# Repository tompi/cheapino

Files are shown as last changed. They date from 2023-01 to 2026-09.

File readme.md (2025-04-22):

Cheapino
========

Probably one of the cheapest split keyboards you can build.

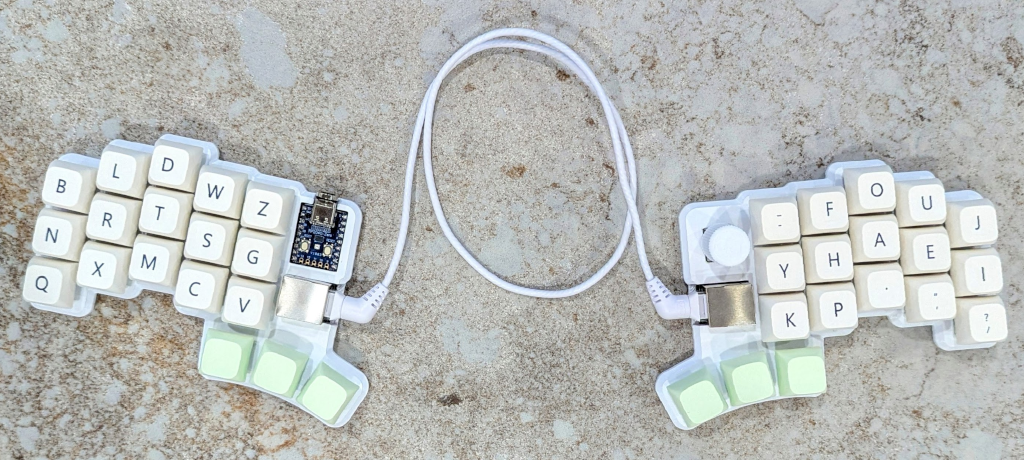
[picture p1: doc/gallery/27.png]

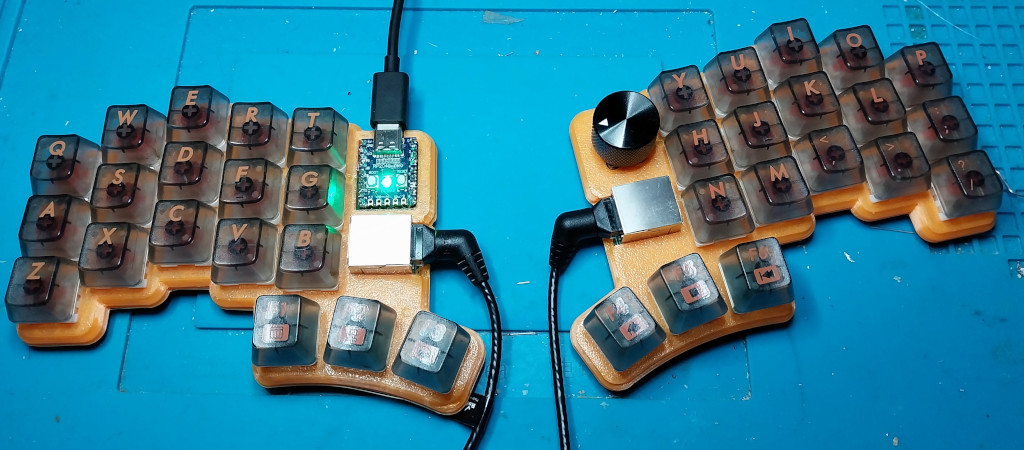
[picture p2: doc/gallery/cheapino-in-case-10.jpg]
V2 in case


This is the result of really enjoying building keyboards,
but not wanting to spend that much money on it.
The pcb is reversible, connected using rj45,
and utilizes a japanese duplex matrix, so only one
mcu is needed. For hotswap I recommend a case(pictured above),
but soldering the switches is of course the cheapest option :)

You want one?
See the [ordering guide](doc/orderingguide.md) for what you need and how to buy it.

See the [build guide v2](doc/buildguide_v2.md) for more details and pictures of how to actually build it.

Some info on the [plate/case solutions](doc/plates_and_cases.md) I know about.

Checkout the [troubleshooting guide](doc/troubleshooting.md) if your Cheapino does not work.

See the [firmware guide](doc/firmware.md) for how to build and customize keyboard firmware.
The cheapino has vial support, or you can build your own QMK to customize EVERYTHING.
Even the onboard RP2040-Zero LED is controllable by QMK...

I added [a few tips and tricks here](doc/tips.md).

[Loads of beautiful build pictures here.](doc/gallery.md)

# License

This work is licensed under a [Creative Commons Attribution license.](LICENSE.txt)

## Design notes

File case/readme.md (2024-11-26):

3D-printed compact case
=======================

If you just want to make small adjustments and generate
your own version, install openscad, and open a scad file
and press F6 to generate. Export->stl to get printable model.

Make sure you install the development snapshot, since the
last official release is hopelessly out of date...
You need to tweak some settings to be able to build
the model efficiently:
 - Go to preferences->advanced and
increase "turn off rendering at" to 3 million.
 - Go to preferences->features and check "manifold"
   - In OpenSCAD version 2024.11.01, "manifold" is under: Advanced -> 3D Rendering -> Backend
   - 

(this will enable multi-thread rendering and speed things
 up dramatically!)

For the slicer, I did not do much experimenting...
Maybe somebody into 3D printing could help me out with
the silicone bumper recesses: removing the supports in
these holes is a pain...

I used 100% infill, since its not that much difference
in time/weight, and I hope that it contributes to a more
compact and better sounding case...

Recipe for re-making this
=========================

1. Export board outline from kicad
2. Open in inkscape, select all and combine
3. For every point: mark(there will be 2) and select "join points": shft+L(shft L
4. Import in openscad
5. Export holes from kicad as svg
6. Create cutouts, and measure position from kicad
7. Import holes, just to check that positions match
8. Comment out holes, generate with F6 and export as stl
9. Import stl files in any slicer to print them

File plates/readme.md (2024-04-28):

Plates
======

The v2-cheapino-left.stl and v2-cheapino-right.stl can be used for version 2 of the Cheapino.
It should be used if you installed hotswap sockets, since you need it to hold switches in place
(they are not soldered then...)

Takes 1-2 hours pers plate to print, depending on settings.
There are holes for screws, but they are a bit narrow, so use a nail or similar,
size depending on your screws, heat it and push it slowly down to expand the screwhole.
The PCB mounting holes are M4 sized, but you probably shouldnt use the entire width.

I guess optimally, I should make a version with M2 inserts that can be melted in(TODO).

The v1 file is a simple plate for just holding the switches in place.
Its suitable for Cheapino v1. Just print 2 and turn one upside down for the other side.

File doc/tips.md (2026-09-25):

Miscellaneous tips and tricks
============================

## First-time builder tips

Building a Cheapino can be challenging for beginners. Here are some key tips based on real user experiences:

### Soldering technique
- **Always use flux** - it's not optional for clean joints, especially on the tiny MCU pins
- Heat the joint, not the solder - touch both the component pin and pad with your iron
- For the MCU: Use a fine tip, work slowly, and clean your iron frequently
- If you make a mistake, don't panic - use solder wick with flux to clean up

### Build order considerations
- Some builders recommend installing hotswap sockets first (if using them) since they're easier to access
- Test fit components before final soldering when possible
- Socket the MCU - it's much easier to replace if needed than desoldering headers

### Desoldering tips
- **Prevention is better than cure** - double-check orientation before soldering
- For desoldering small components: Add fresh solder first (with flux), then use solder wick
- For through-hole components: Use a solder sucker from one side while heating from the other
- **Be gentle** - excessive force can damage PCB traces
- If a trace gets damaged, thin wire can often bridge the connection

### Equipment recommendations
- KSGER T12 soldering iron with temperature control is excellent for beginners (~$25)
- Use chisel tips (T12-K, T12-BC2) for most work, fine conical (T12-I) only for MCU pins
- Good lighting and magnification help immensely
- Take breaks - fatigue leads to mistakes

## Crimper

Can't find that 13.37 cm long dark olive green network cable that would go
perfectly with your Rain Forest GMMK keycaps? Follow @jinchoung's tip and get a
cable crimper:

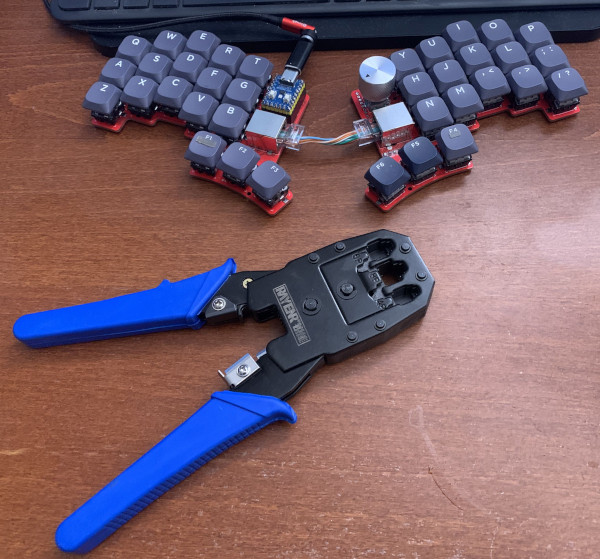
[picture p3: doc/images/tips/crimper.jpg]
Cable crimper


## LED layer indication

Want to indicate active layer using the rp2040-Zero built-in LED?
I tried this and found it a bit annoying... If you want to try, there
is some code here: https://github.com/tompi/qmk_firmware/blob/67aa22818e2be422abdb32fc918c2b6757137a4e/keyboards/cheapino/cheapino.c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
Follow the firmware guide for compiling, and uncomment the layer code above.

## Use the spare PCB as a gaming pad with a rotary encoder

PCB orders come in fives, so you'll end up with a spare half. I turned mine into a
one-handed gaming pad and wired an EC11 rotary encoder straight into the unused
RJ45 pads to use as a quick layer switcher.

The stock firmware already reads the encoder over these lines, so no firmware
changes are needed. Just wire it up and map it in Vial.

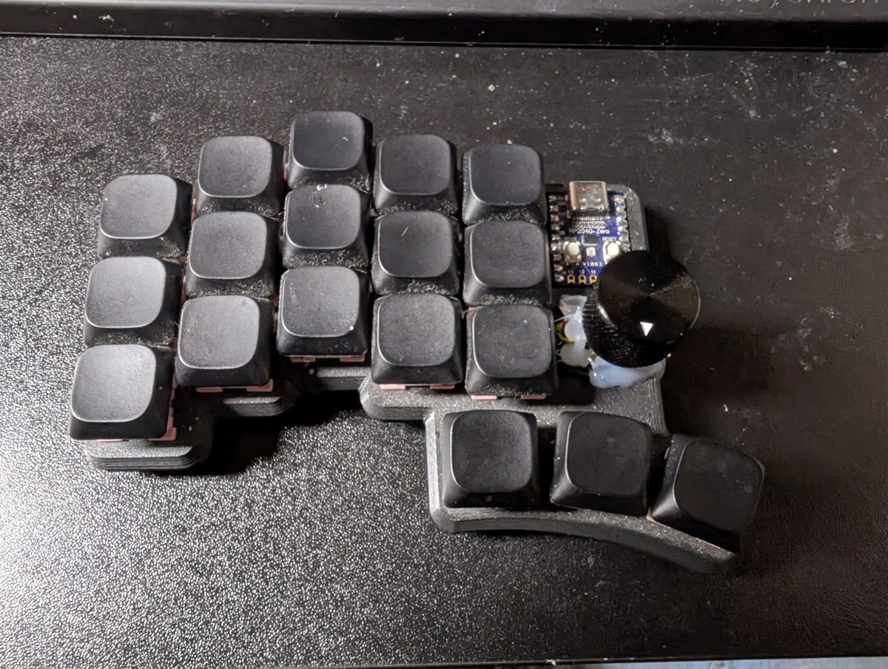
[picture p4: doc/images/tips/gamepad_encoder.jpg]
Gaming pad with encoder


Wiring, with the RJ45 pads viewed from the top and the RP2040 above them:

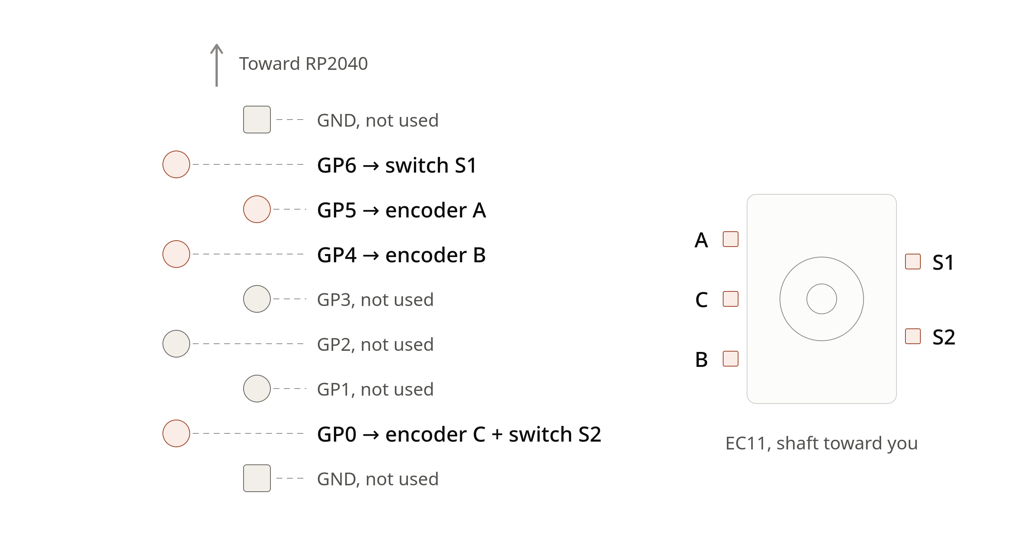
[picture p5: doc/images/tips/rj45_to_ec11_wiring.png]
RJ45 to EC11 wiring


| RJ45 pad | EC11 pin |
|---|---|
| GP6 | S1 (switch) |
| GP5 | A |
| GP4 | B |
| GP0 | C (common) and S2 (switch) |

GND, GP1, GP2 and GP3 aren't used. C and S2 share GP0, so bridge them on the
encoder side and run a single wire.

Tips:
- If the encoder turns the wrong way, just swap the clockwise/counter-clockwise
  keycodes in Vial rather than rewiring A and B.
- The EC11 is smaller than the RJ45 jack, so it fits in the same spot without
  modifying the case. A blob of hot glue holds the encoder and wires in place.
- Pairs really well with the [LED layer indication](#led-layer-indication) tip
  above. I cycle through 4 layers with the encoder and use a different LED colour
  per layer (red, green, blue, yellow) so you can tell at a glance where you are.

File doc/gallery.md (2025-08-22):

Cheapino gallery
================

Send me a picture of your Cheapino!

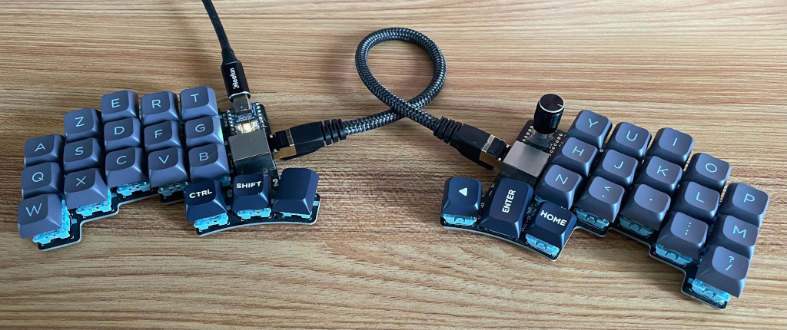
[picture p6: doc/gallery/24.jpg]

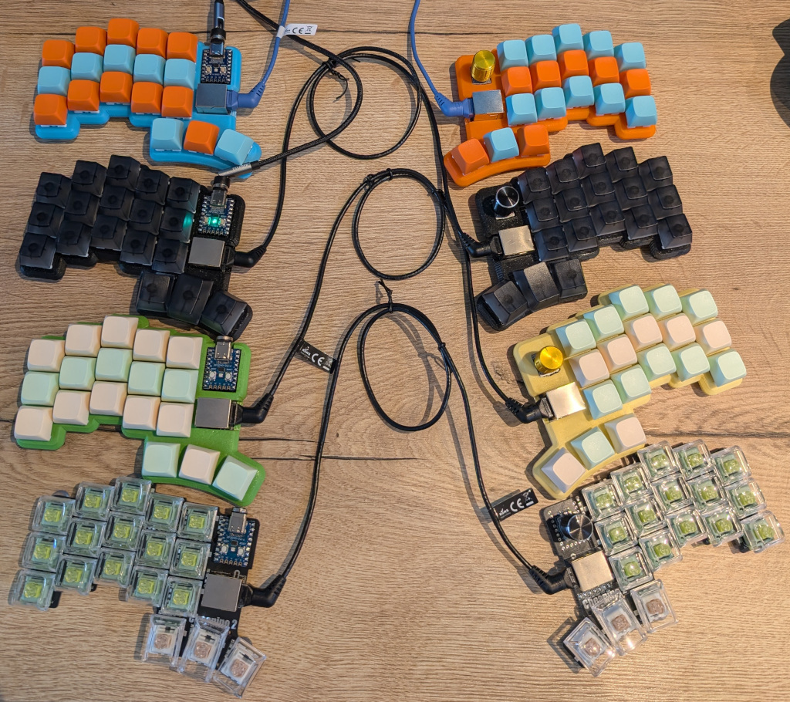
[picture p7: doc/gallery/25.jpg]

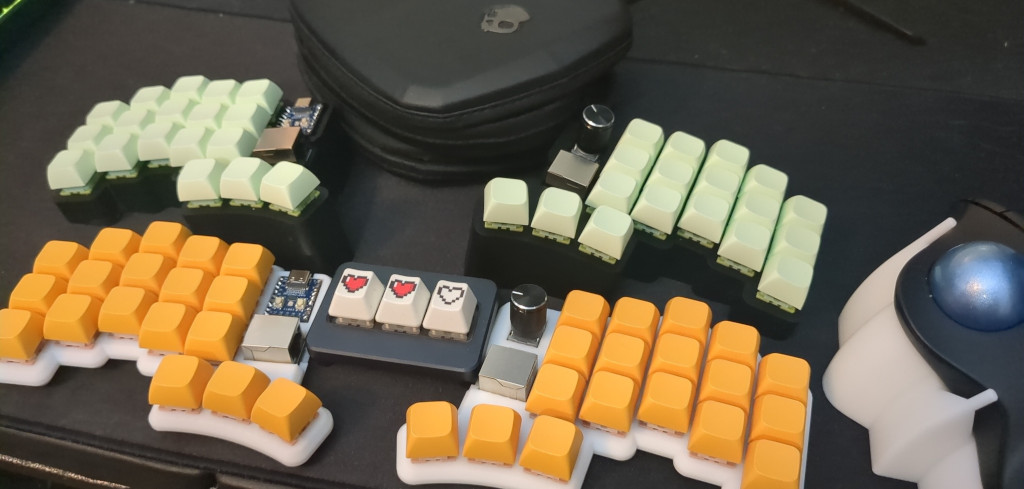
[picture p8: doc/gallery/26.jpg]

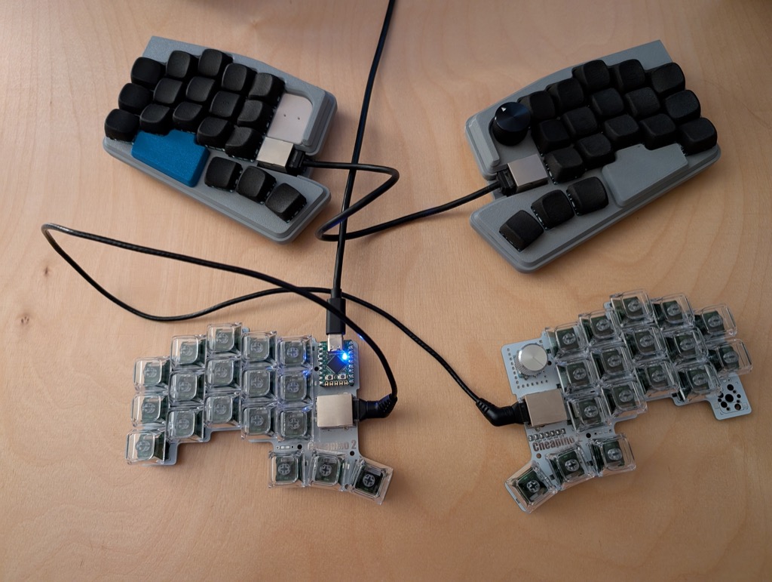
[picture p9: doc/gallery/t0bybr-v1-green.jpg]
V1 with green switches

V2
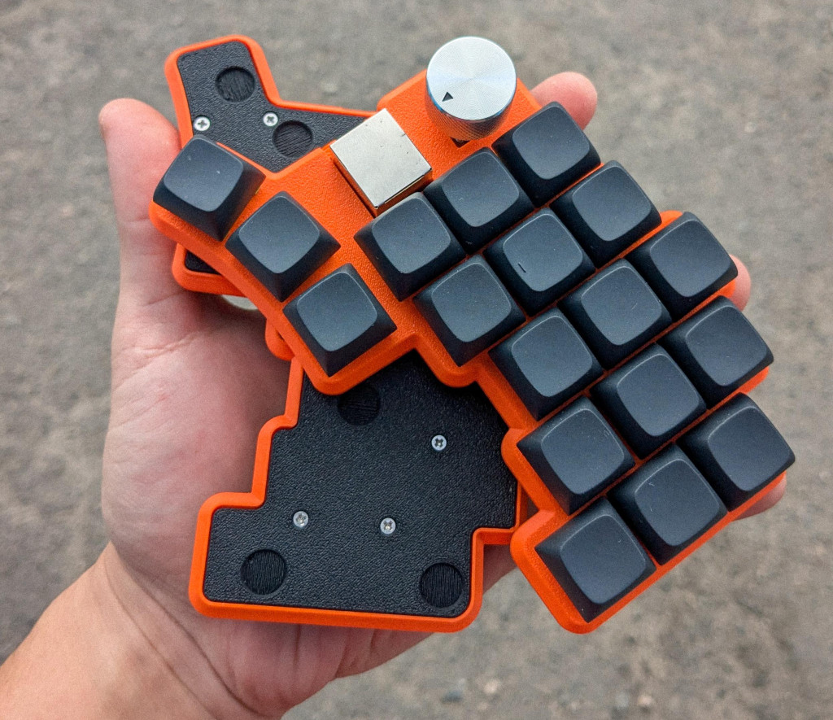
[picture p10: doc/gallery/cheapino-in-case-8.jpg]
V2 in case

V2 in case
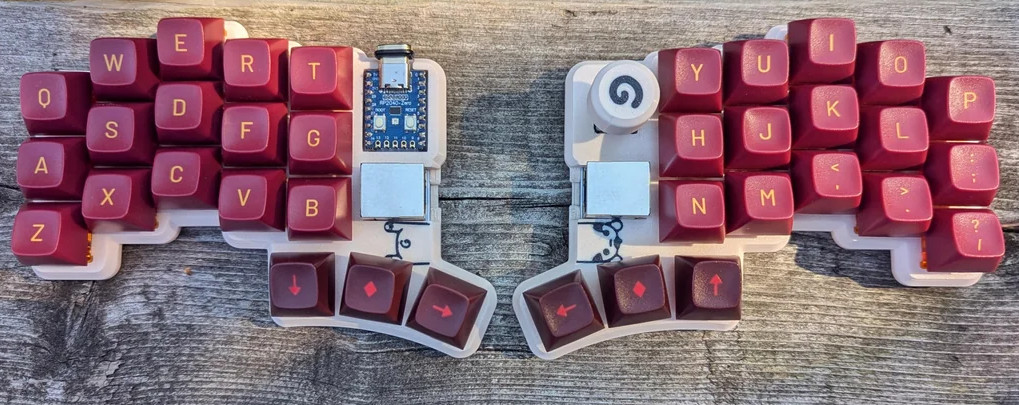
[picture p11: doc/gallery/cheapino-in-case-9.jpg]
V2 in case

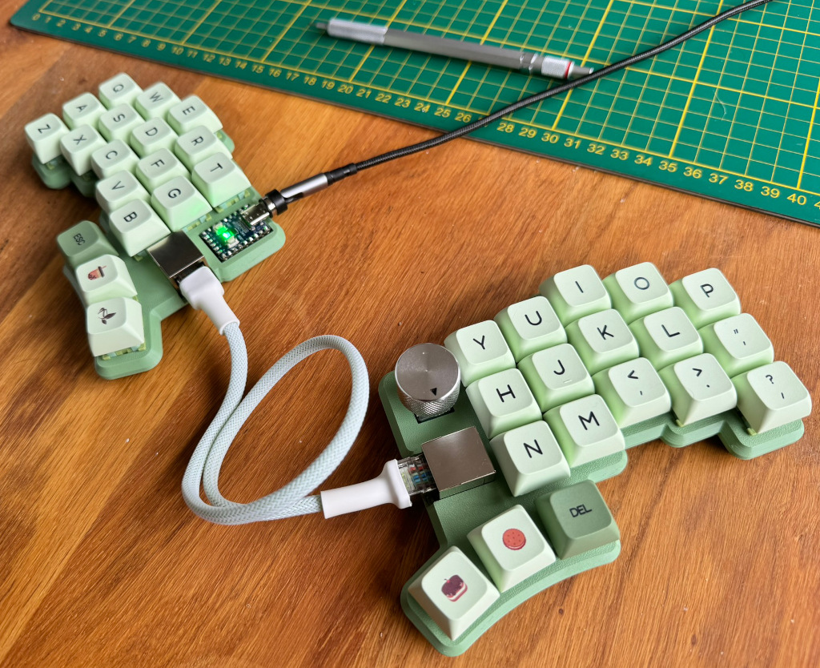
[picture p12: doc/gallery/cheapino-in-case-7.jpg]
V2 in case

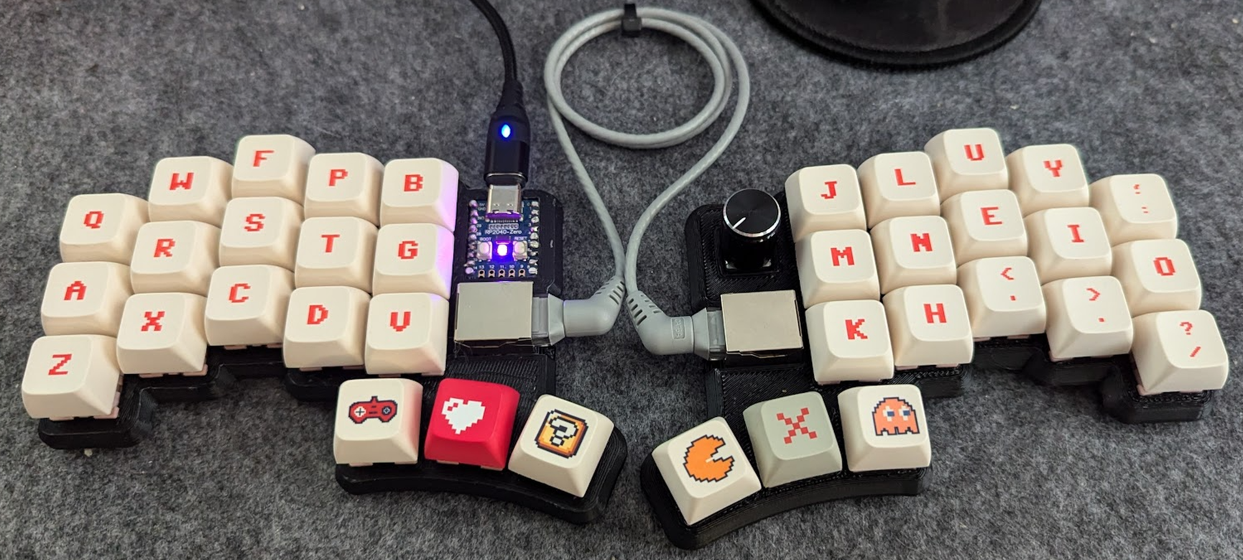
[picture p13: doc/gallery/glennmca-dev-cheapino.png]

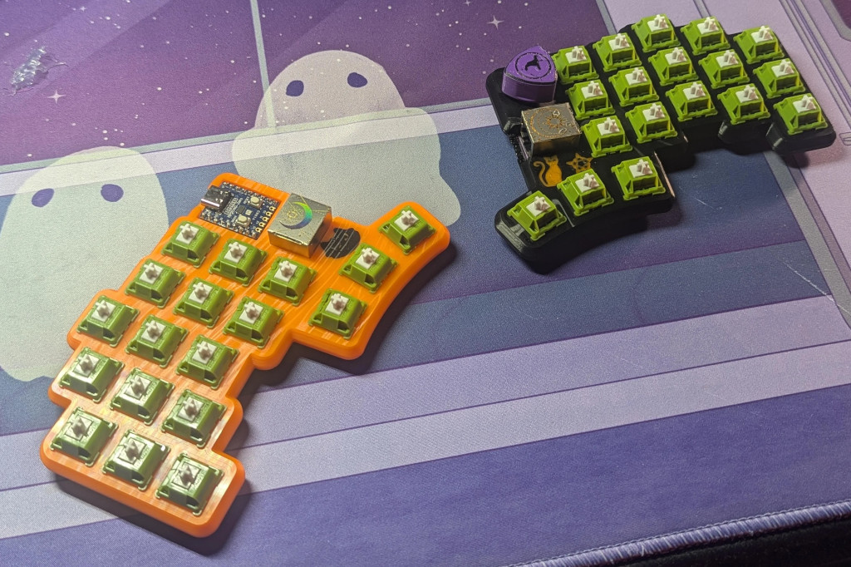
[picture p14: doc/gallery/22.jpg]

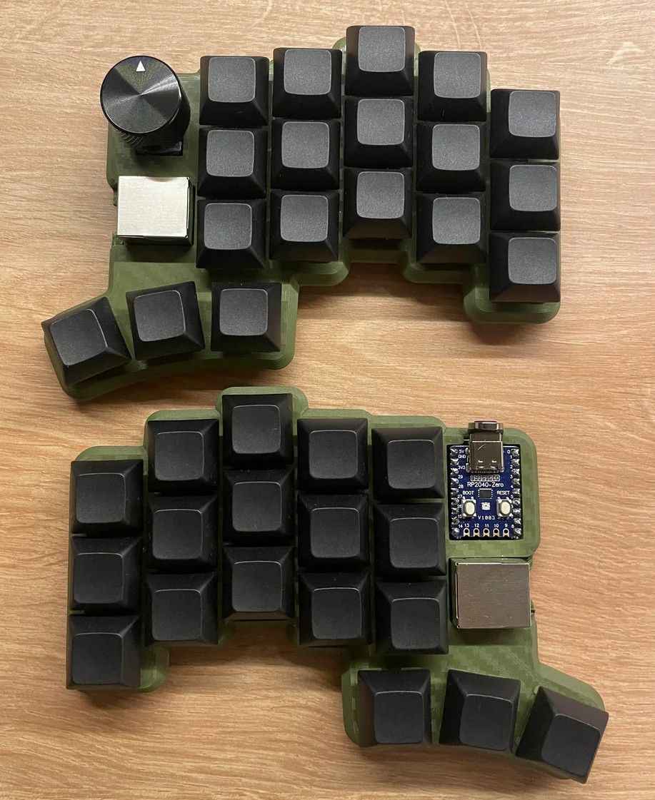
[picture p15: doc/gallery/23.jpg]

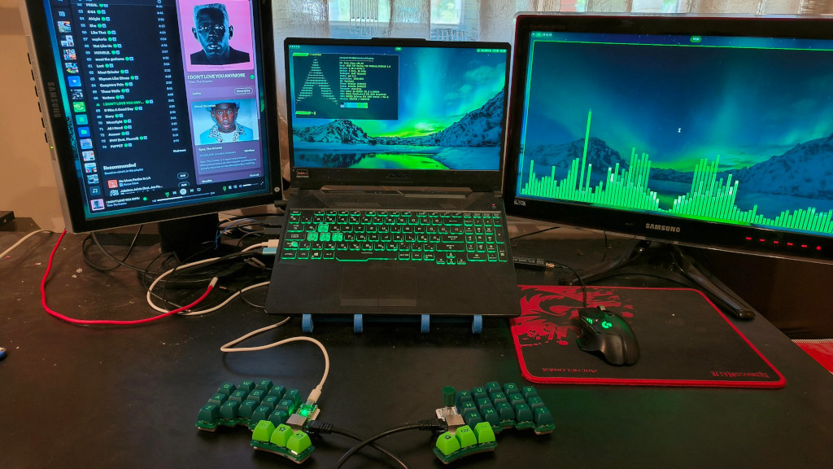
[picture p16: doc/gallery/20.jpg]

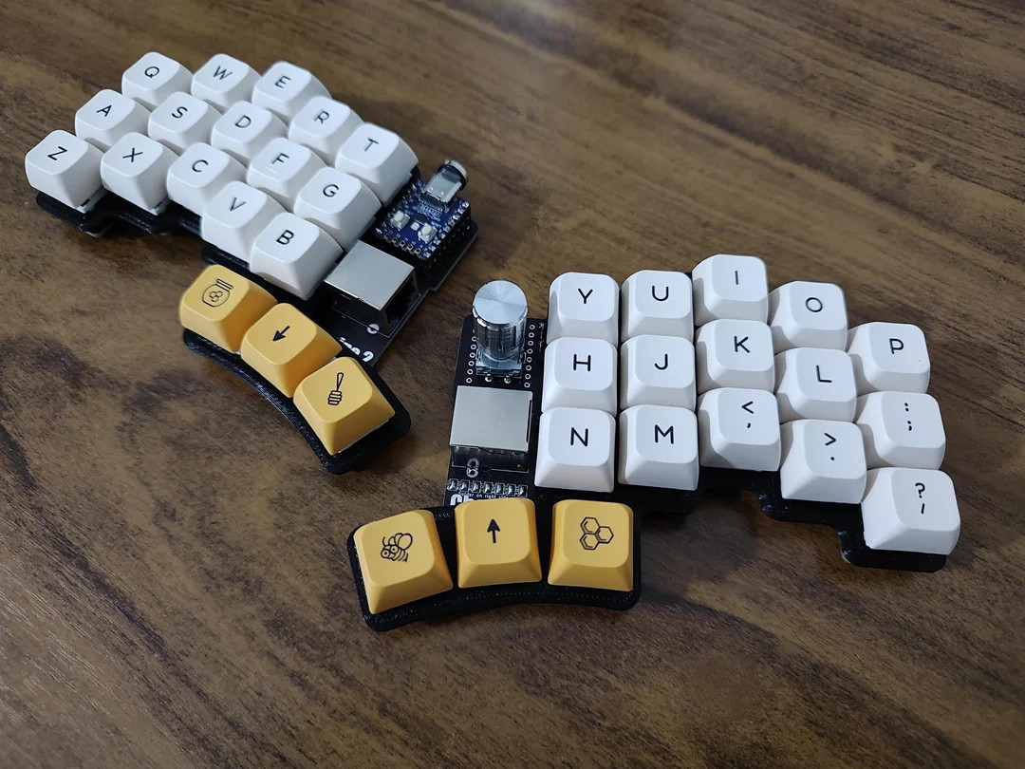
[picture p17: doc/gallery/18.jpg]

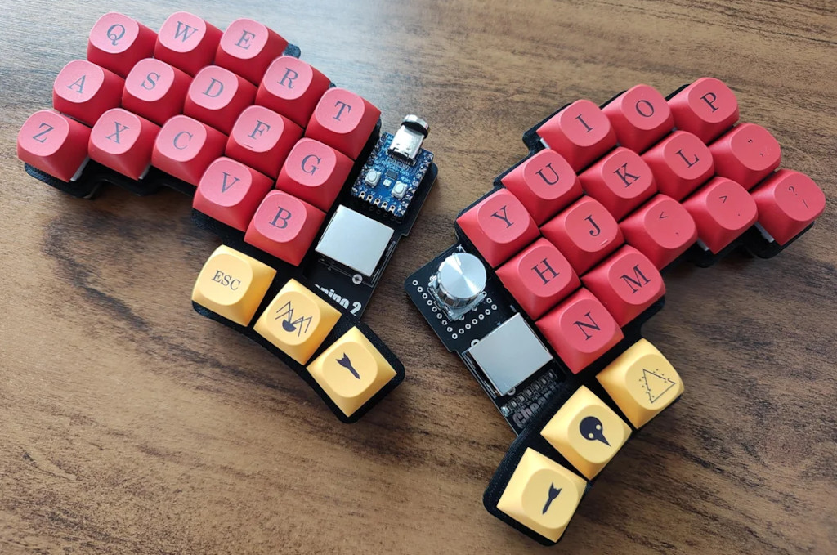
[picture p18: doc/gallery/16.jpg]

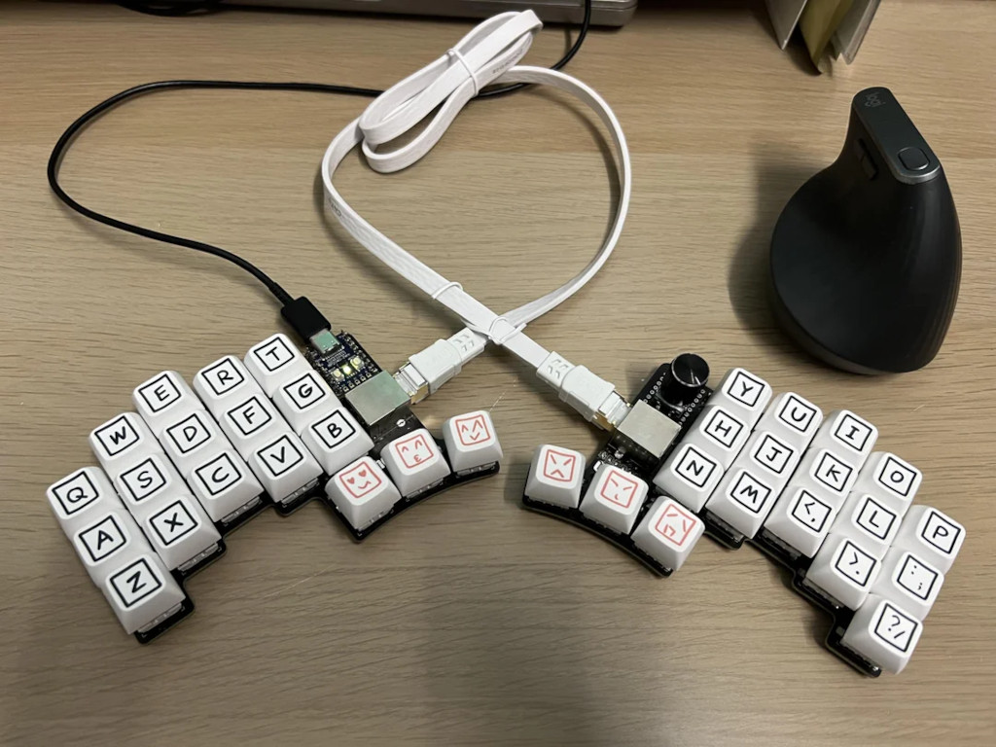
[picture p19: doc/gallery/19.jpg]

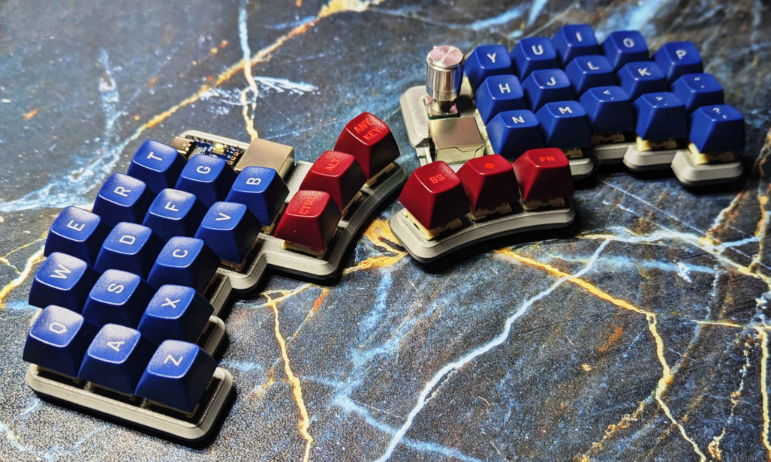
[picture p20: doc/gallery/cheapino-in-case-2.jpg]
V2 in case

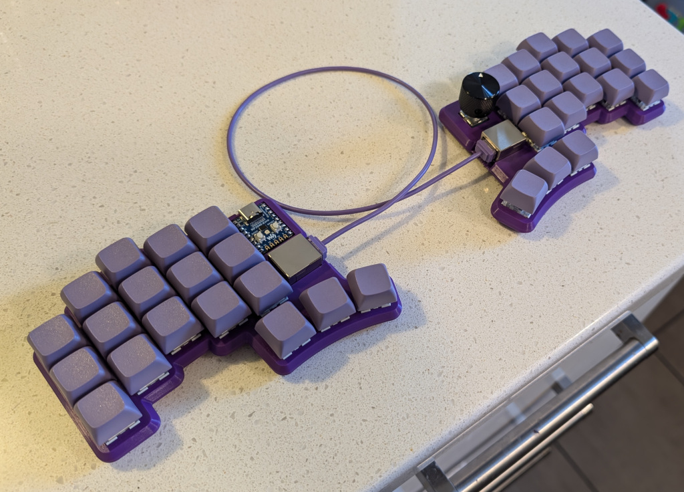
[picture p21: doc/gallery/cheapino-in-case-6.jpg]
V2 in case

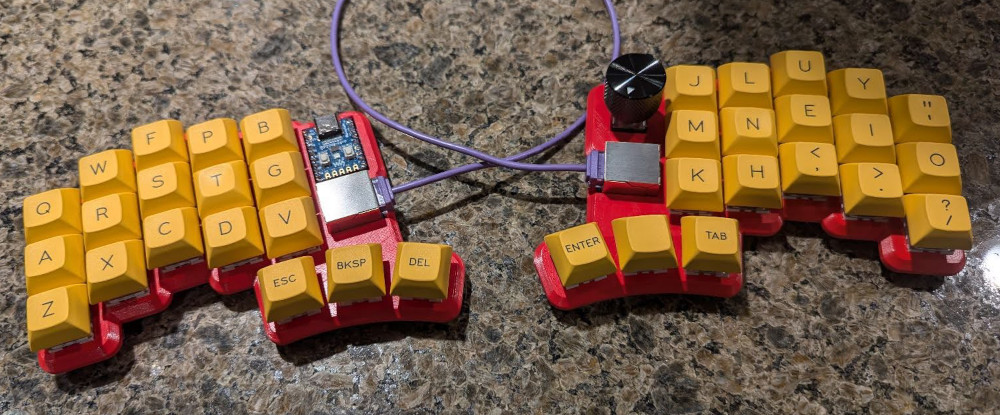
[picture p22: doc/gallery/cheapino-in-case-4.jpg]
V2 in case

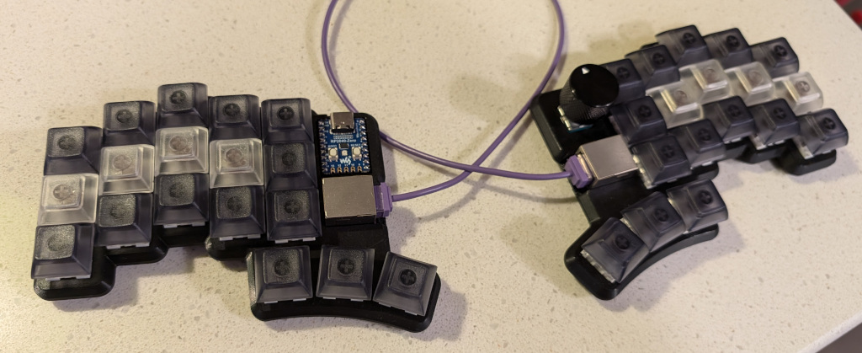
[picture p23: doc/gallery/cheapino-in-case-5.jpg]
V2 in case

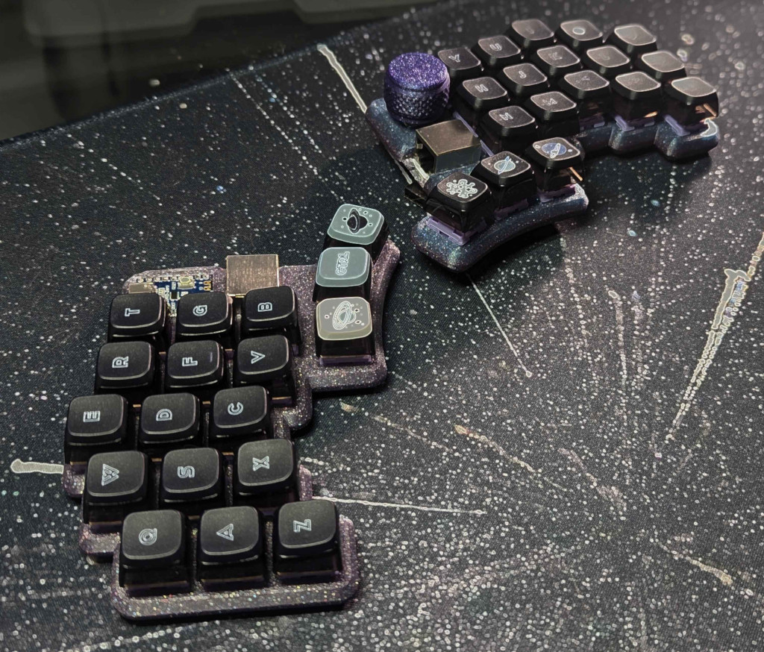
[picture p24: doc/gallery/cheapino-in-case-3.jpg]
V2 in case

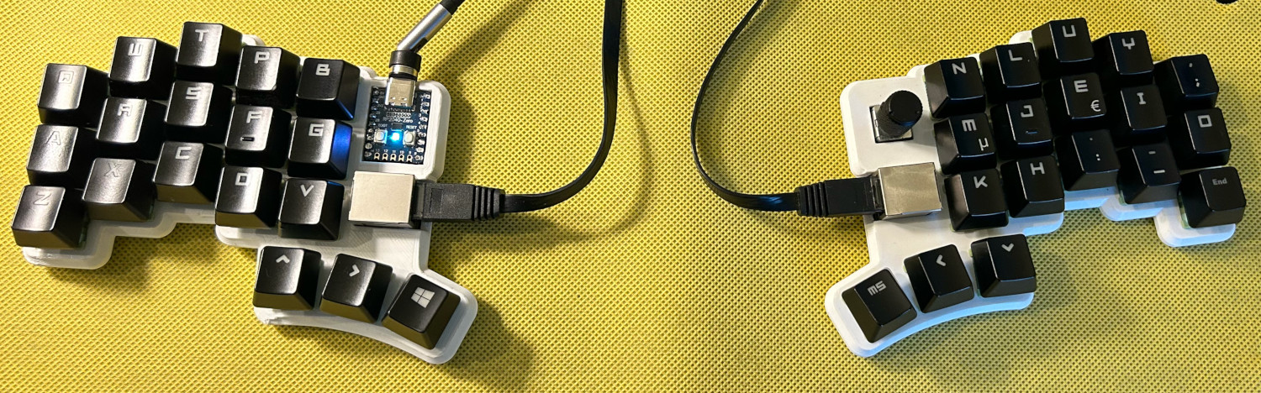
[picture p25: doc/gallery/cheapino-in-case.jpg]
V2 in case

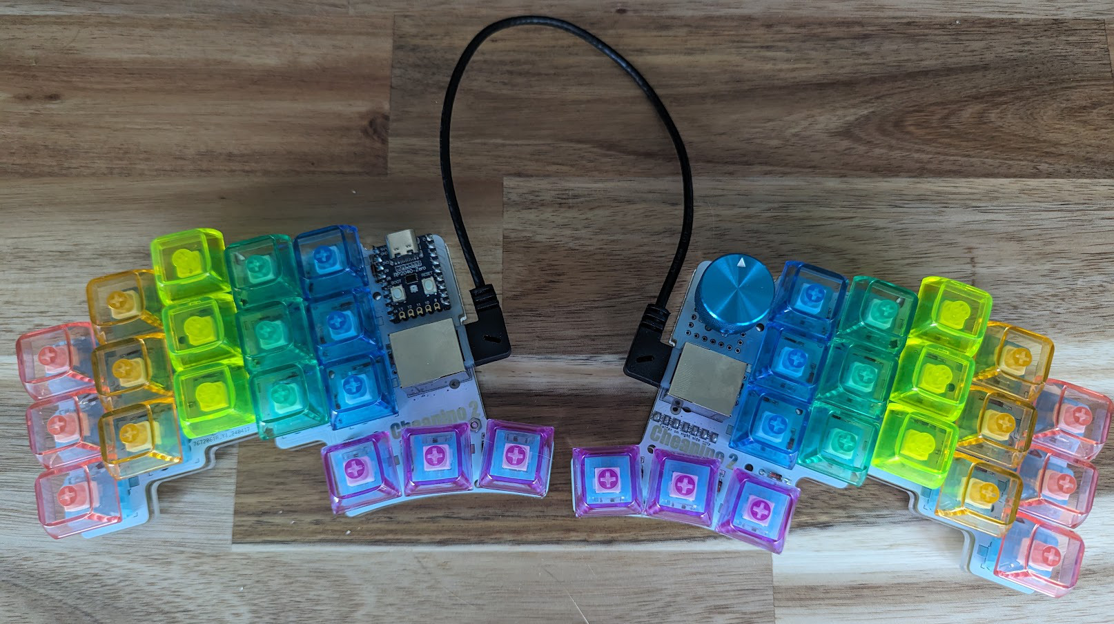
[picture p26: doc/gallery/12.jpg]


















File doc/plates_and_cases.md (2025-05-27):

Plates and cases
================

[This simple plate](../plates/plate.stl) works for both v1 and v2.
It has no support or screw inserts, so not ideal for hotswap
builds, but does the job.

Case

## V2

This is the basically the same plate with a few supports
placed where the mounting holes are. I have not tested to
actually screw this on, Im just using it without screws:
[left plate with supports](../plates/cheapino-plate-left.stl)
[right plate with supports](../plates/cheapino-plate-right.stl)

This is a case I made, very compact, almost no empty space inside:
https://www.thingiverse.com/thing:6661648

Lots of pictures here: https://imgur.com/a/cheapino-2-case-R4ialST

Case

[A bit unfinished build guide for this case here.](case_buildguide.md)

TheMadClover made 2 really nice looking case options, one tented,
and one flat, check them out here:
https://www.printables.com/model/879047-two-case-designs-for-cheapinov2-split-ergo-keyboar
Case

## V2 Sandwich Case

There’s also a sandwich case design that you can order together with the main PCB. It’s important to order the top plate with the default 1.6 mm thickness so that it clicks firmly into the MX switches. The top plate is held in place by the switches and doesn’t require spacers or screws for securing.

Case

The bottom plate has mounting holes aligned with the main PCB and can be secured using 7 mm long M2 flathead screws and nuts. In this setup, the bottom plate sits tightly against the sockets. Example parts from AliExpress:
- https://www.aliexpress.com/item/1005002525560135.html
- https://www.aliexpress.com/item/4000602853448.html

Case

## V1

This is a VERY nice case with built-in support for tenting
and a travel solution:
https://www.printables.com/model/835134-cheapino-split-keyboard-case

Case

This is a case for v1 with a simple tenting solution:
https://www.printables.com/model/541536-cheapino-case-with-basic-tenting

Case

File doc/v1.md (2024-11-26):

Cheapino V1 (Obsolete)
========

The V1 and V2 are not that different, they have the same key layout, but V2 has a lot of minor improvements, so I suggest building that!

Here are some V1 images:

Cheapino by finex

https://www.reddit.com/r/ErgoMechKeyboards/comments/12xg4u7/built_the_cheapino/
Cheapino by TentacleSenpai69

https://www.reddit.com/r/ErgoMechKeyboards/comments/13c274r/cheapino_build/
Cheapino by Palbi

https://discuss.tchncs.de/post/410101
Cheapino by PixelPrimer

https://discuss.tchncs.de/post/852362
Cheapino by Chraccoon

https://lemmy.world/post/2080485
Cheapino by Hansamann

https://lemmy.world/post/2832967
Cheapino by createkarma

Cheapino by ??

https://www.reddit.com/r/ErgoMechKeyboards/comments/18i5jpu/first_build_cheapino/
Cheapino by lydomixian

https://www.reddit.com/r/ErgoMechKeyboards/comments/18zb3l1/first_build_finally_cheapino/
Cheapino by u/Tech-Buffoon

https://lemmy.world/post/2480447
Case by Chraccoon
Printable file  for the case here: https://www.printables.com/model/541536-cheapino-case-with-basic-tenting

Probably the cheapest tenting solution: https://www.reddit.com/r/ErgoMechKeyboards/comments/16s3yb2/cheapino/
Cheapino by @JordanNiphan

@keyboard-magpie made a plate which will help position the switches: [plate.stl](../plates/v1_plate.stl)

@ggppjj made some useful modifications to miryoku and enabled LED for that as well here: https://github.com/ggppjj/qmk_firmware/releases

Drawbacks:

* V1 only: Without a plate, its pretty difficult to solder switches straight. I made a small helper "fork" to hold each column in place when soldering. Check the build guide for a link to a really good 3D printed fork.
* RJ45 cables are a bit rigid, so they do not lay down on the table nicely like audio cables.
* There is no official qmk support, you need to compile from my branch manually... Keymap can be edited in qmk configurator though.

Cheapino PCB

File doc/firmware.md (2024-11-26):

Firmware guide
==============

The release section contains pre-built firmware for Vial, a minimal qwerty build
and miryoku with either qwerty or colemak.

There are 2 main routes to tweak your own keymap, either flash the vial firmware and use the vial web or desktop ui
to configure the keyboard, or setup qmk for compiling locally.

In either case, there are A LOT of options to tweak...
Check out the links at the bottom for further reference.

# Configuring using vial

This is the easiest way of setting up your keyboard:

1. Download cheapino_vial.uf2 file for your release([v2 is here](https://github.com/tompi/cheapino/releases/download/v2.0/cheapino_vial.uf2))
2. Put your rp2040-zero in dfu mode by holding boot button while you plug in usb c
3. The rp2040-zero should show up as a usb drive
4. Drag and drop uf2 file to the usb drive that popped up after 2.
5. The rp2040 will now reboot really fast, so you might get an error message, even though it went well
6. Surf to https://vial.rocks/ and start configuring
7. OR, if you want a local tool: ownload vial from here: https://get.vial.today/download/

All keys and encoder actions should be configurable in the Vial program while
your keyboard is configured. There is also loads of parameters to tweak for optimal performance
for your style...

Vial in action

# Setting up and compiling qmk

For most flexibility, you want to compile the qmk firmware yourself.

Unfortunately, the cheapino firmware is not merged into the official qmk repository,
so there are a few extra steps to setting up qmk for compiling cheapino.
This is the recipe for windows(for mac/linux, install qmk the recommended way and jump to step 3):

1. Install qmk msys from https://msys.qmk.fm/
2. Inside qmk msys, type qmk setup - this will create a qmk_firmware folder that has cloned the main branch of qmk from git.
3. Run this command(make sure you are in the "qmk_firmware"folder) to add a reference to the cheapino qmk fork:
```sh
git remote add tompi https://github.com/tompi/qmk_firmware
```
4. Run this command to actually fetch the code(replace "cheapinov2" with "cheapino" if you are using cheapino v1 pcbs):
```sh
git fetch tompi cheapinov2
```
5. Run this command to switch local files to the cheapino variant(again, replace "cheapinov2" with "cheapino" if using v1 pcbs):
```sh
git checkout tompi/cheapinov2
```
6.Now you should be able to make and flash with:
```sh
qmk flash -kb cheapino -km default
```
7. When qmk says "Waiting for drive to deploy", hold boot btn while pressing reset on the rp2040, which should put it in dfu mode, and qmk will then flash.

To make your own version and customize it:

1. Copy the "keyboards/cheapino/keymaps/default/" folder to "keyboards/cheapino/keymaps/thebestkeymap/".
2. Upload the file keymap.json (that you copied) to https://config.qmk.fm/
3. Go wild with configuring up to 15 layers...
4. Press the download button.
5. Move the downloaded json file to "keyboards/cheapino/keymaps/thebestkeymap/keymap.json"
6. Build and flash the keymap with:
```sh
qmk flash -kb cheapino -km thebestkeymap
```
7. When qmk says "Waiting for drive to deploy", hold boot btn while pressing reset on the rp2040, which should put it in dfu mode, and qmk will then flash.

(and you guessed it, you can choose to call it something else than thebestkeymap)

QMK Configurator

To help learn your keymap, @omark96 made this tool that works on windows: https://github.com/omark96/qmk_keymap_overlay

## Encoder customization

Tweaking the encoder actions is supported in vial, but needs to be done in the keyboards/cheapino/encoder.c file for local qmk build, they are not part of the keymap.
(you dont HAVE to be a programmer to change it, but you may call yourself a novice programmer once you do...)
In the method called "turned", there are actions defined for multiple layers, this one is tweaked for my personal layer...
The "else" section at line 26, will send page down for clockwise encoder turns, and page down for counter clockwise.
The first if, line 20, sends volume up/down if you are on layer 6.

The encoder push is defined to media pause/play in the "clicked" method on line 15.
Feel free to remap it to different keys depending on layers, like the turns are done.
TBH, I dont really use the encoder much, so I didnt spend much time tweaking this...

Once you change the encoder file, run the command from step 6 and 7 to deploy changes to your keyboard.

# Build your own Miryoku

There is a branch of miryoku you can use for local builds here:
https://github.com/tompi/qmk_firmware/tree/cheapinov2-miryoku

You need to build this with the miryoku keymap, so somethin like this:
```sh
qmk flash -kb cheapino -km manna-harbour_miryoku
```

To build with different layouts, follow the docs here(you can skip to the build section if you use my branch):
https://github.com/manna-harbour/miryoku_qmk/tree/miryoku/users/manna-harbour_miryoku

# Miryoku with vial

@glennmca used VIAL to build a Miryoku layout, documented here:
https://gist.github.com/glennmca-dev/ddddcafe46dd1e2e36ed853bf55077e3

# Compile QMK with docker

I did not try this, but seems way easier than mucking about with installing a trillion dev-dependencies:
https://github.com/qmk/qmk_firmware/blob/master/docs/getting_started_docker.md

# References for keymaps and qmk tweaking

* Miryoku is a very well thought out layout: https://github.com/manna-harbour/miryoku
* @gtreuer has a lot of tricks up his sleeve: https://getreuer.info/posts/keyboards/tour/index.html
* Some inspiration for making your own keymap: https://keymapdb.com/
* Check out colemak-dh if you are curious about other layouts than qwerty: https://colemakmods.github.io/mod-dh/
* For practicing, https://www.keybr.com/ and https://monkeytype.com/ are nice
* If you are on reddit, you should join https://www.reddit.com/r/ErgoMechKeyboards/

Good luck!

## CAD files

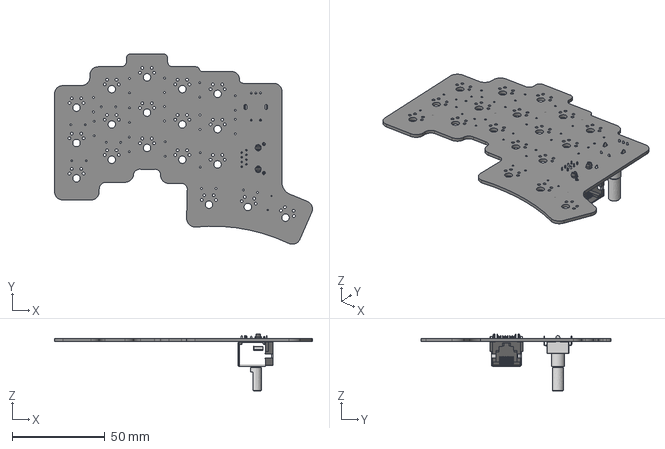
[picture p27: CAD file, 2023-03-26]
pcb/cheapino-right.step
139.0 x 102.6 x 30.4 mm
_autosave-cheapino PCB

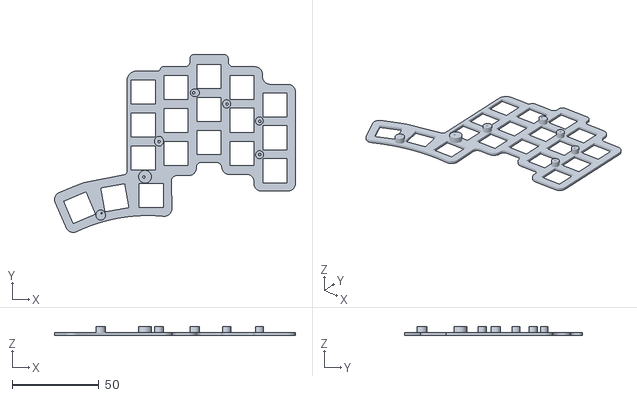
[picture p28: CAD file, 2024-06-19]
plates/cheapino-plate-left.stl
138.9 x 102.5 x 5.00

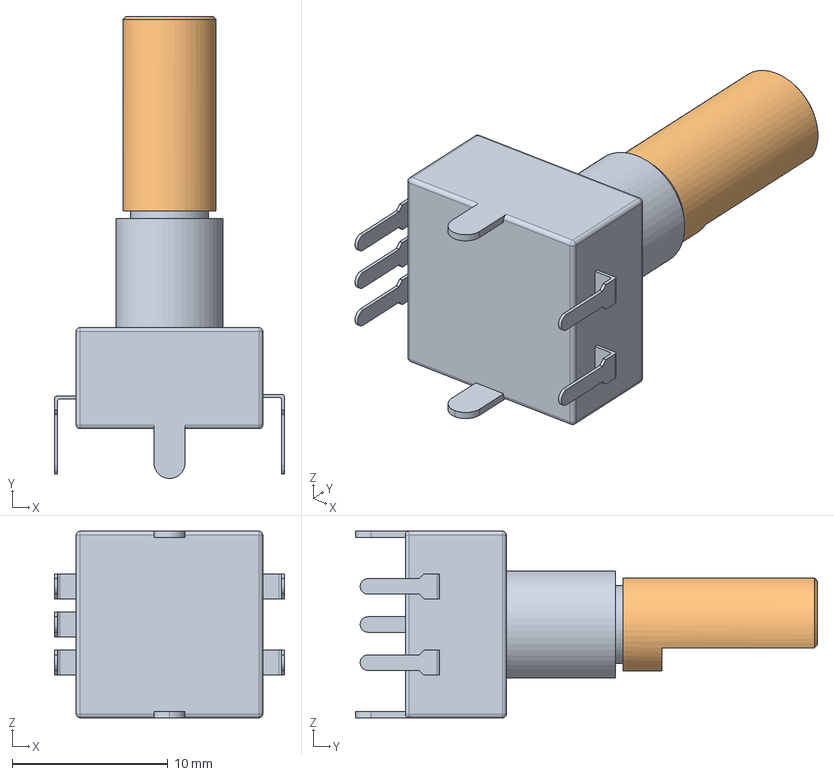
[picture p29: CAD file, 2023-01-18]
project_libraries/project-3dmodels/ec11.stp
14.8 x 29.7 x 12.0 mm

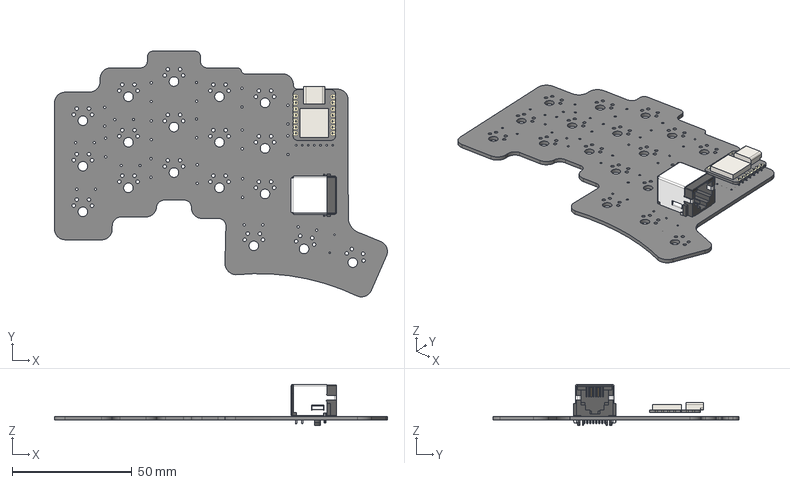
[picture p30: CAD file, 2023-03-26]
pcb/cheapino-left.step
139.0 x 102.6 x 17.3 mm
_autosave-cheapino PCB

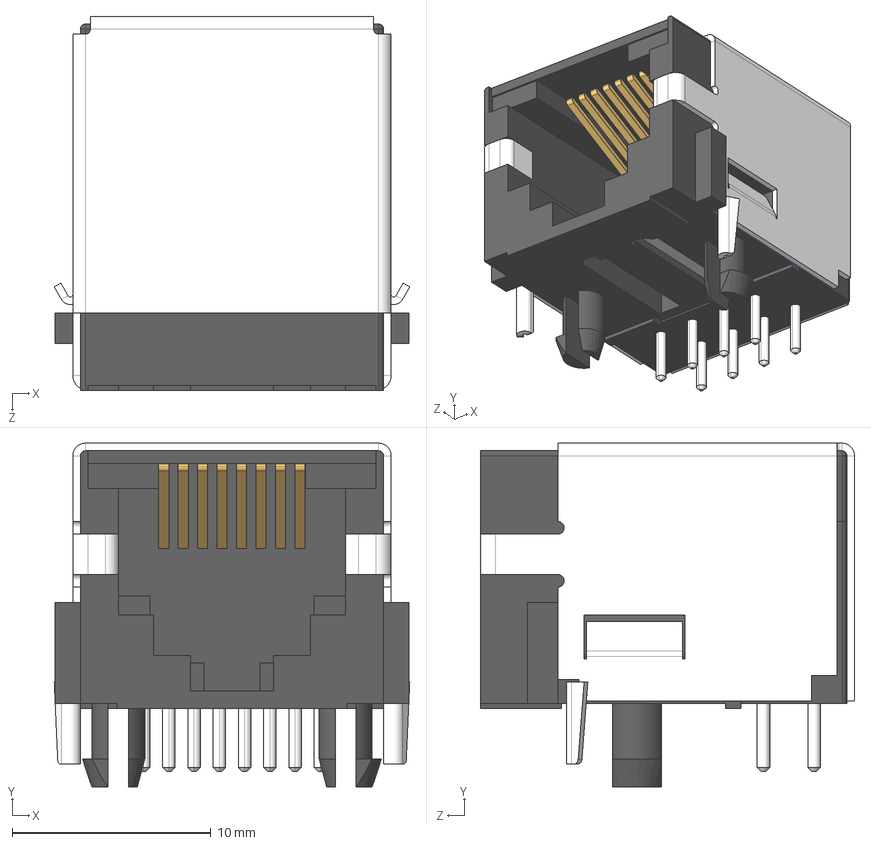
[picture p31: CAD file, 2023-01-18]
project_libraries/project-3dmodels/RJ45-8Z4.stp
17.9 x 17.3 x 18.8 mm

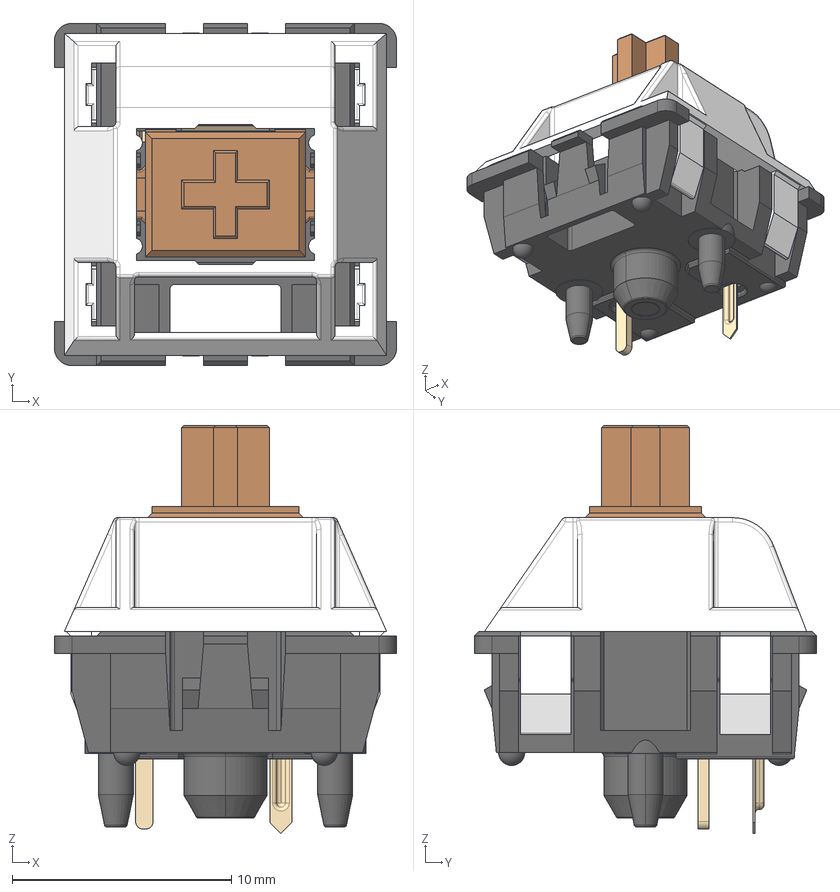
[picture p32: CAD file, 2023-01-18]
project_libraries/project-3dmodels/SW_Cherry_MX_PCB.stp
15.6 x 15.6 x 18.6 mm

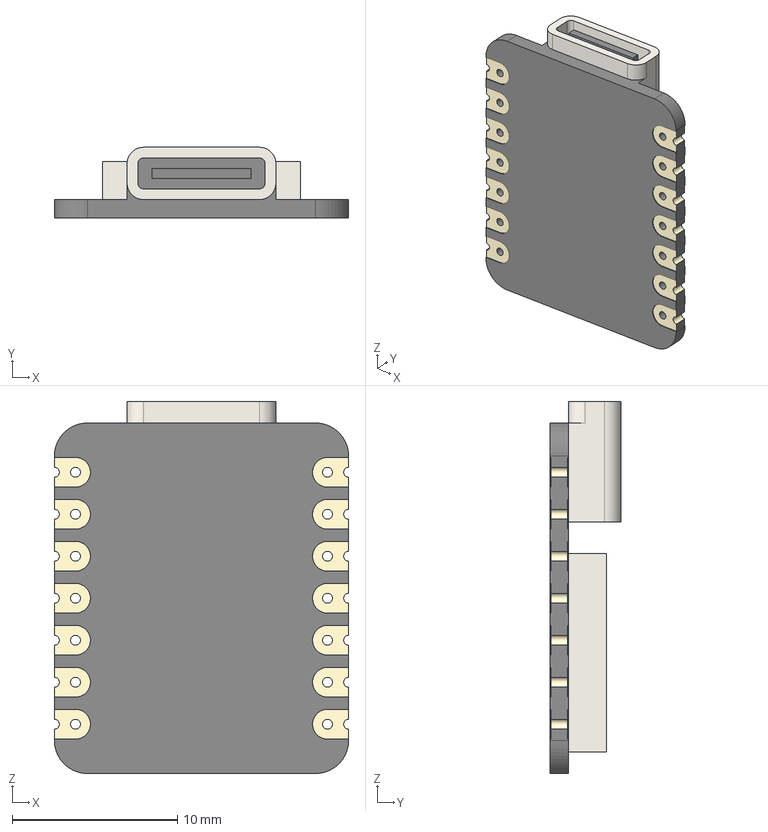
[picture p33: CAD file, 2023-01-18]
project_libraries/project-3dmodels/seeduino.stp
17.8 x 4.27 x 22.5 mm

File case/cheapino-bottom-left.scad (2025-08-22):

use <modules.scad>

// height = 95.1738;
// width = 132.6134;
step = 0.04;

// hotswap socket is ~1.75 high at the highest.
// magsafe ring is 0.4 high
// 2.5 will leave 0.35 at the thinnest(between hotswap and magsafe).


$fn = $preview ? 10 : 50;

// Rotate so you dont need to do that in extruder
translate([0,0,2.5])
rotate([0,180,0])
mirror()
{
    difference() {
      bottom();
        //translate([13,11,2.1])
        // magsafe_ring();

        // The exported board from KiCad, for debug
        //translate([0,0,0])
        // board();

        switches(true);

        diodes();

        rj45();

        mcu();

        encoder();

        mounting_holes();

        // Inserts for silicone bumpers
        translate([0, -5, 0]) bumper();
        translate([0, -46, 0]) bumper();
        translate([13, -61.5, 0]) bumper();
        translate([-29.5, -54.6, 0]) bumper();
        translate([-63.3, 12.6, 0]) bumper();
        translate([-63.5, -24.3, 0]) bumper();
        translate([-101, -41.2, 0]) bumper();
        translate([-101, -3, 0]) bumper();

        // Inserts for magnets near MCU
        translate([24,17,0]) magnet();
        translate([24,-18,0]) magnet();


        // Inserts for magnets near bottom
        translate([-43,36.8,0]) magnet();
        translate([-43,-0.2,0]) magnet();
    }
}

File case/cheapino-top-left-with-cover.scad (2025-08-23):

height = 95.1738;
width = 132.6134;
step = 0.06;
$fn = $preview ? 10 : 50;

height_translation = 0;
include <modules.scad>

difference() {
  case();
  linear_extrude(4.1) offset(delta=0.45) base();

  // For debug: comment out above 3 lines and comment in this
  //translate([0,0,4.1])
  //      board();

  translate([0,0,top_of_pcb]) switch_holes();

  // Diodes
  translate([0, 0, top_of_pcb]) diodes();

  // RJ45 socket
  color("cyan") {
    translate([29.2, -10.6, 4.1])
      linear_extrude(10)
      square([30, 16.6]);

    translate([45, -5.8, 2.5])
      linear_extrude(10)
      square([15, 7]);
  }

  mcu_cutout();
  // mounting holes
  mounting_hole_inserts();

}

// RJ45 socket cover
color("purple") {
  difference() {
    // x = front/back, y = left/right, z = top/down
    // -0.8 is thickness of the back cover
    // -10.6 is the initial size of left/right
    // 8.1 is the start of the case
    translate([29.2 + (-0.8), -10.6 - 2, 8.1])
      // width = front/back, depth = left/right, height = top cover
      // Add thickness of 4. 2 left 2 right.
      // (reset mcu_height) + 2 is for top cover thickness
      roundedcube([30 - 8, 16.6 + 4, rj45_height - 2], false, cover_radius, "xmax");

    // To craete a hole, repeat the difference() for initial rj45
    translate([29.2, -10.6, 8.1])
      // 0.5 for tolerance
      linear_extrude((rj45_height - 4.1) + 0.5)
      square([30, 16.6]);
  }
}

// MCU cover
color("green") {
  difference() {
    // x = left/right, y = front/back
    // 8.1 is the start of the case
    translate([29.5 - 1, 10.2 - 3, 8.1])
      // To set the cube height
      // width = left/right, height = front/back
      // Add thickness of 3. 2 outer, 1 inner.
      // (reset mcu_height) + 2 is for top cover thickness
      roundedcube([19.5 + 3, 26 + 3, (mcu_height - 4.1) + 2], false, cover_radius, "xmax");

    // To craete a hole, repeat the difference() for initial mcu cutout
    translate([29.5, 10.2, 8.1])
      linear_extrude(mcu_height - 3.1)
      square([19.5, 25]);

    // Repeat USB C port opening
    translate([34.25, 25.2, 8.1])
      linear_extrude(mcu_height - 3.1)
      square([10, 20]);
  }
}

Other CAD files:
plates/cheapino-plate-right.stl
plates/v2_cheapino-left.stl
plates/v2_cheapino-right.stl
case/cheapino-bottom-right.scad
case/cheapino-top-left.scad
case/cheapino-top-right-with-cover.scad
case/cheapino-top-right.scad
case/cheapino-top.scad
case/cheapino.scad
case/hotswap.scad
case/minimal-plate.scad
case/modules.scad
case/plate.scad
plates/openscad_wip/cheapino.scad

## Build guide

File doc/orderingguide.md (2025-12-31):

# Cheapino components buying guide

## Introduction

The parts list(BOM) is the same for both v1 and v2, except for optional hotswap sockets for v2.
You need to buy from at least 2 parties, the PCB needs
to be custom made, the other parts can be ordered from any electronics supplier.

I have a small amount of v2 PCBs, and components, so feel free to drop me
a mail and ask for a quote, I might be able to send you a kit pretty cheap.
Its difficult to beat the chinese though, especially with shipping from Norway ;)

### The PCB

From my research, nothing beats jlcpcb.com on price(pcbway.com is close, but not quite there...).
You will need to upload the "gerbers" on the frontpage of jlcpcb.

* v1: https://github.com/tompi/cheapino/releases/download/v1.0/gerber.zip
* v2: https://github.com/tompi/cheapino/releases/download/v2.0/cheapino_v2_gerber.zip

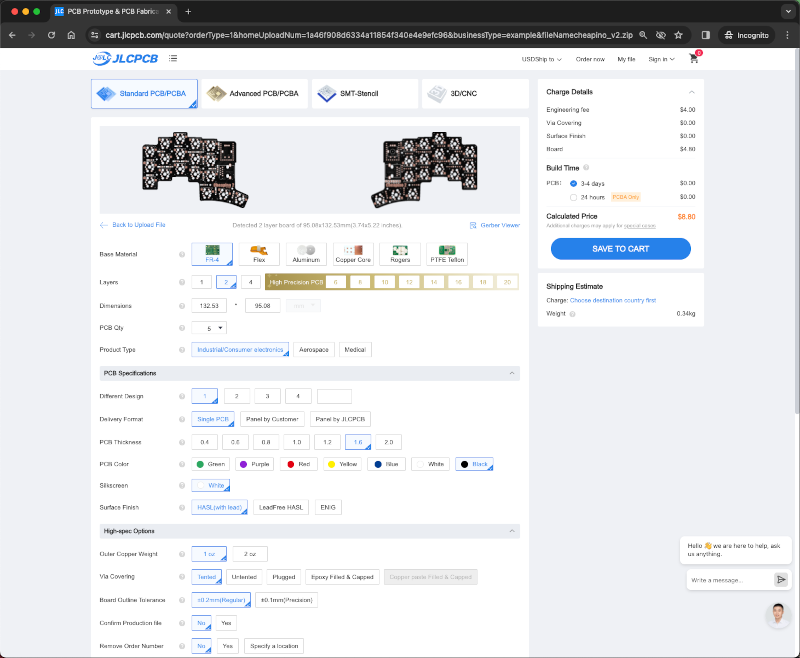
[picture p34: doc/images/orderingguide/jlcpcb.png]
JLCPCB


You should see a thumbnail of it afterwards. Defaults are fine, but you might consider
lead free HASL(ca 1usd more expensive).

You probably want to consider a different color than the default green.
This is completely up to you, there is no price difference, the only thing
is that green is guaranteed to take only 24 hours to produce, while
others might take up to 3-4 days(which is nothing compared to AliExpress shipping times...)

Take care when it comes to shipping, there is a lot of options, and price
and time varies a lot(they always get there in the end though, so I tend
to choose the cheapest option...).

Please note that the PCB is reversible so you'll only get 5 of the same PCB in the package.

### The components

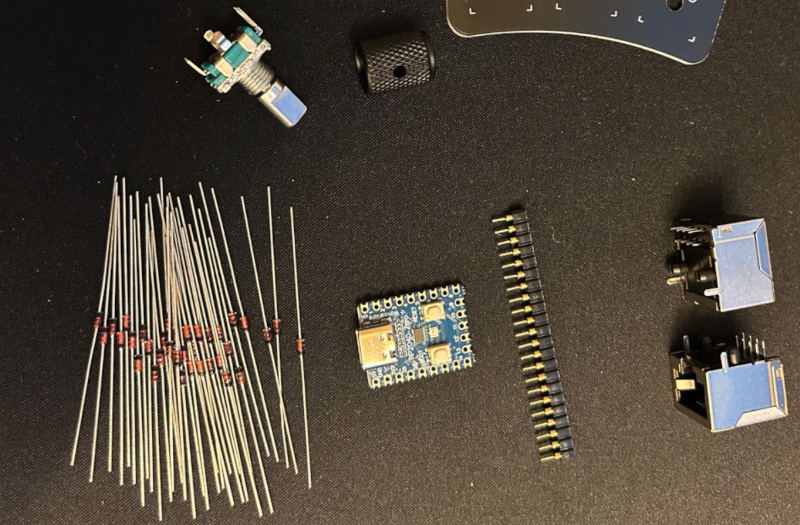
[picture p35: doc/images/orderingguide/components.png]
Components


You need switches, keycaps, rj45 sockets, diodes and an rp2040-zero mcu.
The encoder and mcu sockets are optional(to be honest, I dont use the encoder
much, I know other people do, and it doesnt cost much extra).

For a hotswap build(meaning you can replace switches without soldering),
you need to order hotswap sockets, and you should probably use a plate, or a case,
to keep swtiches from falling out accidentally. The old v1 plate will do, but
several people(including myself) are working on plates and cases. Stay tuned.

Some AliExpress components may not fit properly. If you want to be 100% sure, 
you can check the PCB with KiCad.

Buying from AliExpress is a bit of an art in itself. You need to do your
due diligence and check reviews and ratings of the store. If an item is priced
significantly lower than other places, without many sales or reviews, you
should be suspicious. AliExpress is just the middleman, and there are lots
of unserious actors.

For my own part, I have good experience with the new "Choice" options,
where you get free shipping on > 10usd orders. A few times I ordered
none choice-options and had problems with VOEC clearance, so I had to pay
extra taxes and a clearance fee, and it took way longer to ship.

These are the items I usually order:

| Part | Quantity for 1 keyboard | Quantity in sold package | Notes |Price (USD)  | Url |
| ---|---:|---:|---|----:|-----|
| RP2040-Zero | 1| 1|Choose the version without header(The pre-soldered headers can be a very tight fit...), and buy some sockets, its worth it! |1.78 | https://www.aliexpress.com/item/1005007763998604.html or https://www.aliexpress.com/item/1005007650325892.html |
| RJ45 Sockets (8P8C) | 2| 10|Make sure the pins are at the back of the socket (see PCB blueprint). |2.37 | https://www.aliexpress.com/item/32902228456.html |
| Diodes 1N4148 | 42| 50|You can also ordes smb if you want. Smaller but more difficult to solder: https://www.aliexpress.com/item/4000685043735.html |0.74 | https://www.aliexpress.com/item/1005006245109375.html |
| EC11 Encoder | 1| 5| |2.68 | https://www.aliexpress.com/item/1005004907970664.html |
| Encoder knob | 1| 5| A much better looking(and more expensive) knob: https://www.aliexpress.com/item/32749281108.html |1.35 | https://www.aliexpress.com/item/1005004907970664.html |

As you can see, it really makes sense to just order 2 mcu's at once, to be able to build 2 keyboards.

These are the items I really recommend in addition:

| Part | Quantity for 1 keyboard | Quantity in sold package | Notes |Price (USD)  | Url |
| ---|---:|---:|---|---:|-----|
| Sockets for MCU | 1| 5| Choose the single row silver plated(cheapest...). Socketing has multiple advantages: you can reuse mcu for another build, or more importantly replace it easily if it breaks. It also makes it easier to debug a faulty build.  | 2.01 | https://www.aliexpress.com/item/4001122376295.html |
| Silicone bumpers| ~20| 100| 5 mm wide and 2 mm high is fine. If you know you will only use the keyboard on a mat or with a case, you might not need this, otherwise you want them. | 1.65 | https://www.aliexpress.com/item/1005005592713123.html |
| Hotswap sockets | 36| 40| You want the mx one, NOT the low profile | 3.04 | https://www.aliexpress.com/item/1005006610157756.html |

Its very easy to underestimate the advantage of socketing the MCU. Think of it as an insurance. Desoldering the the pin-headers that come with the mcu is VERY difficult... If something goes wrong, you might need to switch the mcu(if you fry it because of a bridge between gnd and vcc, or if it is defect from the factory...), or if the pcb is damaged, you could re-use the mcu in a new pcb if you manage to remove it... Also, when things are not working, its very easy to tell if the
problem is on the pcb or the mcu, by removing the mcu...

These are some nifty items I really like, but not necessary:
(Warning: some cheap magnetic usb c cables might fry your rp2040-zero... Check this issue for more info: https://github.com/tompi/cheapino/issues/130 )

| Part | Quantity for 1 keyboard | Quantity in sold package | Notes |Price (USD)  | Url |
| ---|---:|---:|---|---:|-----|
| Flexible cat6 cable | 1| 1| 0.5m is perfect in my experience. Regular network cables are often very long and rigid. |0.84 | https://www.aliexpress.com/item/1005002518783703.html |
| Magnetic USB cable  | 1| 1| You can buy any brand, but make sure its not charging only, check the picture for 4+ contact points. I use these for all my boards, the usb port of the mcu is the first thing that will wear out if you dont use this. Make sure you get both cable+plug, and chose the usb c type. NB: These magnetic cables are not made to the usb-c spec, use at your own risk:
https://www.reddit.com/r/UsbCHardware/comments/motlhn/magnetic_usbc_cables_are_not_recommended/ (There are at least one reported problem here: https://github.com/tompi/cheapino/issues/156)        |2.22 | https://www.aliexpress.com/item/1005003776565766.html |
| Carrying case       |                        1|                         1| This case fits pretty snugly: 15x11x4,5cm (might depress switches, choose 17x12x5 for more space). Nice to have if you are travelling!        |2.12 | https://www.aliexpress.com/item/1005006381237074.html |

These cables are really good looking: https://www.aliexpress.com/item/1005006190874241.html
Pictures of them in action here: https://www.reddit.com/r/ErgoMechKeyboards/comments/1bz4lse/my_first_build_the_cheapino_v2/
NB: Some high-end(USB3.2) cables in combination with e.g. Mac M1 causes issues. For the cheapino, a cheap usb cable works best ;) Check the trouble shooting guide for more info.

## Switches

You will need switches, and people are writing insanely long texts about the topic, eg https://www.theremingoat.com/ .
I often work in an open space with other people, so I like to not make too much noise and tend to choose linear or silent tactiles,
as opposed to people who enjoy annoying others and choose clicky switches. (ok, im writing this text on my cheapino v1 with recycled
blue clickys, and they ARE pleasant, but this is at home, and my wife is using sound insulating earbuds atm...)

I have ordered these, and liked them: https://www.aliexpress.com/item/1005006270820565.html
(Just tried the peach and silent cream, but have an order for the lemon ones in as well...)

If you want cheap,

You will need 36 switches per keyboard.
** NB: buy 5 pin switches!** One of the most important improvements of v2 of the Cheapino
is support for 5 pin switches, which aligns switches easily even without a plate.

5 pins vs 3 pins switches

## Keycaps

Keycaps are also something you can spend huge amounts of time and money on.
Want a keycap with your favorite Pokemon molded in, no problem, they are just 40usd per keycap: https://hirosarts.com/custom-pokemon-keycap/
This guy got his keycaps after a small waiting period of 3+ years...: https://www.reddit.com/r/MechanicalKeyboards/comments/1c6zewk/about_3_years_2_months_and_6_days_later/

Im pretty happy with xda profiles from AliExpress. One set is usually enough for 2-3 Cheapinos...

Why not go all in an order a clear keyset, you will need to touch type anyway, so no need for
labels. You will blow your colleagues minds with this set: https://www.aliexpress.com/item/1005004761931363.html
I got the transparent one, and there was enough keys for 3 complete keyboards.

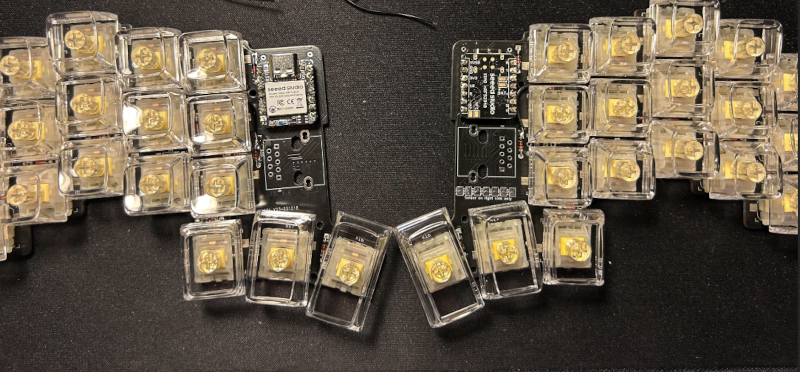
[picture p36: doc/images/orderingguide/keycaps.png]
Crystal Clear keycaps

This is a v2 prototype with milky yellow switches that im testing wireless with.

## Tools

Here are the tools you will need:

- Soldering iron (I have a KSGER T12 one from AliExpress, paid ~25usd I think, super happy with it!)
- Solder
- Diagonal cutters

Essential for beginners:

- **Flux** (crucial for clean solder joints, especially on tiny MCU pins)
- Safety goggles (you don't want solder or cut off diode legs in your eyes)
- Solder wick (for when you applied too much solder: apply some flux to it first)
- Cleaning ball for solder iron (made from copper wire) and sponge: for tip maintenance
- Helping hands: to hold the PCB up from the desk while soldering diodes

**Soldering Iron Recommendation**: The KSGER T12 mentioned above is excellent for beginners - it has precise temperature control and heats up quickly. Use a chisel tip (like T12-K or T12-BC2) for most components, and a fine conical tip (T12-I) only for the tiniest MCU pins.

Send me any tips you have!

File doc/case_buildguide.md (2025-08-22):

V2 Case build guide
===================

This is a case I made, very compact, almost no empty space inside:
https://www.thingiverse.com/thing:6661648

Lots of pictures here: https://imgur.com/a/cheapino-2-case-R4ialST

Case

To build it, you need to 3D print all 4 parts in the thingiverse link above.
If you want to tweak something, check the readme in the case-folder in this repo.

I printed this with 100% infill, and got feedback from others testing with other
values, and the 100% infill makes a difference in sound and feel(more compact, less ping).

You will also need 18 m2 heat brass insert nuts, 4mm long and 3mm outer diameter is optimal,
along with 18 m2 screws, around 5mm long, preferably counter sunk head, since the case
has counter sunk cutouts for the head.

**⚠️ IMPORTANT WARNING:** Do not use resin SLA printing for the case when using heat inserts. 
Resin degrades rather than melts when heated, making it incompatible with heat insert installation. 
Use FDM printing (PLA, PETG, ABS, etc.) for proper heat insert compatibility.

These are the items I ordered for my builds:
https://aliexpress.com/item/1005006939497014.html (M2X5 (200pcs) $2.61)
https://aliexpress.com/item/1005006071488810.html (M2xL4xOD3 (50PCS) $2.70)

If you are interested in tenting the keyboard, you might want to order
some adhesive mag-safe rings:
https://aliexpress.com/item/1005006256285165.html

Which you can use with stands to get any angle that suits you:
https://aliexpress.com/item/1005006349287185.html

Note: The item mentioned above is not available in all countries, but any stand with mag-safe connector and a bit heavy base should work.

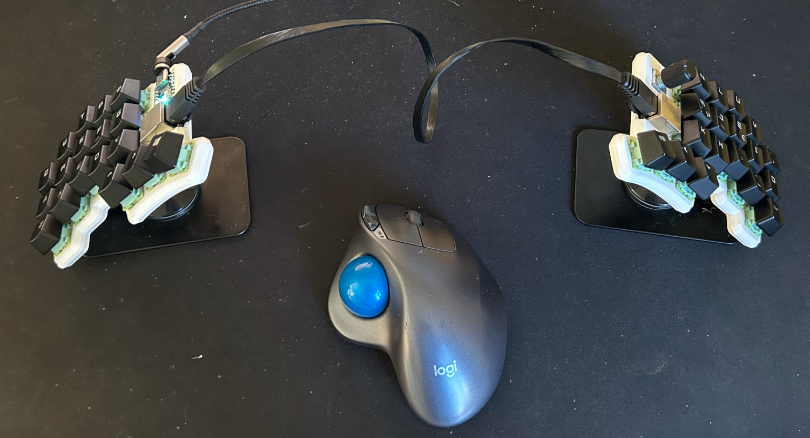
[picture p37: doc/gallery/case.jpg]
Tenting


Im also planning to design some snap-on feet, and there are compartments
in the case for these, for future use:
https://aliexpress.com/item/1005001658853871.html

Once you printed all 4 parts of the case, you need to install the m2 heat inserts.
You can insert them by using your soldering iron to heat them while applying gentle
pressure and maybe press last 10% with a flat surface, to get a nice finish.
Overly complicated explanation here:
https://hackaday.com/2019/02/28/threading-3d-printed-parts-how-to-use-heat-set-inserts/

Try to make sure all of your components are soldered flush to the pcb so they dont obstruct the case.
Place the bottom of the case on the pcb, and check that it fits flush to the pcb, otherwise you
might need to redo a component if it sticks out and prevents the bottom fit.
(Optionally, if you have magnets, place them in the cutouts before attaching the two bottom plates)

Next place the bottom into the top case, and attach it using 9 M2 screws per side.

Lastly remove adhesives for magsafe stickers, if you have them, and attach it carefully so you
dont obstruct any screws(otherwise you will have problems dismantling the case in the future).

## Case assembly
I need to preface this part, my printer which is a second hand ender 5, isn't calibrated properly, and i'm too lazy to invest the time to do it.
With that out of the way, I printed tompi's case, and got some new keycaps, a magnetic USB cable and a nicer patch lead to connect the halves.


#### Fitting the threaded inserts
After printing the case top, you will see these holes on the inside.
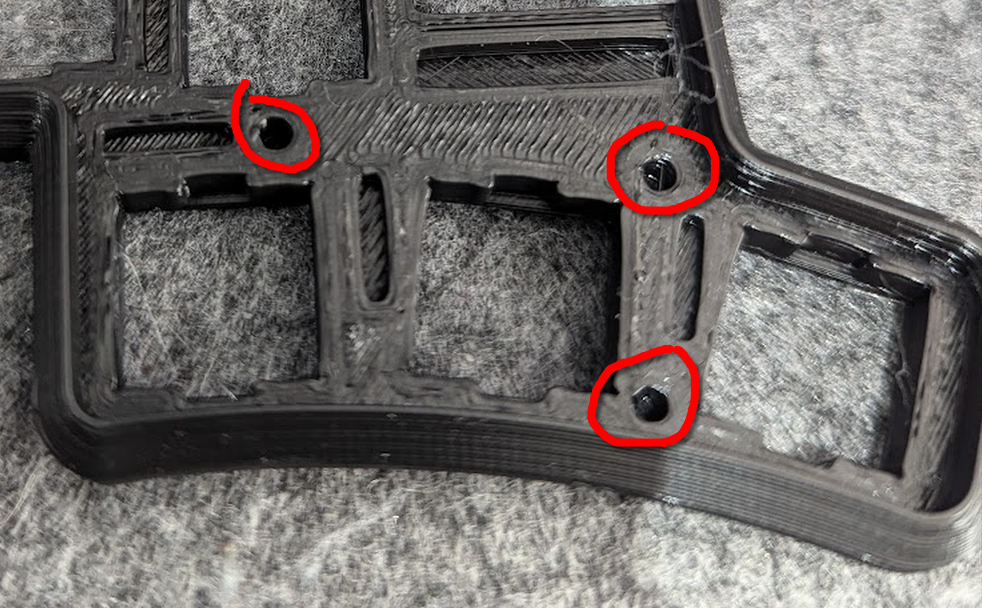
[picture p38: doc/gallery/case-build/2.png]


I found using a pair of curved needle-nose pliers made this quite easy to do.
- Line up the threaded insert with pliers
- Push the insert into the hole with a hot soldering iron
- Remove the soldering iron when the insert is level with the top of the hole (sometimes the insert will be stuck on the iron, in this case, use the pliers to hold the insert in place when you remove the iron)

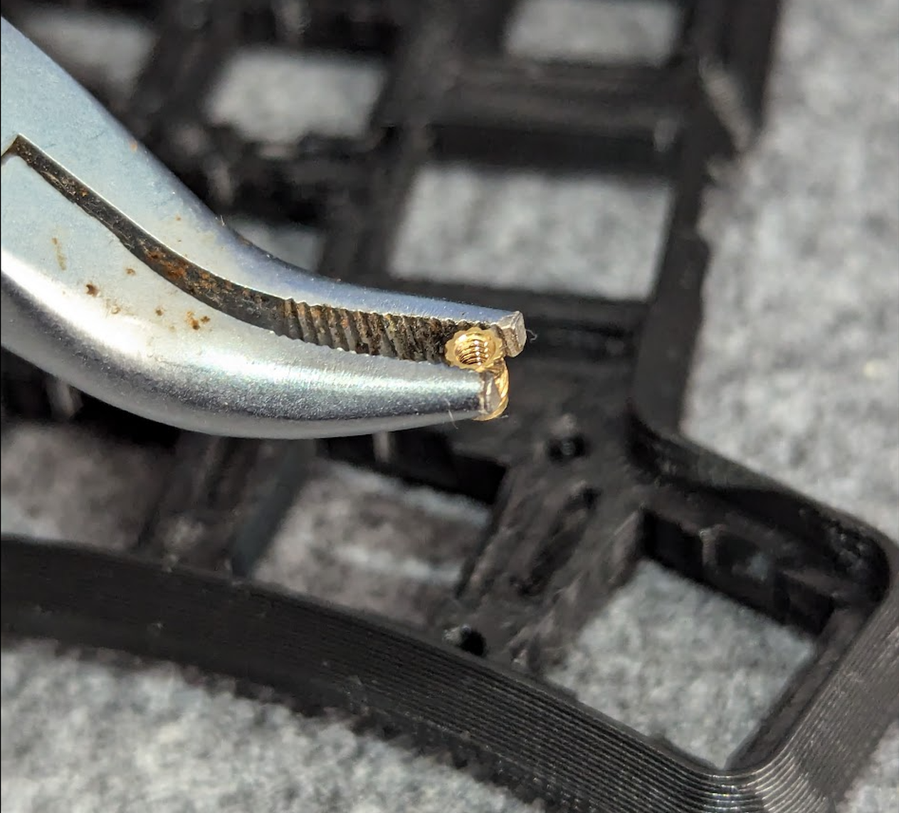
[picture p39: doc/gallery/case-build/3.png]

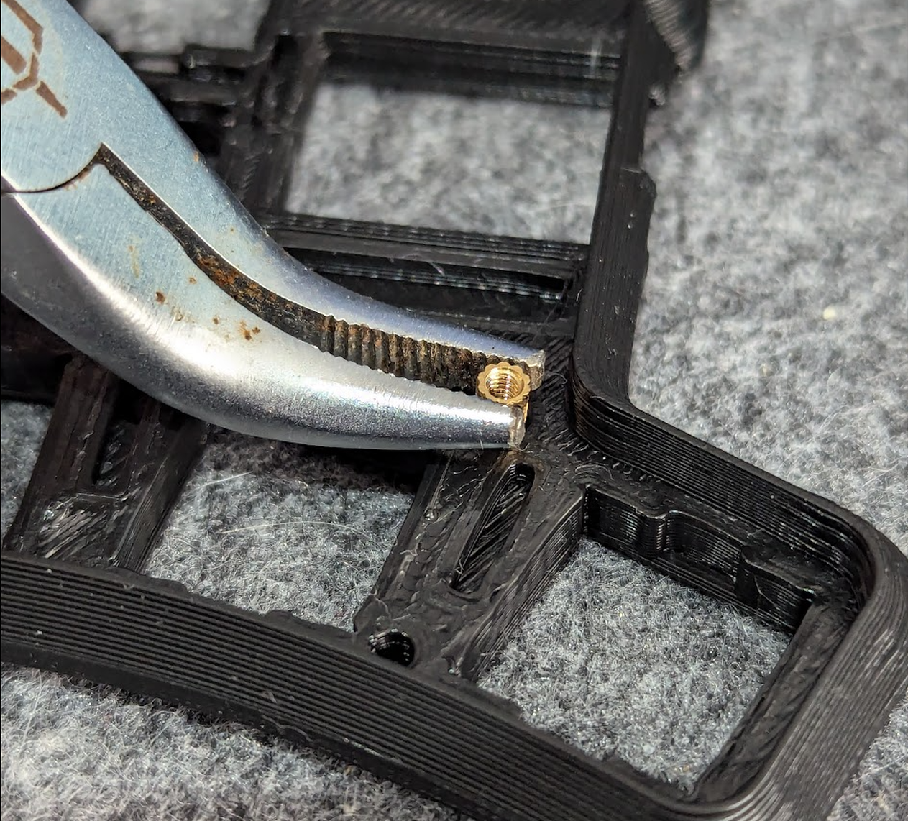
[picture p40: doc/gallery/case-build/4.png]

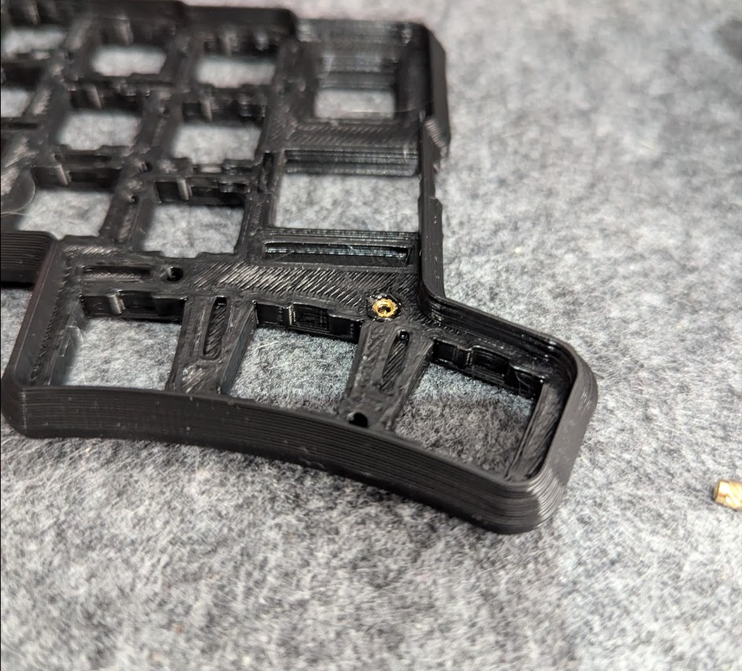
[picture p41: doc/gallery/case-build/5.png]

Repeat for all "holes"
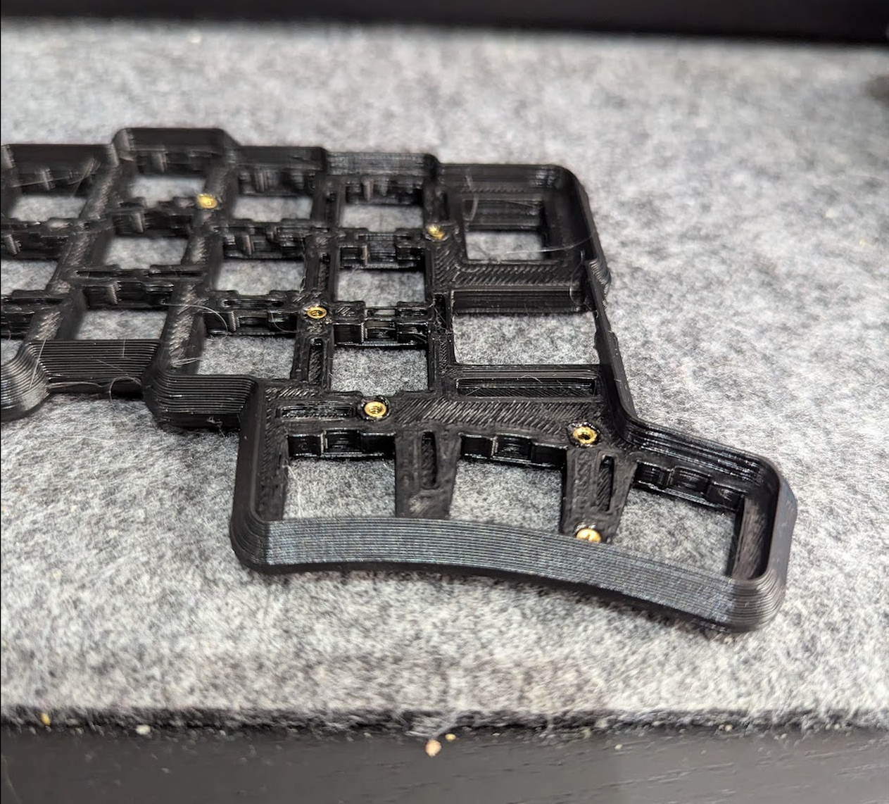
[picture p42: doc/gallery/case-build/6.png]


#### Fitting the case
Remove all the switches
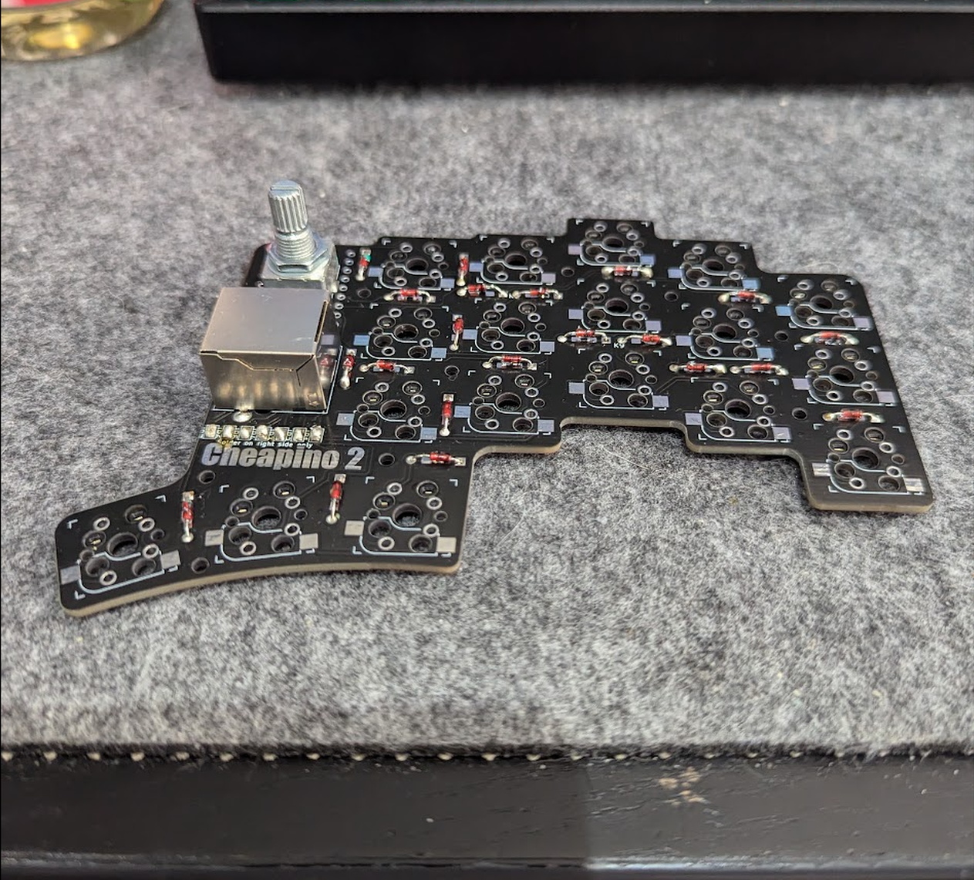
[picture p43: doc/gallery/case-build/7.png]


Place the PCB inside the case
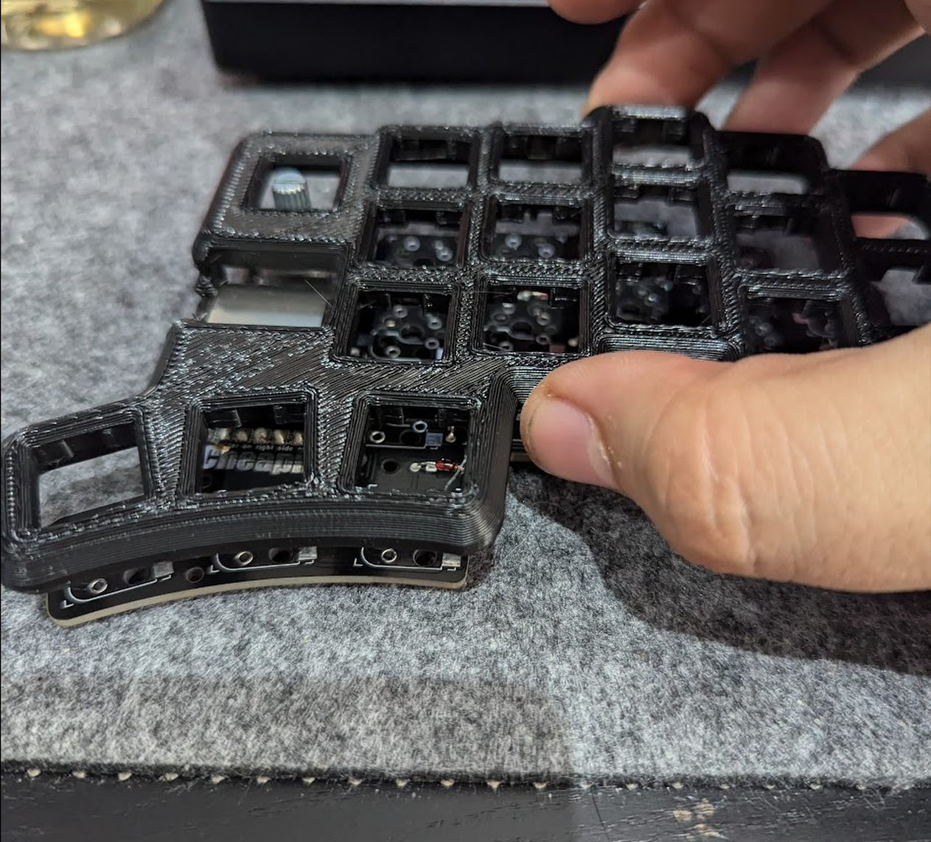
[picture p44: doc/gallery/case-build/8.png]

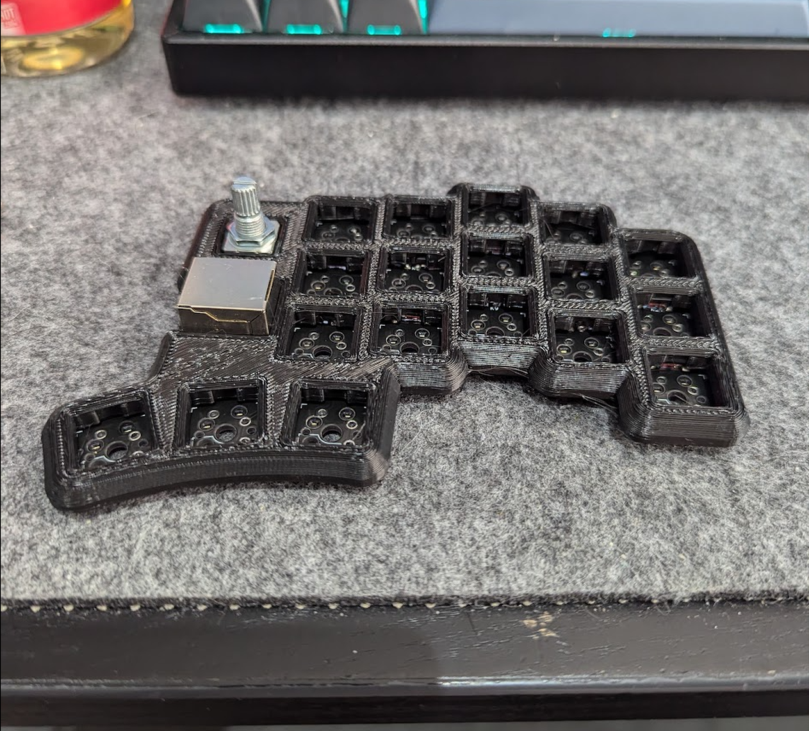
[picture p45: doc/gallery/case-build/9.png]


Flip it upside down
**Note:** i didn't use the case bottom, but if you did, set it in place at this point.
insert the screws through the case bottom if you're using it, if not, just screw them in through the screw holes in the PCB.
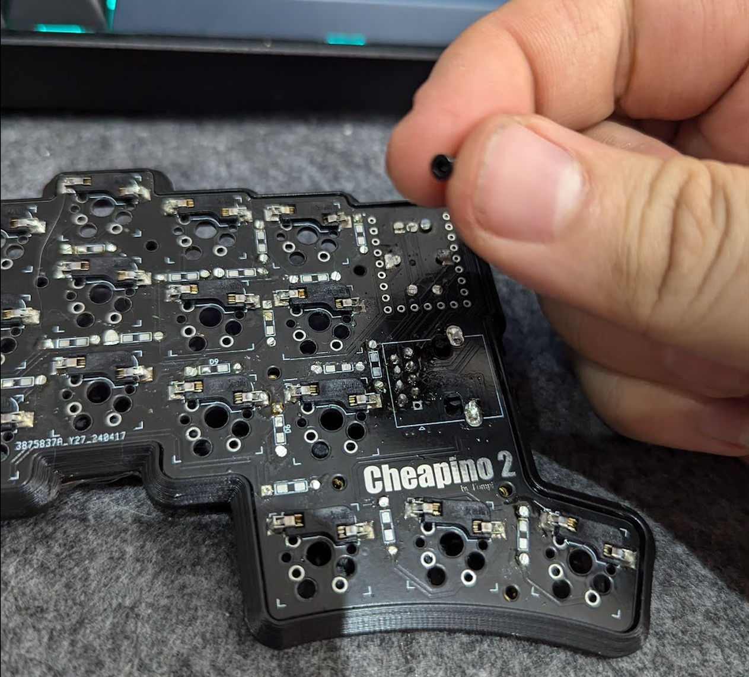
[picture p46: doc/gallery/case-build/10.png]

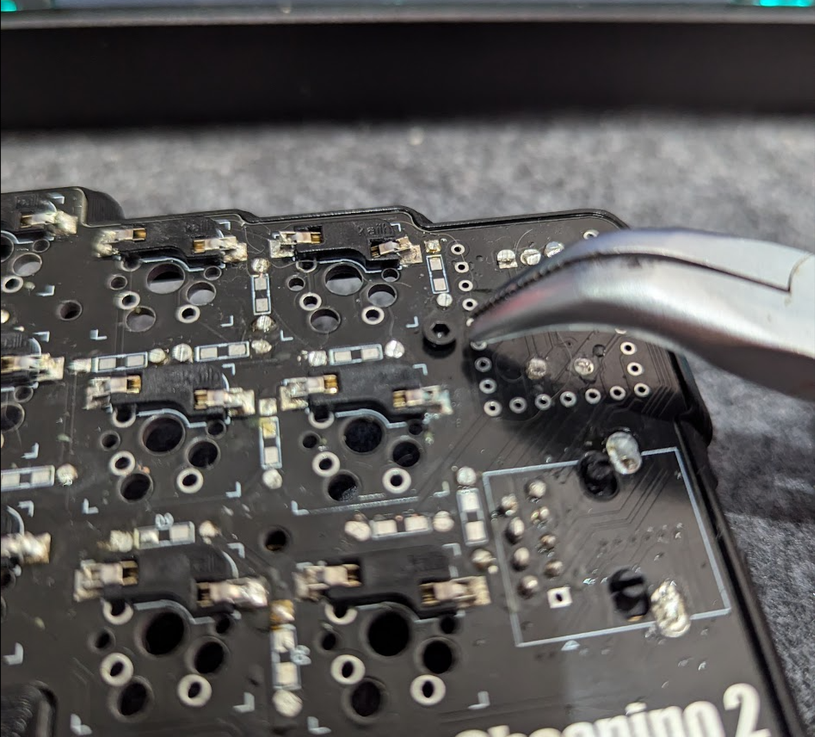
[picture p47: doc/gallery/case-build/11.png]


Once this is done, flip back over and refit the switches and keycaps. As i mentioned, my printer isn't calibrated very well, so pushing the switches in took a LOT of force, but they did go in, and as a bonus, this means my switches have zero wobble.
It looked like this once i got all the switches and keycaps installed.


Instead of using the case bottom, i just added some 3M dots as cusioning, and they work perfectly well for me.


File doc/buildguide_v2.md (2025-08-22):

# Cheapino v2 build guide

## Introduction

Welcome to the Cheapino Keyboard v2 Build Guide!
In this guide, I will walk you through the steps to build your own custom keyboard using the Cheapino v2 kit.
The Cheapino is a budget-friendly DIY split mechanical keyboard that is perfect for beginners who are looking
to try their hand at building their own keyboard.

I assume you read the [ordering guide](orderingguide.md) and have all the mandatory parts and tools.

This guy also documented his build very good: https://imgur.com/a/building-cheapino-as-complete-beginner-G8dDaJi

This soldering guide is pretty good:
https://www.circuitspecialists.com/blog/how-to-soldering-correctly-soldering-101/

## Steps

In my experience it is easiest to solder the lowest components first, and the highest last, since you need to turn the PCB around with the components on the other side when soldering(and then you want the loose ones to rest directly at the desk). 

**Build order recommendation**: Some experienced builders suggest doing hotswap sockets first (if using them) since they're easier to access before other components are installed. The general order would be: hotswap sockets, diodes, bridge pads (right side), MCU, switches, RJ45 socket, and lastly the encoder.

**Important for beginners**: Take your time with the MCU - those pins are tiny! Use flux liberally, work slowly, and clean your iron tip frequently. If you're new to soldering, consider practicing on some spare components first.

### Step 1: Hotswap sockets

This step is optional, and only if you are building for hotswap.
The sockets go on the bottom sides of of the PCB,
Make sure you follow the PCB outline for the sockets(white lines),
its very easy to solder them in the wrong direction(at least that
is what I managed to do with more than half of them first time...)

Just make sure to place them on the white outline, AND that
the big switch hole is unobstructed.

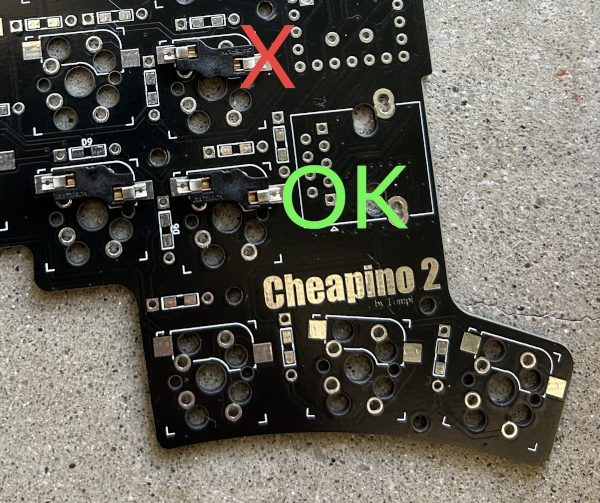
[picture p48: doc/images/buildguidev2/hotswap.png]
Hotswap


### Step 2: Diodes

You need to be careful to solder the diodes the correct way.
The line on the diode should always be closest to the square pad of the footprint,
NOT the round one. The PCB supports SMD and throug hole diodes,
and you can choose which side you want to mount them.

I suggest mounting them on the top side, to keep height of board as low as possible.

I like to solder from the component side, not the dangling legs side, but each to his own ;)

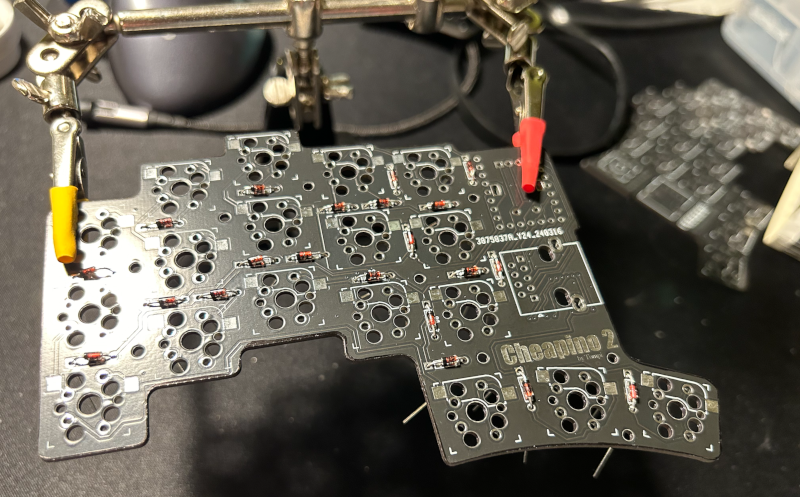
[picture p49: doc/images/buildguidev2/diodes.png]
Diodes


If you use through hole diodes and have sockets for the MCU,
keep the legs you cut off and use them for socketing the MCU.

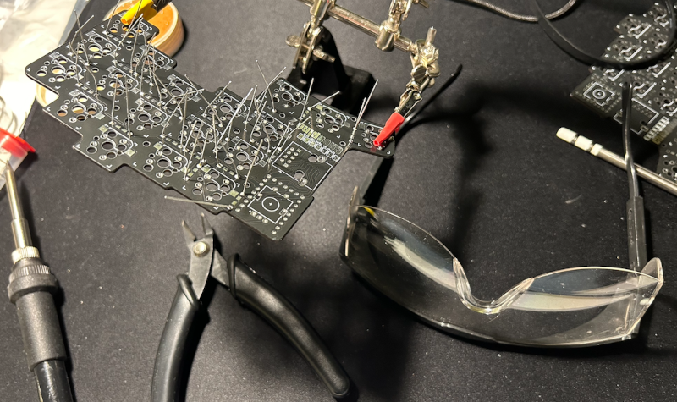
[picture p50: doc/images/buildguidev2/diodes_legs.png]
Diode legs


### Step 3: Bridge solder pads on right side

This step is only for the right side of the keyboard.
You need to bridge the 7 solder pads. If you forget this, the right side will not register keypresses.

This is an improvement over v1, in that no columns or rows are shared between sides, getting rid of ghosting issues.

Bridging can be a bit tricky with a pointed soldering tip, its best to use a flat one.
Both will work though, just make sure you dont spend too much time heating up the pads.
If you fail to bridge, take a break and let them cool down, and apply some flux before retrying.

If you apply too much heat too long, you might lift the pads, and then you will need to bodge wire stuff...

In the picture I bridged 4 of the 7:

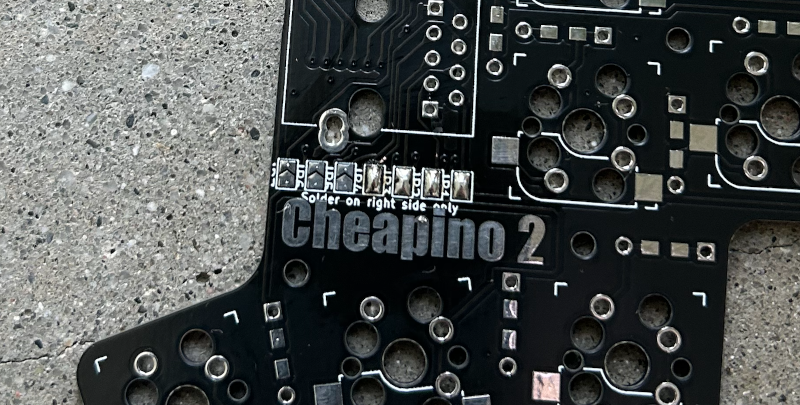
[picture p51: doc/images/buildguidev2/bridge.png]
Bridging pads


### Step 4: MCU

Only the pins on the 2 long sides are actually used, but if you have the RP2040-Zero with pre-soldered pin headers, there is room for that also. Choose one of the following steps:

#### Socket the MCU

Socketing makes it easier to reuse the MCU(the RP2040-Zero) for another build later, or swap it if its broken or malfunctions.

NB: The cheap sockets linked from the ordering guide happily accepts diode legs, while the more "expensive"
ones typically have larger holes, so for these you might wanna go with picking out the legs that came in the
yellow plastic with the mcu(they are thicker and sturdier than diode legs).

If you have sockets for the MCU, mount them on a breadboard, or stick them in some cardboard to get them straight when mounting.

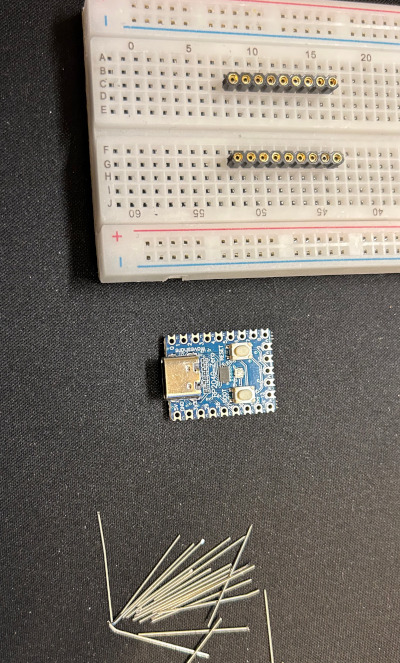
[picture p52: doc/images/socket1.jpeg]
Socketing 1


Stick the clipped diode feet through the MCU, and down into the socket. Use a tool, or you will stick it into your fingers(been there, done that...).

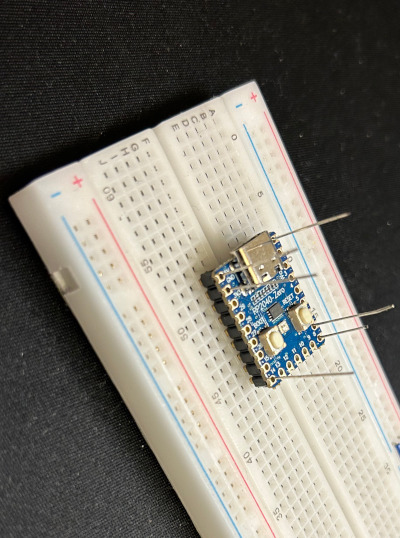
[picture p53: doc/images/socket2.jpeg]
Socketing 2


Solder all the feet in place, and remove all 3 parts from the breadboard, and put them into the PCB, use some tape to hold it in place when you turn it around and solder it.

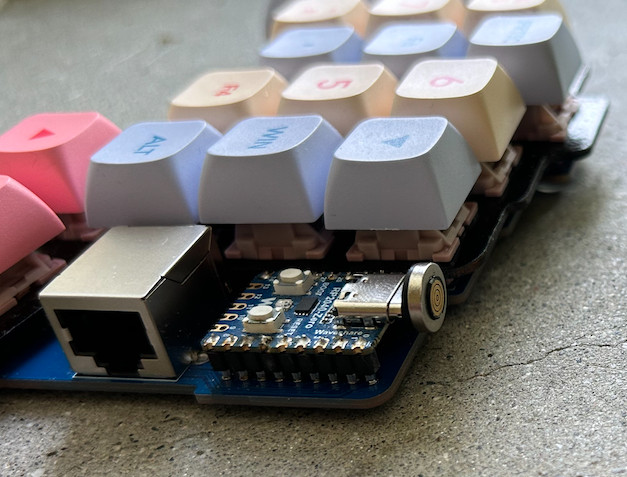
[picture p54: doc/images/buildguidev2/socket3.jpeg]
Socketing 3


#### Use pinheader to mount MCU

Use the two longest yellow pin headers that come with the MCU: solder them to the board first, and then solder the MCU to them.

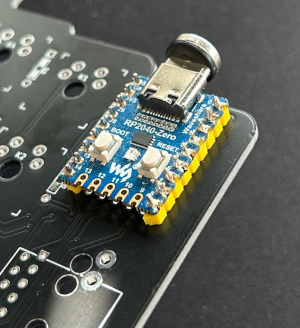
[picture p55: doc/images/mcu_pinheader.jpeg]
MCU pin header


### Step 5: Install the Switches

Next, it's time to install the switches.
Note: if you installed hotswap sockets you do NOT need to solder switches...
If you only have 3 pin switches, refer to hints in the v1 build guide on how to align them.

Pop them all in, turn the PCB around and solder them.
I solder 1 pin from each switch on a row, and then do the other pin for the entire row, to
minimize risk of overheating switch and melting the plastic.

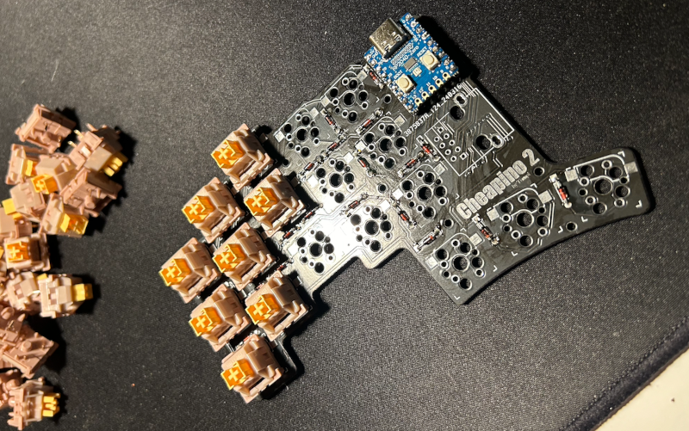
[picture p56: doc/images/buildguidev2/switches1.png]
Switches front


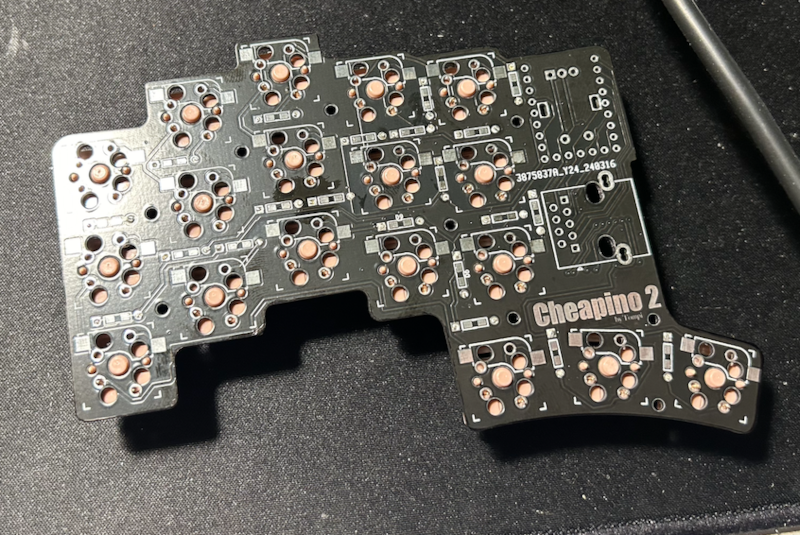
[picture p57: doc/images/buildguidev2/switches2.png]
Switches back


### Step 6: Install the RJ45 sockets

Just align them to the white outline. They should stay in place by themselves when you flip the PCB to solder them.

### Step 7: Install the encoder

Put the encoder in the footprint on the right side, make sure its flush to the PCB when you solder it.

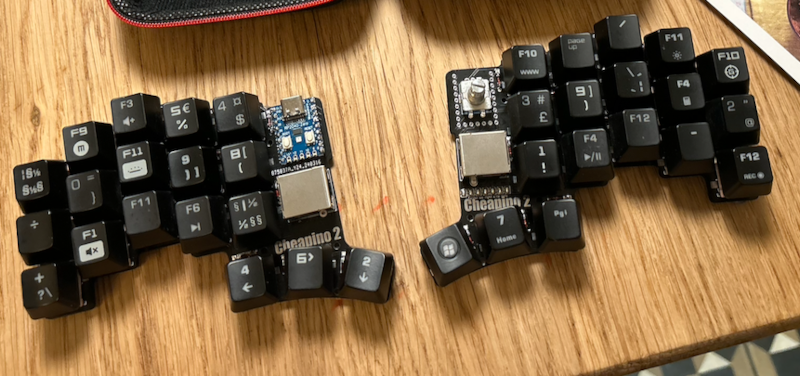
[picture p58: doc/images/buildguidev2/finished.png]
Finished


### Step 8: Trim below and install bumpers

Use the cutters to trim any extruding wires on the underside of the PCBs.
I havent done this with anything else than the encoder pins which I found to
stick out a little extra.

Maybe clip them inside a plastic bag to prevent the metal from flying around.

Install rubber bumpers to protect your desk and keep the keyboard from moving.
The v2 outline is a bit smaller than the v1, so be generous with the bumpers,
sprinkle them all around, or typing will be wobbly.

### Step 9: Test that everything works.

There is a good chance you forgot to solder a diode or a switch leg...

Flash the vial firmware in the release section.
The encoder should send arrow up and down by default, and pressing
the encoder should play/pause your currently playing media.

Download vial to test all the keys(and use it to re-map if you want).

## Firmware

Congratulations, you have successfully built your own custom keyboard.

See the [firmware guide](firmware.md) for how to build and customize keyboard firmware.

Send me a mail or issue if something doesnt work as expected!

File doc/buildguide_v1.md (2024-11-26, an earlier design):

# Cheapino v1 build guide

## Introduction

Welcome to the Cheapino Keyboard Build Guide! In this guide, we will walk you through the steps to build your own custom keyboard using the Cheapino kit. The Cheapino is a budget-friendly DIY split mechanical keyboard that is perfect for beginners who are looking to try their hand at building their own keyboard.

## Tools

Before we start, here are the tools you will need:

- Soldering iron
- Solder
- Diagonal cutters

## Parts

Since the PCBs are the most expensive items, and you cant order less than 5 from most sites, Im assuming you will build 2 Cheapinos. Most of the other components will also come in quantities allowing for 2 sets.

Im not including switches and keycaps, since these are a matter of personal taste.
You will need 36 switches and 1u(the regular letter sized) keycaps per set.
This can easily be the most expensive

| Part | Quantity | Where to get it | Estimated price (including shipping) |
| --- | --- | --- | --- |
| Cheapino PCB | 4 | Upload the [PCB v1 gerber](https://github.com/tompi/cheapino/releases/download/v1.0/gerber.zip) to [JLCPCB](https://www.jlcpcb.com) (or other pcb house). | 20.00 (for 5 pcs) |
| Waveshare RP2040-Zero |  2 | [AliExpress](https://www.aliexpress.com/item/3256804781611696.html) | 8.50 (for 2 pcs) |
| RJ45 Socket |  4 | [AliExpress](https://www.aliexpress.com/item/32902228456.html) | 5.00 (for 10 pcs)|
| EC11 Rotary encoder |  2 | [AliExpress](https://www.aliexpress.com/item/10000000931574.html) | 5.00 (for 2 pcs) |
| Encoder knob |  2 | [AliExpress](https://www.aliexpress.com/item/32749281108.html) | 5.00 (for 2 pcs)|
| Diodes 1N4148 | 80 | [AliExpress](https://www.aliexpress.com/item/32660088529.html) | 2.00 (for 100 pcs) |

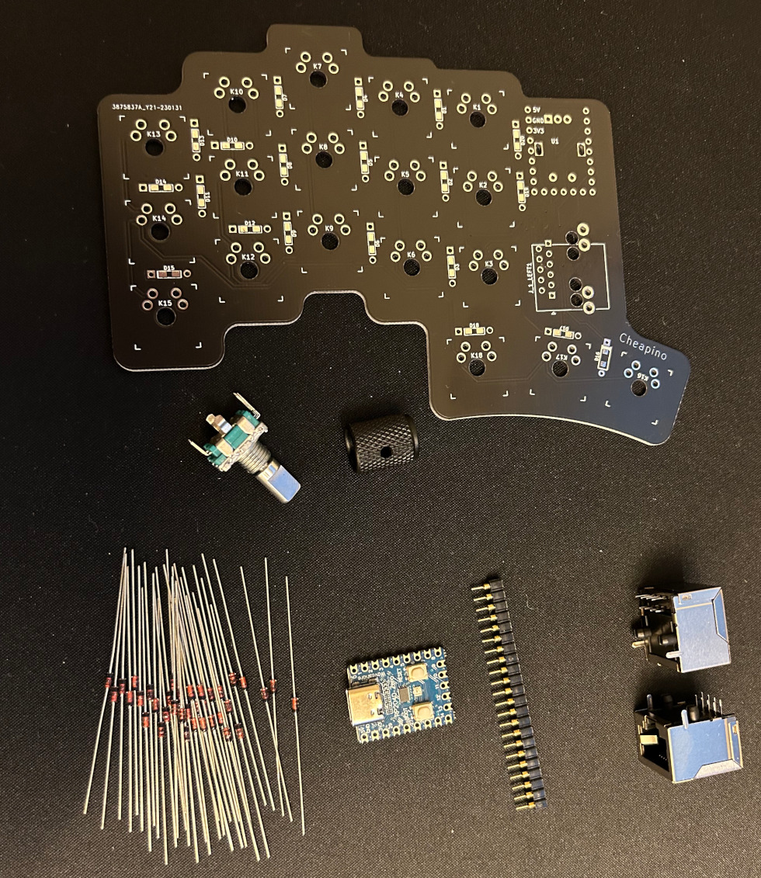
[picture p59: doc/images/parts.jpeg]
Components


These parts are optional, but nice to have:

| Part | Quantity | Where to get it | Estimated price (including shipping) |
| --- | --- | --- | --- |
| Sockets for MCU(optional) |  2 | [AliExpress](https://www.aliexpress.com/item/32892386779.html) | 5.00 (for 10 pcs) |
| Flexible RJ45 cable 0.5m |  2 | [AliExpress](https://www.aliexpress.com/item/1005002518783703.html) | 3.00 (for 2 pcs) |
| Magnetic USB cable |  2 | [AliExpress](https://www.aliexpress.com/item/1005003776565766.html) | 3.00 (for 2 pcs) |
| Rubber bumpers | ~16 | [AliExpress](https://www.aliexpress.com/item/1005003044229837.html) | 2.00 (for 50 pcs) |

## Steps

In my experience it is easiest to solder the lowest components first, and the highest last, since you need to turn the PCB around with the components on the other side when soldering(and then you want the loose ones to rest directly at the desk). Thats why I suggest starting with the diodes, then the MCU, the switches, the RJ45 socket and lastly the encoder.

### Step 1: Diodes

You need to be careful to solder the diodes the correct way. The line on the diode should always be closest to the square pad of the footprint, NOT the round one. The PCB supports SMD and through hole diodes, but since K16 is missing smd pads, I recommend using through hole(if you only have smd, you need to hack K16, not very hard, use a small piece of wire).

If you use through hole diodes and have sockets for the MCU, keep the legs you cut off and use them for socketing the MCU.

### Step 2: MCU

Only the pins on the 2 long sides are actually used, but if you have the RP2040-Zero with pre-soldered pin headers, there is room for that also. Choose one of the following steps:

#### Socket the MCU

Socketing makes it easier to reuse the MCU(the RP2040-Zero) for another build later, or swap it if its broken or malfunctions.

If you have sockets for the MCU, mount them on a breadboard, or stick them in some cardboard to get them straight when mounting.

Socketing 1

Stick the clipped diode feet through the MCU, and down into the socket. Use a tool, or you will stick it into your fingers(been there, done that...).

Socketing 2

Solder all the feet in place, and remove all 3 parts from the breadboard, and put them into the PCB, use some tape to hold it in place when you turn it around and solder it.

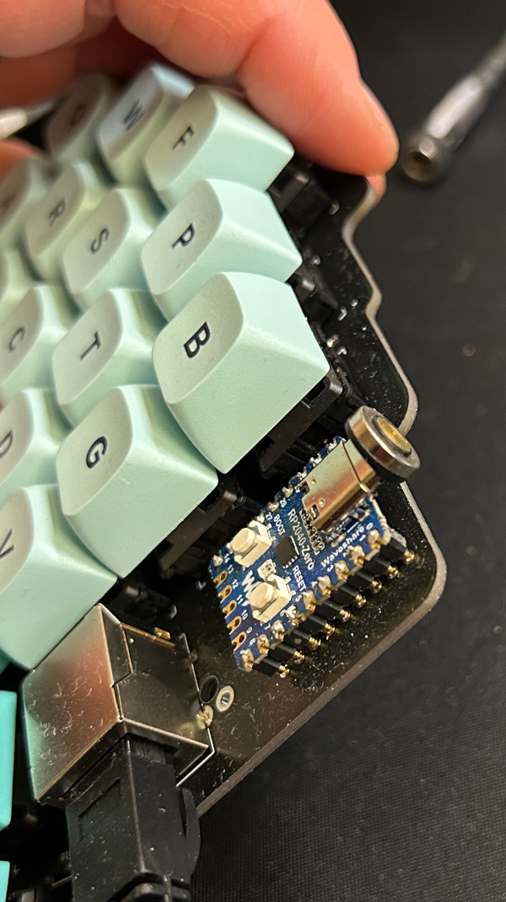
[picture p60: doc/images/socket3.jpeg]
Socketing 3


#### Use pinheader to mount MCU

Use the two longest yellow pin headers that come with the MCU: solder them to the board first, and then solder the MCU to them.

MCU pin header

### Step 3: Install the Switches

Next, it's time to install the switches.
This can be a bit tricky to get straight, since there is only 3 pin holes.
Try to solder one column at a time, use something to align the switches, and tape them down before soldering.

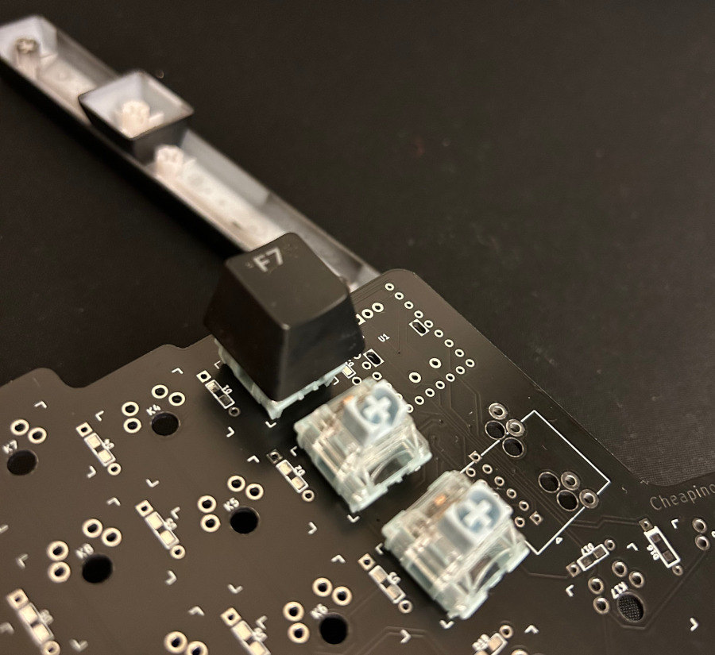
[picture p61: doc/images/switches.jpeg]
Switches


One trick from [TentacleSenpai69](https://www.reddit.com/user/TentacleSenpai69/) is to put on keycaps on a column and use a space bar to keep the column aligned, and then tape it.

If you have a 3D printer you could print these excellent fork-helpers from @MrBarbie: https://www.printables.com/model/582030-switch-alignment-rail
Make sure you print the 19mm version, since the cheapino uses 19.00 mm spacing instead of the traditional 19.05 mm spacing...

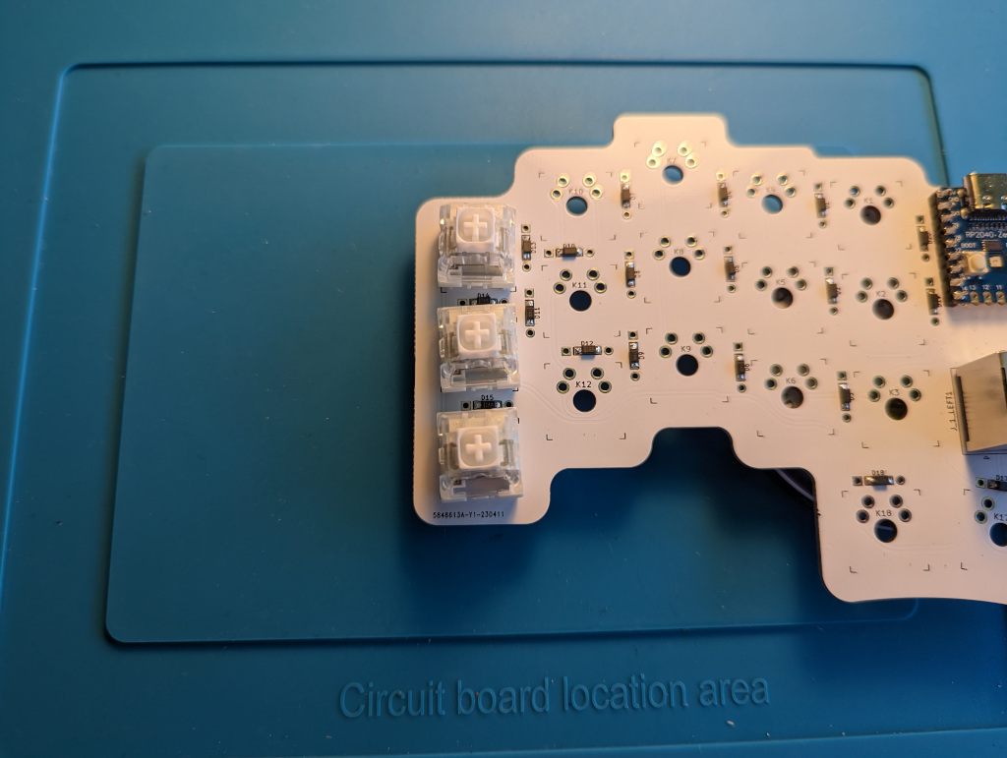
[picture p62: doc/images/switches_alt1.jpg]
Switches A1

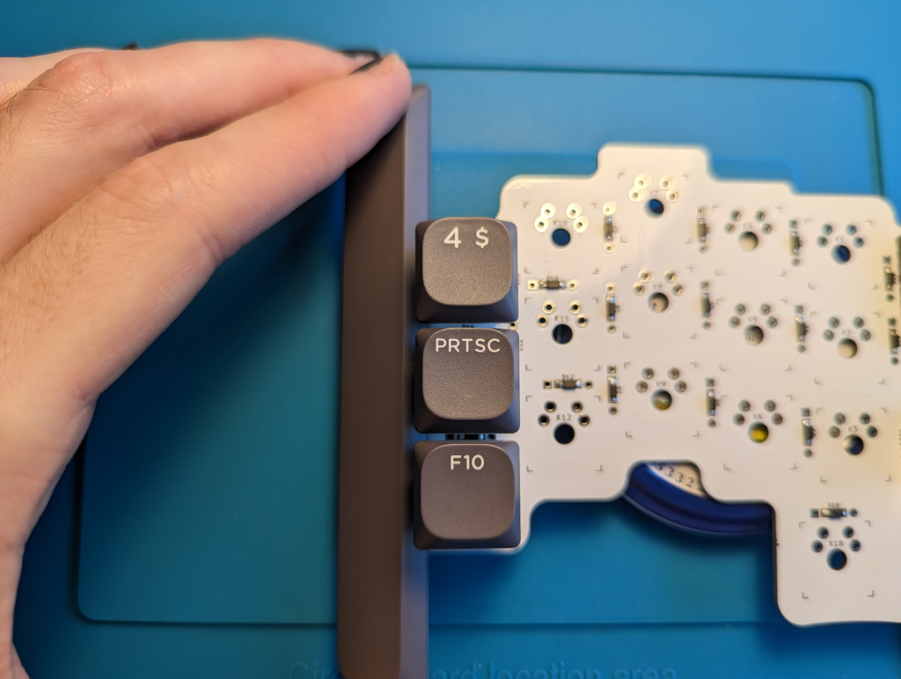
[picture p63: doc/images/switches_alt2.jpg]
Switches A2

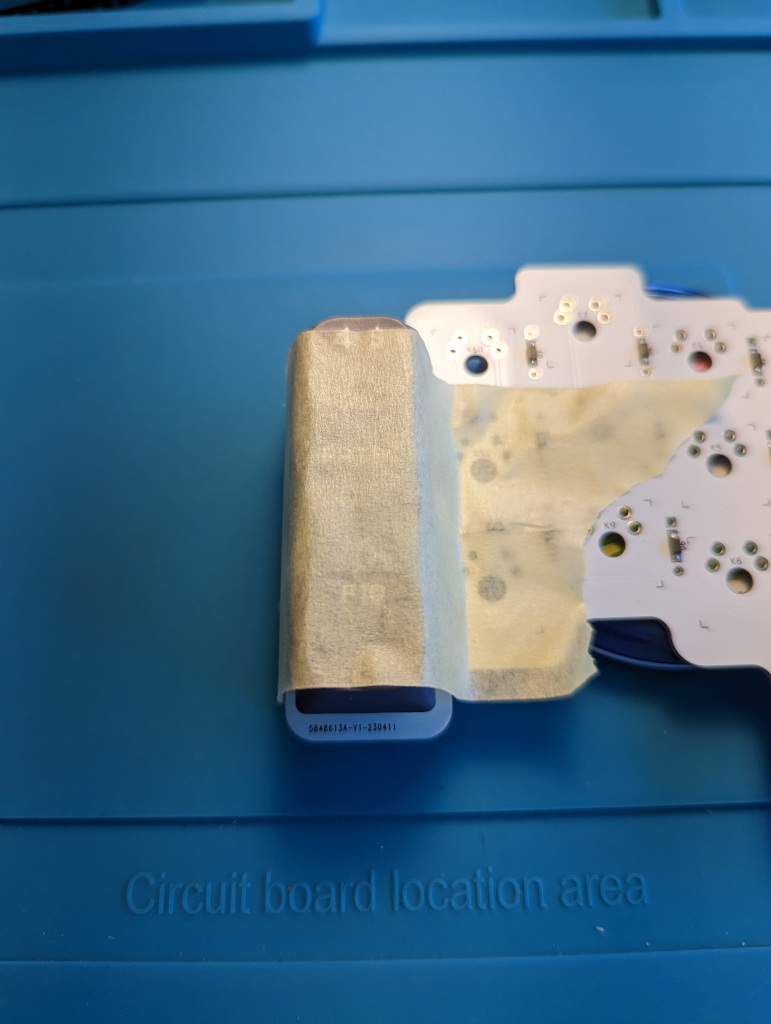
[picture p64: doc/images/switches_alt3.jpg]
Switches A3

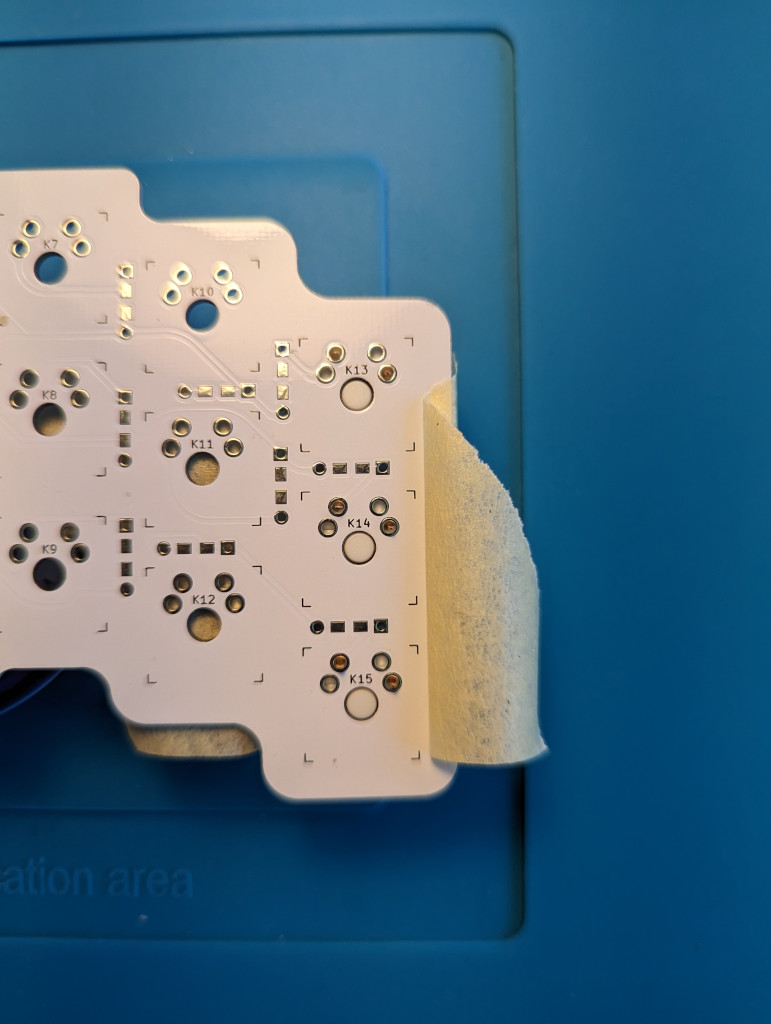
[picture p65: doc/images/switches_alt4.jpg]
Switches A4


### Step 4: Install the RJ45 sockets

Some connectors might short the casing to the outer unused pin.
It might be a good idea to place a tiny piece of tape on top
of the pin hole that is directly on the footprint outline of the connector you are installing, or at the housing itself where it touches this.

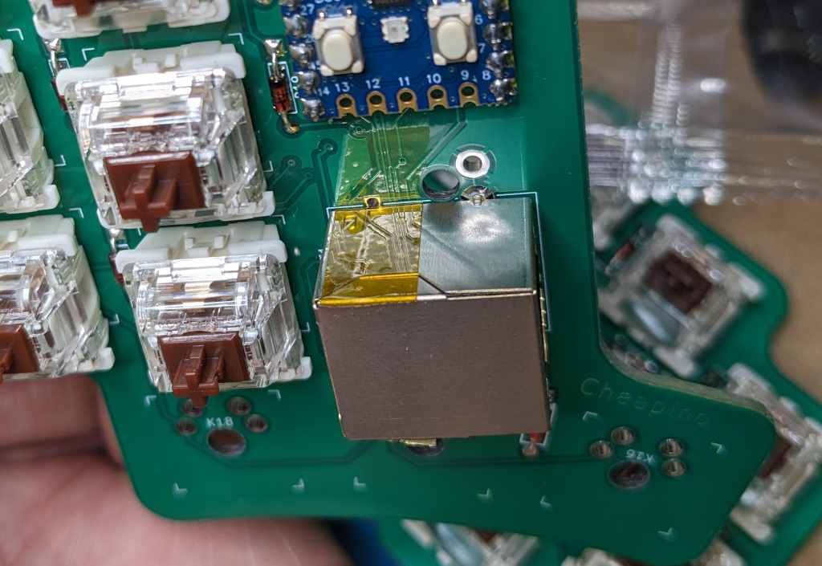
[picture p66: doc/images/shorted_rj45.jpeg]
RJ45 possible short


Just align them to the white outline. They should stay in place by themselves when you flip the PCB to solder them.

### Step 5: Install the encoder

Put the encoder in the footprint on the right side, make sure its flush to the PCB when you solder it.

### Step 6: Trim below and install bumpers

Use the cutters to trim any extruding wires on the underside of the PCBs. Maybe clip them inside a plastic bag to prevent the metal from flying around. Install rubber bumpers to protect your desk and keep the keyboard from moving.

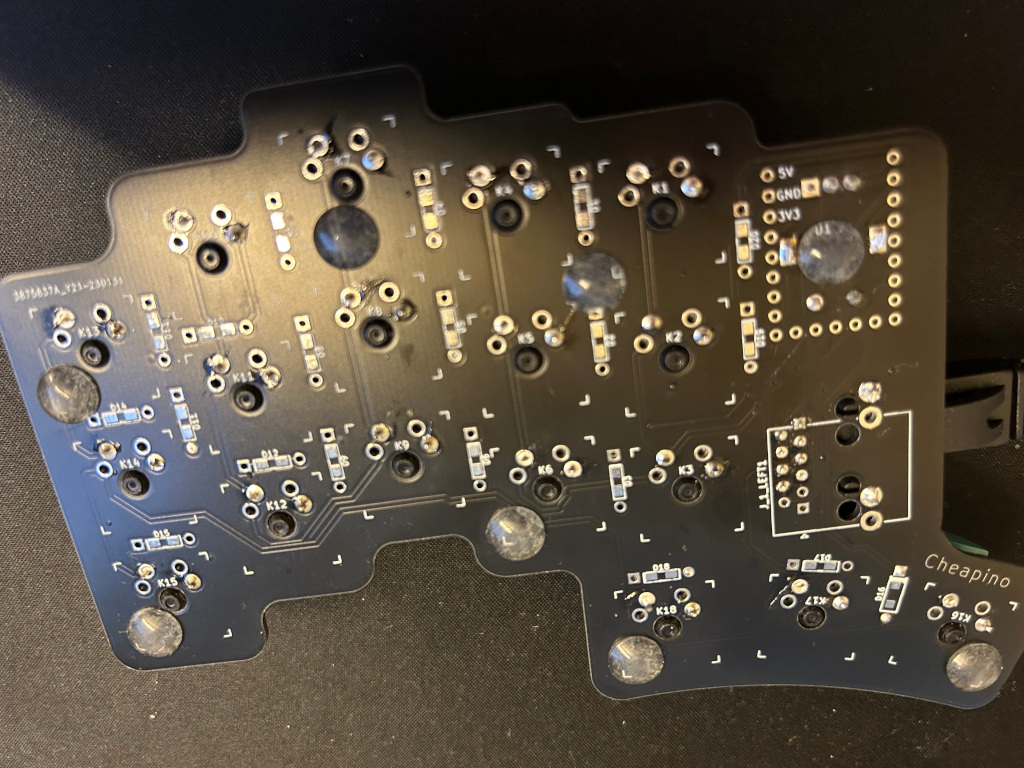
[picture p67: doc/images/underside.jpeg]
Underside


## Firmware

Congratulations, you have successfully built your own custom keyboard.

See the [firmware guide](firmware.md) for how to build and customize keyboard firmware.

Send me a mail or issue if something doesnt work as expected!

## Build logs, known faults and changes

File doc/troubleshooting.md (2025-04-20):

# Cheapino troubleshooting

## The keyboard lights up but does not work

This can happen for 2 reasons:

### You used a charging only cable.
Solution: Find a cable with data support.

### There is an issue with certain combinations of high end cables and computers.
Checkout this issue:
https://github.com/tompi/cheapino/issues/78
and this reddit post for more info:
https://www.reddit.com/r/ErgoMechKeyboards/comments/1fx67uz/cheapino_not_working_but_powers_on_with_usba/

Solution: Try a USB 2.0 cable(usually this just means "cheaper"...)

## Single switches are not working

Usually, this is caused by either not soldering the diode, soldering the diode in the wrong direction, or in some very rare cases a malfunctioning diode or switch.

To rule out the switch: try to short the two pins of the switch with a wire.
If this fires the key, you got a bad switch: desolder it and put in a new one.
(Get yourself an "engineer ss02", its amazing for desoldering work...)

If it doesnt, try to short the circuit "before" the diode. If this works the diode is either bad or in the wrong direction. Desolder and realign or switch it.

## Entire rows or entire columns are not working

This could be caused by several things. Read up below, and view [the interactive schematic](https://tompi.github.io/cheapino/doc/troubleshooting/routing.html) for easy troubleshooting.

### Bad connection on MCU

Check that the pins of your rp2040-zero are all soldered ok. There should not be a "blob" of solder, it should look like a volcano. Retouch any strange looking soldering points on the MCU.

### Shorts on the MCU or the RJ45 socket

Check your soldering on both MCU and the RJ45 sockets. If there are any shorts, try sucking up some solder with e.g. some solder wick or your solder sucker.

### Magnetic usb c cable frying the MCU

There have been reports of magnetic cables frying the MCU, some details here:
https://github.com/tompi/cheapino/issues/130

TLDR: If your computer complains about "The USB port is drawing too much power", you should inspect the magnetic cable, and consider swapping it out before something bad happens...

### Ethernet crossover cable

Not all ethernet cables are the same... There are different variants more or less rare, for different purposes. The most common which will create problems for the cheapino is the crossover cable: https://en.wikipedia.org/wiki/Ethernet_crossover_cable

Try different cables, if one is working fine, this is your issue.

## Suddenly my cheapino outputs A LOT of random characters

This will happen with some cheap encoders, they may not de-tent properly, and get stuck in a position which creates problems for the firmware. The solution to this is just to turn the encoder a little, and it should go away... (this should NOT happen on v2...)

## The keyboard outputs random/none/wrong keys

Make sure you flashed the version matching your PCB. V1 firmware will NOT work on V2, and vica versa.
If in doubt, just download from the release section and flash again.

## The keyboard/mcu is heating up really fast

This can happen if there is a short between gnd and vcc. Check continuity and find the short, and fix it with some solder wick or a pump.

## None of the above helped!

Open up an issue! I just think its fun to troubleshoot, this project is a really nice hobby which I enjoy spending time on!

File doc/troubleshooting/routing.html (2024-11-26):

# Trace debugging

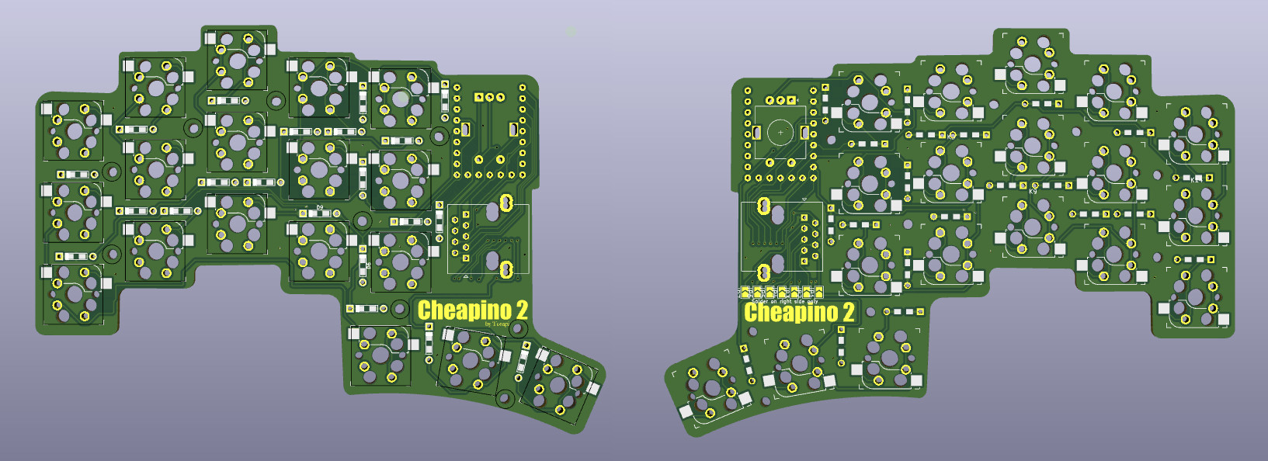
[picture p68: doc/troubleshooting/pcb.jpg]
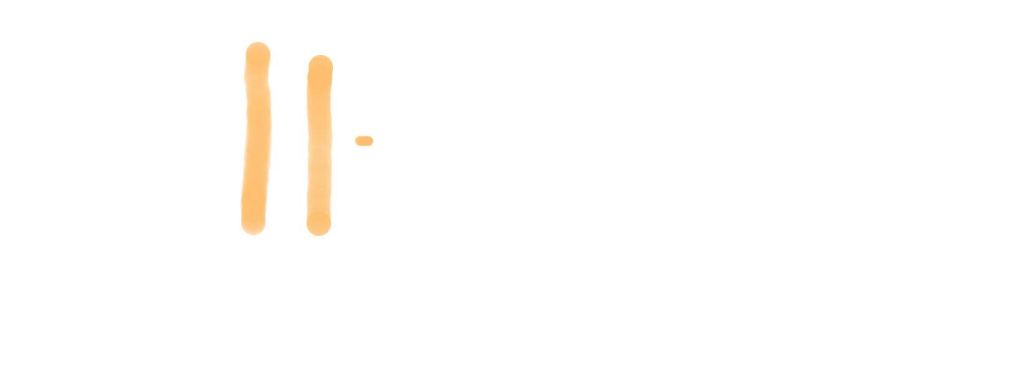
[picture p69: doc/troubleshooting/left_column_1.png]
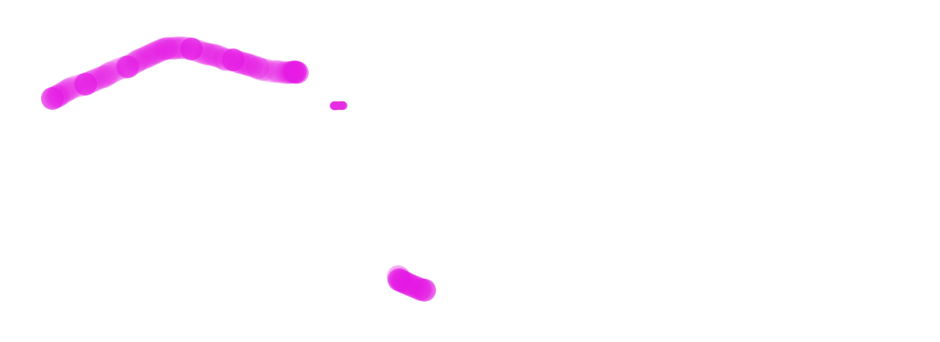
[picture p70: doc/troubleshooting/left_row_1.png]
              

Left | | Right
Rows | Columns | Rows | Columns
One | One | One | One
Two | Two | Two | Two
Three | Three | Three | Three
| | Four

Hide all Show all

If you are having problems with a row or a column, try to hide all others. When you only have the problematic columns or rows left, you can check all the highlighted solder joints.

You might try to short a column/row combo at the mcu(preferably out of socket). If this does not work, the mcu might be broken.

Next try at the left RJ45 socket, if this does not work, you should reflow the socket pins, and if that does not help, check for scratched traces...(you might get away with running a bodge wire if thats the case.)

Next try at the right RJ45 socket, if that does not work, try a few other cables, and next try to re-flow the pins.

Next try at the solder bridge points right above the logo on the right side.

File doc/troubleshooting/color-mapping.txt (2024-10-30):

#e519e4 Left row 1
#a6cee3 Left row 2
#2078b4 Left row 3
#33a02c Right row 1
#fb9a99 Right row 2
#e31a1c Right row 3
#b2df8a Right row 4
#fdbf6f Left column 1
#cab2d6 Left column 2
#b15928 Left column 3
#ff7f00 Right column 1
#6a3c9a Right column 2
#ffff99 Right column 3

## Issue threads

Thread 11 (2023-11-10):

Waiting for drive to deploy...

normausome, 2023-11-10:
Hey guys!

I am having an issue with it being stuck at "Waiting for drive to deploy" when I run `"make cheapino:default:flash"`. not sure why this would be happening. I see the rp2040 being listed when I run "lsusb".

Thanks!

tompi, 2023-11-10:
Hey!

Did you power on the rp2040 while holding down the boot button?

Or hold boot and press reset

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

tompi, 2023-11-10:
It should show up as a usb drive if you manage to put it in dfu mode

On Fri, 10 Nov 2023 at 23:14, Thomas Haukland ***@***.***>
wrote:

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

normausome, 2023-11-10:
Hey! so just got it working. flashed it on my mac instead of ubuntu. so i ran `"make cheapino:default:flash"` and it wrote to the MCU,  but now it doesn't type. i see the LED indicator on though!

normausome, 2023-11-11:
would i have to flash it with the RJ45 plugged in?

tompi, 2023-11-11:
No, shouldnt have to do that…

So no keys Are working?

Did you test the miryoku uf2 file?

If neither Are working, maybe post some pics of the board, might be some hw
trouble?

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

normausome, 2023-11-11:
yes, no keys are working. i need to get a multimeter to test the connection to the keys....

tompi, 2023-11-11:
Send some good resolution pictures of the board. Might be able to spot
problem by visual inspection

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

normausome, 2023-11-11:
got it! so left side works, but right side doesn't - just had to resolder some of the diodes correctly. sorry this is my first time!

time to figure out what is wrong with the right side.

tompi, 2023-11-12:
Try another rj45 cable and if it doesnt help, post close ups

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

normausome, 2023-11-13:
ok so what i did was desolder switches and try it out on a new board! thanks for the help!!

Closed 2023-11-13.

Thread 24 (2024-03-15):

Issues with X, V, U and O

mkw432, 2024-03-15:
I have two builds going and can't identify any soldering defects but on both boards the X, V, U and O keys (in standard QWERTY layout) don't work. I'm guessing the mirrored problem keys are due to the Japanes matrix layout. Any suggestions for where I should have a closer look?

tompi, 2024-03-15:
Thats strange!

Just to rule out fw issues: do these keys work if you Flash the miryoku uf2 file?

If same problem there, could you post some high res images of both sides and halves, preferably with keycaps off...

tompi, 2024-03-15:
Oh, and the mirroring is probably because of this row is mirrored over the rj45.

PERHAPS its worth trying a different cable, not sure what effect a crossover cable will have on the matrix...

Anyway, test the precompiled uf2 file first!

mkw432, 2024-03-15:
Thanks so much for the quick response (and let me know if easier/better to discuss this elsewhere)!

I'm beginning to suspect it's a problem with my soldering or (less likely) the PCB from JCPCB. After cleaning off some flux mess with rubbing alcohol and a close inspection, one of the boards worked briefly and now is ghosting a bunch of keypresses on certain keys (e.g. QWERTY "I" hits Y, I, P and  Z, C, B. Could it be my cheap Ali Express diodes (probably using a handful from two different orders)?

I'll upload pics of the top half in just a few after I take off the keycaps. Thanks again!

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

mkw432, 2024-03-15:
Sorry - also meant to add that I tried the Miryoku .uf2 and also compiled/flashed the default QWERTY firmware but the broken keys didn't work with those either. Likewise couldn't get a response by jumping the pins on the switches that weren't working. I do have a multimeter I could use to test for continuity but the unique matrix (which is super cool BTW) is  beyond my ability to follow and diagnose by myself. Any guidance there on what I should check (or a doc you could point me to that might help me figure out how to test)?

I did use kapton tape under the RJ45 connectors on this second build (first build was just masking tape) but that didn't seem to make a difference. I also have a bunch of SMD 1N4148W-TP diodes I could try to swap in if you think that might help. Thanks again!

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

tompi, 2024-03-15:
Your soldering looks very neat, I dont think thats the issue.

Could you use a multimeter to verify that each of the pins is the problem switch connects to exactly one pin of the rj45 connector?

Make sure to switch polarity if you think you find one missing(you might be checking against the diode...).

I actually got a pcb with a broken trace once from jlcpcb, but i thought it was very rare... but thinking about it, you said it started working after cleaning...

Oh,and the "ghosting" is probably just the encoder not de-tenting properly. It happens. Just twist it slightly and see if it stops.

mkw432, 2024-03-15:
With the positive probe on the top switch pin, I get a connectivity beep on exactly one RJ45 pin for both of the broken switches on the right half top row (U and O). The bottom switch pins for U and O show about 0.7 MΩ of resistance on exactly on RJ45 pin each (but don't beep). I noticed that at least one of the working switch pins in the middle row (maybe others too) shows various resistance numbers on multiple RJ45 pins. Could that be contributing to the issue? Do the left half switches connect to the RJ45 as well - if so, I'll test those too.

I also wondered if maybe I have a solder bridge between the MCU holes and the bigger holes for the thick "legs" of the encoder. Might be either a bridge on the right half (e.g. between the actual encoder leg and the unused MCU hole) or on the left half (e.g. between the actual MCU socket pin and the unused encoder leg hole). Could that contribute to the issues I'm seeing?

tompi, 2024-03-15:
I think its good to just focus on left, sure.

If you got a bridge, i guess there might be continuity between the pin and ground?

mkw432, 2024-03-15:
There is continuity between most of the "bottom" pins and ground! The few that don't have it are working. Does that mean I've got a bridge somewhere?

tompi, 2024-03-15:
Yep, that should be the problem. But most? Seems strange that there should be many?

mkw432, 2024-03-15:
Sorry should have clarified that the bottom pin on most of my switches has connectivity with ground on the RP-2040. But a couple of them don't and the ones that don't are among the keys that are working just fine (but many of the others that work fine also show connectivity to ground on that bottom switch pin).

mkw432, 2024-03-15:
Could it be a bad batch of RP-2040s from the AE seller I bought from?

tompi, 2024-03-15:
Highly doubt that.

Did you order pcbs from the "release" gerber, or did you make the gerber yourself with kicad?

I had to break out my own multimeter here and test on an empty pcb, there is definitely no continuity between ground and any other traces. Could you check that on your remaining empty pcb to rule out a bad batch?

If thats ok its probably a soldering issue.

Can you tell me exactly which pins are connected to ground?
If its the same pins as the encoder is using, you might examine that: pin 1-4, starting from upper right outside corner of left side.

mkw432, 2024-03-15:
Hmm couldn't find any continuity with ground between any of the switches/diodes on the empty PCB. For the boards I built, the ground connection seems pretty weak and only shows up with the red/positive probe on GND and the black/negative probe on the switch pin or near side of the diode. I have to use the continuity function - the connection seems too weak to register on the multimeter's lowest resistance mode. But weirdly I have a completely functional Ocreeb macropad I build with a similar MCU (KB2040) that shows the same behavior - there is a weak connection between GND on the MCU with half the switch pins and the other half have continuity with the probe on the near side of the diode. Both of my Cheapinos and the Ocreeb all show a weak connection between the GND pin and each of the other MCU pins as long as I put the + probe on ground and use continuity mode. Is that not normal?

tompi, 2024-03-15:
Im not really sure... Could be the resistance of the diode?
What do you measure them to? (in both directions)

Could you do one more test. If you short pin 2 and 5 on rightmost(outer) line of the rp2040, starting at the top. you should get "x" and "c"

I assume you attempted to short the switch both "before" and "after" the diode?

Still exactly same behaviour on the two left halves?

You said it started working shortly at one point?

mkw432, 2024-03-15:
Shorting the pins marked 2 and 5 gives me "A" and the middle key on the left thumb cluster (which I assigned to layer tap with space on tap). I think X and C are pins marked 1 and 4 (which are the second and fifth pins so that's probably what you mean)? But shorting those only gives me C (which is a key that's working) but not X (which is a key that's not currently working). Does that mean it's likely a firmware/software problem?

mkw432, 2024-03-15:
So it looks like on this particular board, one of the two keys connected to the GP4 pin isn't working. That's X (GP4, GP1), V (GP4, GP0), Left key on left Thumbcluster (GP4, GP2), Left key on right thumbcluster (GP4, GP27), U (GP4, GP29) and O (GP4, GP28). Weirdly on the other board, it's now showing a completely different issue where the keys connected to GP6 (QWERT, NM,.?) and the rightmost keys on both thumbclusters are either doing nothing or going bonkers with outputting a bunch of keys in the list.
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
mkw432, 2024-03-17:
Hmmm - I commented out those lines and both "qmk console" and hid_listen can now connect to the Cheapino but no debug output comes through. I was trying to see if I could add a print statement to process_record_user() like the example in the QMK debug FAQ but I couldn't find a process_record_* function in your QMK folder. Probably due to the default keymaps using the QMK configurator .json files rather than the old fashioned keymap.c I'm used to.

tompi, 2024-03-17:
You meant commented in, right?

This is very interesting, you Get some debug info? Like the name etc when plugging in?

What command do you use to compile/flash?

I was also thinking, shorting gp1 and gp4 giving only 1 key makes no sense. Did you socket the controller? If so could you try shorting with it out of the keyboard? If its still faulty, with another usb cable and possibly on another pc/tablet/phone

mkw432, 2024-03-18:
Yep, sorry - I meant commented in those lines by removing the pound sign. The debug info just shows the name of the board and then listening but nothing else. QMK Toolbox actually shows your name. Weirdly if I assign the QMK debug toggle to the first key (instead of KC.Q) it will show up as debug on or off when tapped but otherwise there's no debug output at all.

mkw432, 2024-03-18:
I've just been using "flash -kb 0cheapino -km default" (manually saved your Cheapino directory at the top of my QMK keyboards folder by appending the zero). Finishes compiling without any errors and then waits for me to enter DFU by hitting Boot + Reset on the RP2040-zero and finally flashes without any errors.

mkw432, 2024-03-18:
Ok so I found a keymap.c for the Cheapino here: https://github.com/JordanNiphan/CheapinoQMK/tree/main/keyboards/slaet and using that was able to get the debug working by adding the code snippet at the bottom to keymap.c (snippet from the QMK debugging FAQ). I also added a define to config.h for it to display the matrix scan frequency (looks like it's usually around 3100 on mine). I get output along these lines for all of the working keys (though the 6 that aren't working don't output anything in the debugger). When I short the 1 and 4 pins, for example, I only get one key press (the "C" key but not the "X" key) - though shorting other pin pairs generally registers two different key presses except the 6 keys that aren't working, which only gives one key press. It makes no sense! I did order a few more of the RP2040-zero since they're so cheap so I'll let you know when they arrive if swapping a new MCU in resolves the issue. Otherwise I'm out of ideas and really appreciate you all of your help with troubleshooting, etc. Thanks again!

```
Keyboard: KL: kc: 0x0014, col:  4, row:  0, pressed: 1, time: 18951, int: 0, count: 0
Keyboard: KL: kc: 0x0014, col:  4, row:  0, pressed: 0, time: 19107, int: 0, count: 0
Keyboard: matrix scan frequency: 3135
```
FYI - here's the debug code I added to keymap.c to get the above output.

```
bool process_record_user(uint16_t keycode, keyrecord_t *record) {
  uprintf("KL: kc: 0x%04X, col: %2u, row: %2u, pressed: %u, time: %5u, int: %u, count: %u\n", keycode, record->event.key.col, record->event.key.row, record->event.pressed, record->event.time, record->tap.interrupted, record->tap.count);

  return true;
}
```

tompi, 2024-03-19:
Okay, Im starting to Wonder if this might be caused by gp4(row 3) being shorted to ground.

Could you check if k18 is also defunct? (This is the left/innermost thumb key on the left part)

Please check carefully if gp4 is shorted to ground somewhere, maybe the housing of the rj45 port or at the mcu soldering.

mkw432, 2024-03-20:
I think you were exactly right (K18 also wasn't working) but I couldn't locate the short anywhere. There were a few tiny nicks I made in the PCB that could've caused it. The good news is that I used a spare RP-2040 Zero on my last remaining PCB and moved over all the switches and now it's working perfectly! I also added the 3D printed case and plate (only on the left side) and am typing on it right now! Thanks again for all of your help.
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

tompi, 2024-03-20:
Yeah, if the nick tore off a track that might be the cause. Anyway really nice to hear you got it working in the end!!

Closed 2024-03-20.

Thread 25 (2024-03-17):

The first two columns on the right board don't work

barrosoman, 2024-03-17:
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

I'm trying to test the switches before installing the encoder on the right side but the first two columns of switches aren't working, I would like to know if the encoder is necessary for them to work or if I should troubleshoot/change the PCB.

tompi, 2024-03-17:
Should work without encoder. I see at least 2 diodes that Are noe soldered?

tompi, 2024-03-17:
Oh Yeah, and maybe try another cable in case its a crossover cable. I will make a troubkeshooting guide:)

barrosoman, 2024-03-18:
I found the culprit, it was the rj45 socket that I bought.

I didn't realize there was a difference between rj45 sockets and bought any. The pins of my sockets are shifted and they don't connect where they should.

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

As a temporary solution, until the correct sockets arrive, I used two wires to connect the pin to the right hole.

Below are the photos of my solution, on the occasion that someone did the same thing...

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

You may need to cut the path of the pin used in the left board, as it is connected to the first column of switches.

I'm using the Cheapino to write this text and I must say it is gorgeous! Thank you Thomas for the design and greetings from Brazil.

tompi, 2024-03-18:
Cool! However, i would check really careful if this is not a cable issue. Some networking cables have a few wires reversed.

I never heard of rj45 sockets doing this...

mauroue, 2024-03-20:
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

Hmm. I'm having the exact same issue.
Can you tell me where did you bought the new rj45 sockets? I have no idea what the differences are tbh.

tompi, 2024-03-20:
@mauroue could you please check a few different ethernet cables. I suspect both you and @barrosoman  have got an ethernet crossovr cable: https://en.wikipedia.org/wiki/Ethernet_crossover_cable

mauroue, 2024-03-20:
this is the cable I'm using
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

I don't think it is a crossover cable

tompi, 2024-03-20:
Wow, I think you are right. Could you post some closeups of your rj45 sockets?

Also, do you have a multimeter? If so, can you check connectivity from socket to socket with cable plugged in? If you get me a table with how it connects, I can probably create a firmware for your ports

mauroue, 2024-03-20:
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

I tested with a multimeter and it connects directly to the counterpart.
It would be greatly appreciated if its fixable by a firmware update, since I won't need to rely on my terrible solder skills

barrosoman, 2024-03-20:
Yeah, in my case the four back pins are more at the left side and the front pins are more at the right side.

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

At the pictures of the build guide, it seems that the corrected pins are the other way, (back pins to the right, front pins to the left).

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

With that said, I think that the problem from @mauroue is different, because his rj45 pins seems correct.

mauroue, 2024-03-20:
I think I soldered it to the wrong holes then haha

barrosoman, 2024-03-20:
I would reapply the solder because atleast at the photo, it looks like some pins are without solder or with just a little of it.

tompi, 2024-03-20:
I agree. But the position seems fine. As long as it Lines up with the white Lines on the mounting side you should be good.

tompi, 2024-03-21:
@mauroue , Rightmost 2 columns are all on the same trace going to the upper right pin on the controller. You should probably check this, and reflow it if it looks funky.

This trace is also exposed on the square hole directly beneath the rj45 socket(thats why the build guide recommends some tape here if you got metallic housing rj45 socket). You might try to squeeze in a little plastic or something and see if that helps?

mauroue, 2024-03-21:
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
I already had a tape underneath.

I checked the connections with the controller pin with a multimeter and they seem fine.
Is there anything else I can try?

tompi, 2024-03-21:
How does the mcu soldering look like? Could you send a pic of both sides?

tompi, 2024-03-21:
Oh, and yeah, to rule out firmware issues, flash the miryoku uf2 file, and test with that.

Try shorting gp0 and gp4 and see what you get(you should get 2 keypresses)

mauroue, 2024-03-21:
Ok, I'll try that later. At work atm.

Btw, thank you for your work and help!

mauroue, 2024-03-21:
Ok, I tried the miryoku file and when I shorted it did nothing. I'm guessing its the mcu then?

tompi, 2024-03-21:
Might be. But could be something on the pcb as well. Did you socket the mcu as suggested in the build guide? If so it would be interesting to pull it out and see if shorting registers then...

If not, maybe send a picture of the mcu?

mauroue, 2024-03-21:
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
the other side were pre soldered

mauroue, 2024-03-22:
I swapped to a new MCU and it's working now

thank you for.the help!

tompi, 2024-03-22:
Im glad to hear it!

I think its quite seldom these mcus break, they can really take a beating, but they might break sometimes apparently!

Closed 2024-03-22.

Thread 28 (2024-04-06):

Avoid routing through hotswap sockets

tompi, 2024-04-06:
If you rip off a hotswap pad that has row or column routed through it, you will need to bridge manually.

Fix this by routing through-holes only(more difficult to lift), or both(probably best).

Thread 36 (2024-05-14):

None of the keys work.

Federino, 2024-05-14:
Hi!

I am having trouble with the cheapini v2 build. I soldered all diodes with the MCU and the ethernet port. After that i decided to solder one switch and test if everything I did works before soldering everything else, but I don't get any output after pressing the switch.

I tryed the default software and the miryoku.uf2 as well, but none of them work.

If i go to vial.rock website it detects the pcb as Cheapino, but when I try the matrix test the button doesn't work.

Do I need to solder all the components before trying?
I am sending pictures as well so you can see the PCB.
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

I tryed the troubleshooting points, but I can't seem to make it work.

I also used a tester to check the diodes and they seem fine. I also soldered two switches in order to check if one of them is faulty.

If you need more information please let me know. Thank you!

Federino, 2024-05-15:
Update: It seems like 4 of the keys work. Maybe I have the other diodes not polarised correctly, I will try and resolder everything this afternoon.

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

tompi, 2024-05-15:
Hi. You definitely have some bad(a few cold) solder joints which could cause problems.

Try removing excess solder and reflow. When you got it looking nice, let me know if there is still problems and we can debug a specific trace with a multimeter(but I think its solder joints now...)

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

Federino, 2024-05-19:
Hi!

I'm really sorry for the late reply, but I didn't have time to fix it until today, and I MADE IT WORK!

It turns out that I had a few things soldered incorrectly:

1) I tryed to use the female conector for the MCU and I did a bad insert of the male "sticks" and they ended up not making contact correctly, which is why none of the keys worked. To solve this, I resoldered the entire chip and It worked perfectly.

2) After I managed to fix that I found out that the top row of the left part was not working either. After some debug of the PCB I found that I did not bridge correctly the right side of the PCB, so I redid that part as well.

After that I managed to make everything work.

I thank you so much for the support and this amazing product!

Closed 2024-05-19.

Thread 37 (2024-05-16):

Index and Middle finger columns stop working

BradyJ27, 2024-05-16:
Cheapino v1 btw.

Pretty consistently the two columns on the right board stop working for like 30 seconds or so. I've checked all of the solder points and I think they're all fine. I've also used both QMK and Vial, results are the same.

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

I've removed the keys that stop working. (Also, they all stop working and start again at the same time)

tompi, 2024-05-16:
Hi. This sounds very annoying. Did you also check the soldering on the left part? Could you send a picture both sides of the left part also? These two columns both end up in one trace going through the rj45 socket ti the other side and into one pin of the mcu.

BradyJ27, 2024-05-16:
Thanks for the quick response!

I don't see anything wrong with the solder on the left, although it's not pretty I don't think it is causing issues. Attached are two pictures of the left side.

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

tompi, 2024-05-16:
Looks pretty good. I agree. When this happens, is it related to the encoder? Does it help turning the encoder?

tompi, 2024-05-16:
Ill dig out the schematics tomorrow and find the trace for this column. Typing from my bed and my wife is annoyed;)

BradyJ27, 2024-05-16:
> Looks pretty good. I agree. When this happens, is it related to the encoder? Does it help turning the encoder?

As far as I know, no. It happens when I am just typing and not touching the encoder. I haven't tried to use the encoder to fix it, but I will try when it happens again.

No rush on resolving this, thanks again!

tompi, 2024-05-17:
Hi again, I checked the layout for v1, and these two column are both mapped to column 1(with different diode directions per physical column).

Column 1 is routed through the square rj45 socket holes, so I would recommend you reflow these(especially the one on the right side seems a bit blobby, but hard to tell from pic: might be a cold joint).

The trace ends up at pin 4 on the mcu, counting from top left(marked 29). Try reflowing this as well, maybe add a little solder, seems a tad sparse maybe.

Also, cant tell if you socketed the mcu, but if you did, it might be worth a try to gently pry it out, and check if leg at 29 is shorter than the others(ie was not pushed entirely in when soldered)

BradyJ27, 2024-05-17:
Thanks so much! I've reflowed the square socket holes and the 29 pin. I don't _think_ the 29 leg is shorter, so I left it for now. I will try this if the issue keeps occurring. So far so good though!

Closed 2024-05-21.

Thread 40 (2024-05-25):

Stuck keys Issues

ConnorMorehouse, 2024-05-25:
First of all, thank you so much for the work you've put into this project and the continued support! I'm incredibly excited to get this up and working.

I put together my first attempt this weekend, but I ran into a small problem. On the default key map, the . and h keys show as always pressed like the picture below. When I actually do press them there is no change.
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

I am submitting an issue only because I only see other issues about keys not registering, but not about keys always registering. It has been a long time since I soldered, so I wouldn't be surprised if I did a bad job. I checked with a multimeter and the switches are constantly shorted with no resistance between the leads. I have tried to remove excess solder and to reflow the solder for quite a while, but nothing has changed.

Here's how the solder joints look now. I think I might have done a little bit of damage to the board and switches by trying for too long to fix it, which is why I've stopped.
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

One thing that seems weird to me is that if I press the stem of the switch towards the top (parallel to keyboard pcb plane in direction of finger extension) of the keyboard, the key no longer registers as pressed and this is consistent.

I have a feeling that the switches could be broken, but I wanted to check first before I bought new switches or tried to redo anymore work. I don't know what else to try besides new switches

If there's anymore info you need to help, obviously just let me know. I get the feeling this is probably a quick fix, I'm just at a loss.

If this isn't the correct place for this request, I apologize. If you could point me in the right direction that would be appreciated.

add-on:
As I've continued to mess with the kb, I've found that the p key gets stuck down but isn't always firing. Makes me more suspicious of the switches.

tompi, 2024-05-26:
Hi! This is a bit rare yes, I have yet to actually hear about broken switches(always on), but this seems like its the case...

Since the Cheapino uses a duplex matrix, a short will typically result in 2 adjacent keys being pressed. And the only place you can realistically acheive a short is on the mcu or on the rj45 connector.

A few things to try first: all the other keys work on both sides?

Could you test a different cable between halves?

And could you send a pictur of soldering mcu on both sides of the other half, and also the rj45 soldering on the other half?

And i assume these keys turn off when you unplug the right half?
(You can plug/unplug while powered on)

ConnorMorehouse, 2024-05-26:
Thank you for your response!

Yes, all other keys work as expected.

With a different cable the same behavior happens.

Yes, when I unplug the right half the keys turn off.

Here's the picture before I tried reflowing the solder on the mcu
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

And here's after
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

I also reflowed the solder on the rj45 jacks, but didn't think to get pictures of the before. Here's how they look now
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
Left hand/mcu side

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
Right hand/encoder side

I know I used a little bit too much solder, but I think they should still be viable.

After reflowing the keys are still always on, they still turn off when I disconnect the ethernet cable.

It is seeming more and more like it's the switches, which is a bummer.

Do you think that applying the soldering iron for too long and creating too much could've heated up the components of the switch enough to damage them? Maybe warp the internal metal contacts such that they are now touching when the key isn't pressed? What made me think of this is the fact that when I press laterally on the stem of the switch toward the top of the keyboard, the switch will register as off.

Once again, I want to say thank you for the response and the help!

tompi, 2024-05-26:
Might be.

Did you try removing the key cap and maybe blow some canned air in it? (Maybe some debris is stuck?)

It can be a bit tricky to desolder a switch, but its not that difficult.

If you Measure continuity between switch pins, Even unplugged from mcu side, i would try this.

If you have some solder wick or a solder pump(the ss-02 is very good), Watch some YouTube videos on how to do it.

What baffles me is that this happened with 2 switches...

How long do you estimate you had the iron on the joint? And what temperature?

ConnorMorehouse, 2024-05-26:
With the right board completely unplugged, there is no resistance between the leads on both of the affected switches.

Compressed air didn't seem to do the trick.

I have ordered a solder pump and will be trying to remove the switch to test on it's own when it gets here.

It's hard to remember exactly, but probably between 5 and 10 seconds at 370 C with a chisel head tip. I don't remember specifically spending more time on these switches than any other. There are other switches that I definitely did spend more time on and they seem to be fine. I did the full left board with mcu first and it went slower as I was getting comfortable soldering again.

I will probably be buying some replacement switches if the switches still have no resistance between the leads off the board.

Thank you again for your help in this. I recognize this isn't an issue with your work, but probably my fault so the continued help is much appreciated.

ConnorMorehouse, 2024-05-27:
So I have removed the switches from the board and taken the switches apart. I seems that some solder had wicked up the lead and into the switch itself and was shorting contacts in the switch. As the solder was at the bottom of the switch I wasn't really able to remove it, but taking the switch apart and blowing compressed air inside seems to have done the trick.

I tested all the switches after cleaning and they were working fine. I soldered them back on and tested with the multimeter and they still were fine so I got into vial and tested them and they were no longer stuck on.

I didn't even think about soldering wicking into switch, nor did I think it was possible but the switches I bought don't seem to be fully sealed around the leads so it's possible.

Now that I have everything working as expected I am very excited to get set up and used to my new keyboard! I have already ordered another set of switches to build another keyboard with a different feel (linear, this one is tactile). Thanks again for your help, have a great week man!

tompi, 2024-05-27:
Good to hear you figured it out! I would really appreciate a picture of the finished build :)

ConnorMorehouse, 2024-05-27:
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
Here is the finished kb, and I typed this on it!

tompi, 2024-05-28:
Nice! The blank keycaps looks good, do you have a link?

ConnorMorehouse, 2024-05-28:
Ya! Here you go
https://www.aliexpress.us/item/3256803835640361.html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

glebino, 2024-11-14:
I have same issue, but it's something with mcu. I've unplugged it, and it still shows sticky buttons on matrix test

glebino, 2024-11-14:
Thanks! I think it was it. Accidentally destroyed trying to fix that today 😢. Well, have to order another one...

tompi, 2024-11-14:
If you find the bridge you might be able to fix with some wick.

Alternatively you might reroute traces with bodge wires, but that requires some hacking;)

glebino, 2024-11-14:
It's stopped booting at all, I think I've overheated the MCU

glebino, 2024-11-14:
Thanks for your help, and amazing job developing all this.

Closed 2024-05-27.

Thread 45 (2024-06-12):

Hard time understanding MCU pin labeling: is it me?

sistrall, 2024-06-12:
Hi!

Cheapino is such a nice project! Congratulations, and thanks a lot for sharing it with the community. :-)

I'm about to build a Cheapino V2, and I'm having some problems figuring out how the MCU pins are used for the right side of the keyboard.

Here is what I tried. I just received all the materials, including the RP2040-Zero. I dropped https://github.com/tompi/cheapino/releases/download/v2.0/cheapino_vial.uf2 on it, and I started tinkering with a pair of tweezers and Vial to understand how the matrix works: I wanted to see which pin couple is used for each switch. When I short pins, I see two switches detected at the same time: I understand that that happens because I don't have the circuit with all the diodes and Cheapino uses a Japanese matrix.

When I short a couple of pins for the left side of the keyboard, everything works as expected. But when I try with the pins for the right side (i.e. pins from 0 to 6) I something different from the schematics that I opened in KiCad. As an example, if I short pin 3 and pin 6 I have the K1 switch on the right side (so the inner one on the top row) and the one beside it detected on the matrix checker: according to the schematics, I was expecting to see those switches detected by shorting pin 0 with pin 3, but that's not the case. Could you help me understand what I'm doing wrong?

tompi, 2024-06-12:
Hi, yeah, two keys, because you are bypassing the diodes in place for this.

No wonder you are having a hard time, I always struggle myself when I revisit this :)

It all stems from the board being reversible, and the rj45 connector reusing SOME of the holes on both sides.
To allow placing the rj45 footprint on both sides, I have to lie to kicad about one of the sides...
(through holes have to have same net to be placed on top of eachother)

I should have fixed the naming at the mcu at least, but I didnt... I made a ticket for it here:
https://github.com/tompi/cheapino/issues/42

Anyway, to test keys, try shoring switch pins.

Oh, and dont forget to send me pictures of the finished build :)

tompi, 2024-06-12:
Basically the order of the rj45 cable wires is reversed when passing between the boards. Fixed in qmk mapping, but is wrong on the schematics(and to a certain degree, it has to be, but I could label it better)

sistrall, 2024-06-13:
Oh, thanks @tompi , now I get it. I think I need more expertise to understand these details just by looking at KiCad schematics! :-)

tompi, 2024-12-29:
This will be handled by #42

Closed 2024-12-29.

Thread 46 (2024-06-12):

Vial configuration files not working

seluranen, 2024-06-12:
Hi there! This project is awesome, congratulations!

Just finished building my first one (V2, great guide by the way) and flashed the vial config, and only "cheapino_vial.uf2" worked for me.
Am I doing it wrong? All the other are install3d by boot starting and then drag and drop the file?

Thank you very much!

tompi, 2024-06-12:
Hi! The other files Are not vial builds, but regular qmk with miryoku or a simple default.

Are they not working at all?

seluranen, 2024-06-12:
My bad, I was trying to update them with the vial configurator (facepalm)

Works properly!

off topic: any news with the wireless version? <3

tompi, 2024-06-12:
Good to hear! I havent had time to work on my zmk build... it was mostly just for fun, Im not that big of a ble fan. I will probably take it up again sometime this summer.

Im almost finished with a really nice case though(for hotswap).

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

Dont forget to send me Photos og your build!

seluranen, 2024-06-12:
Whoa! looks awesome!!!

Keep the good work, and thanks again for everything

seluranen, 2024-06-13:
Not yet totally finished, middle cable still on the way, and my 3D printer died two weeks ago so I'll have to order the plate some place (with hotswap the keys feel really flimsy). But I'm typing this with the cheapino! (at a painfully slow pace...)

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

Maybe the thumbs are a little bit high for my liking, I'll try to find a lower keycap (or maybe a keyswitch that still fits in the holes).
And possibly I'll try to move the knob to the thumb area. I'm a noobtard with electronics, so probably I will solder cables form the actual connectors to the new knob... I understand that the position in your design is a product of the symmetry of the board (and My, oh My! What a sexy symmetry. The design is brilliant!)

I'll keep you updated on the progress!

By the way, are you aware of these?

https://github.com/braindefender/KLP-Lame-Keycaps/tree/master

I prefer a more "geometrical" look, but the thumb one may be the solution, an a whole set prints at JCLPCB is like 6€!

tompi, 2024-06-13:
Good job on the build! Looks good, but Yeah, you need some sort of plate for hotswap.

Those lame keycaps look very interesting!

Ps. Ive been meaning to fix the searing bright green default on the led. You can map led controls to a layer and adjust color and brightness and it will remember it on future sessions

Closed 2024-06-12.

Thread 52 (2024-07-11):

A few notes for the ordering guide...

corbob, 2024-07-11:
I can absolutely put a PR in to add these notes, but just wanted to get the information out of my head here first:

The RP2040-Zero linked... If you get the one with headers thinking that you can just use them with the sockets... you will be wrong... and if you then think "oh well, I'll just solder it to the board, no big deal", you will be wrong a second time in the same day. The pins on the headers are too big for either the board or the sockets suggested.

The EC11 encoder linked is a listing with about 8 "sizes" or "styles" or however you might refer to it... You will absolutely want to order the actual encoders, and not just the knobs 😂

Now if you'll excuse me, I need to go desolder some headers 😬

tompi, 2024-07-13:
Hey, I know the headers can be a very tight fit, sorry about this...(in fact there is an open issue for this: https://github.com/tompi/cheapino/issues/29 ), but were you unable to push them in the pcb at all?

The different sizes EC11 encoders are only the height and type of shaft, all will fit the pcb. But yeah, I could specify you need both encoder and knobs...

tompi, 2024-07-13:
I would very much welcome a pull request, otherwise Ill put in an explicit warning about the pin headers.
Feel free to suggest other links as well.

I have used pin headers that came with the rp2040 myself, but only used the two long sides, never tried with all 3...
(I also suspect pcb manufacturer tolerances might play a role, seeing I made the holes a bit too small...)

HennoHimself, 2024-07-15:
I ordered from jlcpcb and the headers are tight but they fit with a good amount of force. I have built two boards now with the same ordering guide and it's fine.

br-lemes, 2024-08-11:
I bought the RP2040-Zero with the pre-soldered header. I needed to cut out the pins at the bottom. But I managed to fit it onto the PCB. Although it was hard and tight, but everything worked well.

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

djdanielsson, 2024-09-18:
Off topic a bit, @br-lemes what cables are you using in your picture? I'm looking for something more flexible than the normal cat6 cable that I am currently using.

br-lemes, 2024-09-19:
@djdanielsson the cable is this: https://aliexpress.com/item/1005006184311635.html

Closed 2024-11-10.

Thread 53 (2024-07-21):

Issues with keys not registering and one key registering 3 different key presses

ConnorMorehouse, 2024-07-21:
Firstly, thank you so much for you help and you work on this project! This is my second cheapino I've made, and I love my first one.

I am having a strange issue that I can't reason about, maybe two separate issues. All three keys on the ring finger of the left hand do not register. Also, when I press a key in the index column on the left hand, it registers three key presses. It will register the inner index (farthest right), middle finger, and pinky key in the same row as the initial index key that was pressed. It is always in the order of inner index, middle, pinky as well.

Triple key register example:

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

results in:
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

I have checked all the diodes on the board and they seem to be oriented correctly and registering the correct voltage drops. I have checked the switches and they are working correctly. I have checked that all pads have continuity to the MCU and they do.

I can't think of what else to do or check. If you could help me understand what might be causing this I'd really appreciate it.

I will probably be checking over the diodes again tomorrow.

tompi, 2024-07-21:
Hey! Send some high res pictures of both sides of the boards. Might be a short somewhere.

One thing to check is that there should NOT be continuity between any of the mcu data pins...

Also, which keys do not work at all?(maybe circle them in a pic)

ConnorMorehouse, 2024-07-21:
Thank you so much for the quick response!

Sorry I think the way I worded things was confusing. There is no continuity between the data pins on the mcu, I mean that each switch did have continuity to a data pin, even the switches that never register presses.

Here is the front of the board.
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

Here's the back of the board.
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

Here's a close up of the back side of the mcu.
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

And here's the column of keys that never register a press.
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

I wouldn't be surprised if it was a short that I'm just not seeing.

Let me know if there's anything else I can provide to help, and thanks again for your help.

tompi, 2024-07-21:
Hey. Im travelling so a bit limited;) but Linda Looks like there is a short on the underside of the mcu, between the unused encoder Hole and one of the pibs(can only see one side...)?

I think this unused Hole is gnd, so it might render one column permanently on/off.

ConnorMorehouse, 2024-07-21:
No worries. I'll try to clean that up soon and get back to you with the results.

Thanks again, and have fun on your travels!

ConnorMorehouse, 2024-07-21:
I have reflowed the solder on the suspect pin, but the behavior has not changed. I will be downloading the kicad files to see if If can better understand what connections are being made and what the intended connections are.

I also retested all of the diodes and they seem to be oriented correctly and have the correct voltage drops so I think they're fine.

I very much appreciate your help, but this is not an urgent issue. I have another working cheapino and don't even have the key caps in yet for this new one.

tompi, 2024-07-22:
This looks like it would pull down row2:
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

Is problem nr 1 still there after this bridge is removed?

ConnorMorehouse, 2024-07-22:
Here's an updated picture of the mcu pins. I think I have fixed that issue, but the behavior of the keyboard has not changed.
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

tompi, 2024-07-25:
Hey, do you still experience both issues? (one column not working, and middle key triggering 3 key-presses?)

Since the soldering looks ok, I was just wondering, did you test the keys with a tweezer/wire, without switches?

ConnorMorehouse, 2024-07-26:
Yes, unfortunately the behavior hasn't changed at all. I tried with a small wire over all the keys and got the same results. The column 2 pin has continuity to ground.

I am looking over the schematics in kicad and I don't see any components that are supposed to be grounded other than the RJ45 shielding. And the only components that have continuity to ground are connected to pin 2. Unless I damaged the solder mask very badly somewhere but can't see it after looking very closely for a couple hours, then the only way I can see the pin connecting to ground is through the mcu.

I have also started getting errors from my computer that the usb port it's connected to is drawing too much power and turning of the usb connector. It's not super consistent, but almost 50% of the time probably.

tompi, 2024-07-26:
OK, that should be pretty easy to verify: just check for continuity between gnd and the pin with the mcu out of its slot.

If there is still continuity, the problem is on the pcb, else its on the mcu.

ConnorMorehouse, 2024-07-31:
I apologize for the delay, as I have been busy. I removed the mcu today and there is continuity between the pin and ground pin with the mcu removed. I have ordered another.

Thank you so much again for your help in diagnosing this. I've really enjoyed my first and I look forward to enjoying my second as well. I appreciate your continued support and development on the project, and am looking forward to v3 :)

Closed 2024-07-31.

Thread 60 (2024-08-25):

Encoder button always on

ihales, 2024-08-25:
Thanks for sharing such a cool project! I built my first last night and loved it.

I've ended up with one problem- appears that the encoder button is always depressed, even when the right and left halves aren't even connected.

When I connect the two sides, none of the encoder interactions register.

I don't see any obvious problems, and I'm not sure the best way to troubleshoot. I'd love any pointers.

Here are photos of the front and back of the left board.

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

tompi, 2024-08-25:
Hi! Dont know which firmware you are using, but I would suggest trying the vial fw, without right half connected.
If you go to the test section there, is the encoder indicating press?

The pins on the mcu seems like they are not solidly connected to the hole? Maybee too little heat, or no flux? But that should not cause the encoder issue anyway...

P.S. Im a bit baffled by the bumper placement, are yours lower than your hotswap socket height?

ihales, 2024-08-25:
Thanks so much for the response. Using the vial fw with only the left side connected, this is what I get:
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

Thanks for the feedback on the MCU soldering - this is my first real soldering project so the suggestions are super helpful! While working on it, I did accidentally bridge one of the pins to the big encoder hole (on the left, if you're looking at the bottom), but I think I got that cleaned up.

And yeah, with the bumper placement, I put a first round directly on the PCB, but then there were a couple of places where it wasn't high enough, so I tried putting bumpers on the hot-swap sockets. I imagine it'll probably stress the sockets, so probably not ideal. I might try to print a case to help out.

Anyway, if nothing comes to mind, no worries. I have parts for another and I'll just give it another shot!

tompi, 2024-08-25:
Ok, seems like you socketed the mcu?
Worth a try to take it out carefully, and then plug in usbc cable in the rp2040-zero, and see if you get the the same result in vial.

If you do, there is something wrong on the rp2040, either your soldering, or the mcu itself. You can then try with your other mcu, should work...

If it doesnt happen, should be something on the pcb.

If you have a multimeter, you could check that there is NOT continuity between any pins on the mcu socket...

ihales, 2024-08-26:
I tried taking the MCU out and several pins came undone (the sketchy soldering you mentioned, so doubt). The MCU alone was fine and the sockets checked out. I just put it back together and resoldered the MCU and it started working!

Thanks for the suggestions and help. Here's a picture of the finished product!

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

tompi, 2024-08-26:
Great!

Looks really good with those keycaps.

Good luck with the typing, now the hard part begins;)

Closed 2024-08-26.

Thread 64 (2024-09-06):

Question: Are the magnetic USB-C safe?

Batres3, 2024-09-06:
I've read that magnetic USB-C is not compliant, and I've heard of a couple of people who have had issues. Has anyone here had any issues? If so are there any alternatives?

I'm specifically referring to non compliance with USB-C specifications as mentioned in this thread https://www.reddit.com/r/UsbCHardware/comments/motlhn/magnetic_usbc_cables_are_not_recommended/

soul-wish, 2024-09-06:
I have two Cheapino V2s with magnetic connectors, and so far, I haven’t had any issues with them. So I'm not sure what you're referring to @Batres3

Batres3, 2024-09-06:
@soul-wish sorry I wasn't very clear I updated the message

tompi, 2024-09-07:
Did not have any issues... Was a guy at reddit which I suspected might have some bad magnetic usb-c cables(his board was heating up...), but he never replied back...)

Ive been using mine(branded "Elough") for years without issues, I love them!

Only time there was a problem was when a diode leg got stuck shorting the pads. Did not cause any damaged, just removed it...

Batres3, 2024-09-07:
Ok! I think it should generally be ok to use magnetic cables with keyboards because of the extremely low power draw, still wanted to bring this up just so people know.

Also, thanks for adding the warning @tompi !

Closed 2024-09-14.

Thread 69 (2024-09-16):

Im new to this and this was my first ever build, so I have a couple questions

jcs021102, 2024-09-16:
1)
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
These are my functioning keys (light) vs non functioning (dark)

MCU Pics:
https://imgur.com/a/MEPylSY

2) for miryoku_zmk, what's the board name? I want to try Miryoku w/Colemak mod Dh, but I have no clue what the settings are supposed to be

tompi, 2024-09-17:
Hi!

For nr 1, could you post some pictures of both sides of both pcbs?

Especially the bridge pads on the right side. Wondering if its a combination of missing bridges and  wrongly oriented diodes.

For nr 2, cheapino is not compatible with zmk, but you can use miryoku on it. Did you check out the firmware guide?

jcs021102, 2024-09-17:
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
Updated matrix test (As I had forgotten to solder a keycap)

Images with keycaps attached
https://imgur.com/a/t9qJYaK

Ill send an image without the keycaps in a minute

jcs021102, 2024-09-17:
yeh, diodes are all well and good, I also tested the rj47, as well as the microcontroller. I dont have another rj47 on hand, but its the one I use to connect my landline, so it should be functional.

Im unsure what it means to short the bridgespots

tompi, 2024-09-17:
I mean shorting the soldering pads referred to in section 3 of the build guide.

Are you able to trigger some of the missing keys if you short these?(just do 2 and 2 at a time)

Rj45 cable could still function as Ethernet but fail in the cheapino if its a crossover...

jcs021102, 2024-09-18:
I found that when shorting between the mcu and the hotswap soldering pads of the functioning keys to be connectivity  present, and of course the non functioning ones do not. Everything else seems to work, just fine.

It is worth nothing that I did solder on 6 hotswap pads in the places where the keys connected, but removed them due to particular reasons. Could this affect things?

tompi, 2024-09-19:
Hey. I meant the 7 solder pads on the right side. Check section 3 of the build guide.

If you short 2 of these at a time, Are you able to trigger missing keypresses?

jcs021102, 2024-09-19:
I'll check when I get home tonight. Just to make sure I understand, if I
short the 7 solder pads keypresses should occur, and thus if they dont, it
would imply an issue with the board itself correct?

On Thu, Sep 19, 2024 at 6:42 AM Thomas Haukland ***@***.***>
wrote:

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

tompi, 2024-09-19:
If shorting triggers it means the fault is on the right side, probably diodes put the wrong way.

If it doesnt short, you should start searching on left side: short the pins of the rj45 connector. If it shorts its cable or right connector.

If it does not short its pcb or mcu

jcs021102, 2024-09-19:
shorting the 7pads led to these firing:
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

the other far right keys still work when manually pressing them

tompi, 2024-09-20:
I should have been more clear. I meant to short every 2 combinations of these pads. So start with the first pad, short it with the other six. Then take the next and short it with the following 5 and so on. So 6+5+4+3+2+1 combinations.

jcs021102, 2024-09-20:
Yes, that is exactly what I did

tompi, 2024-09-20:
ok, it should not be possible that some keypresses are activated by regular keypress, and not by shorting(I thought... Very strange...).

Anyway, this should indicate that the problems are not at the keyswitches.

Now do the same exercise on the pins of the left rj45 socket. If those work, I would guess the cable is the culprit.

jcs021102, 2024-09-21:
I just changed to cable a second time and everything works! With the exception of the knob..
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

jcs021102, 2024-09-21:
I just found out the middle button and knob work, it just doesnt show in vial!!
Thanks for your time and patience man, you are the best

tompi, 2024-09-21:
Great! The knob should register when you press it?

Turning it does not show up in vial, but should work anyway?

Closed 2024-09-21.

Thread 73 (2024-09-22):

Issue with right side, missing all but 8 keys

frantathefranta, 2024-09-22:
Hey, I just attempted to make my first Cheapino but I'm struggling with making the right side work. This is where I am currently (the empty on the left is a bad hot swap connection, works with shorting manually):
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.
I read through other issues and it seems that my problem is either the Right side pad connection, MCU issues or the RJ45 socket. I've tried multiple RJ45 cables but they all do the same thing.  What issue is this most likely? Thanks for any help.

Pictures of my (very amateur soldering):

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

tompi, 2024-09-22:
Hey! This could very well be bad solder joints on one of the rj45 connectors or the mcu...

If you short 2 and 2 pins on the left rj45 connector, can you trigger all keys?

If so, reflow both rj45 ports.
If not, reflow the right side pins of the mcu.

frantathefranta, 2024-09-22:
I guess this is some sort of a progress. I've reflowed the RJ45 ports and that didn't make a difference. Then I re-did the MCU (both the top and bottom) and got this:
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

More keys are registering but at the same time I've lost 4 (the knob now works fully though, previously it could only do the press). I guess I'll try again with the MCU.

frantathefranta, 2024-09-22:
Played around more with the MCU and RJ45 ports and got all the keys working finally. Seems to work better when there are big blobs of solder (which I thought wasn't the right way). Sadly my knob encoder stopped working (press works, spin does not).

tompi, 2024-09-22:
Hey. Encoder twist does not register in vial test page. Maybe they work in regular use? Page up/down is default i think.

For one key: kan you triggger på shorting pads. If not, does it register if you bypass the diode? Might be bad diode or bad switch or loose hotswap socket

tompi, 2024-09-22:
Also, checkout a soldering tutorial. I think you might be using too low temp or too little flux, but not sure.

frantathefranta, 2024-09-22:
Looks like it was a bad diode connection. Now I'm fully functional. Also I got confused by the rotary encoder because it worked in the VIAL (by scrolling the tabs), then stopped, then worked again. Might have been something to do with my desktop setup.
Anyway, many thanks for your assistance, I really appreciate it. Off to build a second keyboard.

Closed 2024-09-22.

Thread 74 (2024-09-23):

Compatibility/support for Seeed Studio XIAO?

LargeCrowd, 2024-09-23:
Hi tompi! I came across the cheapino while searching for affordable split keyboards and I'm super excited to eventually build my own! Really appreciate the effort you've put in!

I was just wondering if the pcb has support for the Seeed Studio XIAO rp2040, because I saw a photo of someone's build using it (although I can't find it anymore). Given its smaller form factor, i thought it might look nicer on the cheapino! (I also saw that you're thinking of working on wireless compatibility using a XIAO for the v3?)

I'm also curious what other improvements you're planning for the v3 and when you plan to release it :)

SadWitchBoards, 2024-09-24:
I don't find Xiao that inexpensive compared to the generic Nice! Nano. I got 5 for the price of one Seed Xiao ble.

MatthieuTricoire, 2024-09-25:
> I don't find Xiao that inexpensive compared to the generic Nice! Nano. I got 5 for the price of one Seed Xiao ble.
But on the generic Nice Nano, there's a battery drain issue, isn't there?

tompi, 2024-09-25:
Hey, I actually have a cheapino v2 partially working with xiao ble and zmk, picture of it here:
https://github.com/tompi/cheapino/blob/master/doc/images/orderingguide/keycaps.png

Here is the current zmk status:
https://github.com/tompi/cheapinov2-zmk-config

I just need some time to finish the zmk profile, I just started doing other stuff...
I will probably pick it up again this fall, when outdoor activities start being less pleasant...

I tagged some issues with v3, mostly minor stuff...
Would really like to get rid of all ghosting(although its perfectly manageble in firmware, I dont like it...)

Have been toying with the idea of adding leds and sound, but not sure the added complexity is worth it...

There is also some demand for a choc version and a 6th column, but it also demands sacrifices(choc support would probably mean i have to choose either hotswap or soldered...)

v3 is probably not coming anytime soon...

SadWitchBoards, 2024-09-25:
> > I don't find Xiao that inexpensive compared to the generic Nice! Nano. I got 5 for the price of one Seed Xiao ble.
>
> But on the generic Nice Nano, there's a battery drain issue, isn't there?

That was fixed in May and the current batches don't have that issue.

SadWitchBoards, 2024-09-25:
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

Sound: While neat, I think you're right about the complexity maybe not being worth it. I've got a few boards with this integrated and never use it and know others with the same feelings.

LEDs: I don't personally care about RGB and I think it takes away from the simplicity of the Cheapino as a beautiful budget board. Personal opinion of course.

Choc: what restricts this to solder? Could it possibly be compatible with choc V2? There has been a lot of movement in that version lately, including the best feeling and sounding low profile switches that I've used in the new all pom selections. Only difference is a larger Center hole in the PCB, which undoubtedly would cause a slightly larger PCB. Not sure if that's worth it to you.

So many considerations. Thank you for taking time to go through it all.

tompi, 2024-09-25:
> Choc: what restricts this to solder? Could it possibly be compatible with choc V2? There has been a lot of movement in that version lately, including the best feeling and sounding low profile switches that I've used in the new all pom selections. Only difference is a larger Center hole in the PCB, which undoubtedly would cause a slightly larger PCB. Not sure if that's worth it to you.

I was thinking I could maybe do some combination of choc(v2)/mx, but seems the center hole is different size? Then it would require completely differen pcb, and the case would alse be different... The routing would need to be completely redone and everything is just 2x the work...

azzamsa, 2024-09-26:
> Hey, I’ve got a partially working Cheapino v2 with Xiao BLE and ZMK! Here’s a picture of it:

Wow, I thought the PCB would need some modifications.

> I was considering a mix of Choc (v2) and MX switches, but it looks like the center hole is a different size. This would mean needing a completely new PCB and case, not to mention redoing all the routing. It’s basically twice the work…

I love the Cheapino for its simplicity, and I align with its "cheap" mission. Adding extra features that don’t enhance productivity feels counterproductive.

Personally, I never use LEDs, OLEDs, speakers, haptics, or wireless in any of my builds due to budget constraints, so the Cheapino fits my needs perfectly.

I think you might want to start using a `wontfix` tag or mention it in the README to avoid getting bombarded with feature requests that don’t align with your goals. Since it’s open source, people can always fork the project. You could even help them out in their own repo if needed.

You could merge forks that add things like LEDs or speakers into a `contrib/` or `mods/` directory, but it’ll add more work to maintain, and maintainers come and go.

I don’t plan to build a wireless keyboard anytime soon as I’m still searching for my "endgame" build. But if I do, and it involves the Cheapino, I’d likely fork it and reach out to you for advice if I plan to add more features.

azzamsa, 2024-09-26:
I think it’s best to keep Cheapino as it is. For a potential v3, maybe just add essential features like wireless.

Let Choc users fork it and give it a new name, like `cheapino-choc`, and the same goes for users who want a 6-column version.

LargeCrowd, 2024-09-27:
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

I agree. It has never occurred to me that these features are important to my typing experience (although, to be fair, I wouldn't consider myself to be that deep into the keyboard community at all).

I'd only just found this split ergo keyboard community recently and thought that it seemed niche and interesting!

Since I found the Cheapino, I've come across a few other split keyboard builds (mainly from Seeed's Xiao keyboard contest held a couple of years back) and personally, I found it really interesting how everyone implemented their own preferences into their designs, making all the keyboards different!

@tompi I appreciate your hard work and I hope you continue to find joy in it as you work on the v3. No pressure to complete it, I look forward to find out what's in store!

glennmca-dev, 2024-10-01:
RE lights: i agree they may add unnecessary cost. but in the spirit of the cheapino, you could go the route of adding 3-5 optional underglow LEDs per side so only the bottom has LEDs.
I mentioned this on https://github.com/tompi/cheapino/issues/80 aswell, but if wireless, is it possible to use the empty RJ45 space for two encoders?

tompi, 2024-10-05:
@LargeCrowd Im gonna close this now, I dont think I will put in the effort to port to seed studio xiao rp2040.
I know it was very popular for a while, but its more than double the price of rp2040-zero, so does not seem like a good deal anymore.

That said, the cheapino and qmk should support it. If you want to try, make sure you mount it at the "back" of the pin holes, leaving the 2 pin holes closest to the edge empty. Should just be a matter of changing the mcu in qmk and changing the pin-definitions after that...

Closed 2024-10-05.

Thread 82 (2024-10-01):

Entire top row not working

cyberlord-coder-228, 2024-10-01:
Hi, I'm in the process of building my first cheapino, and I've noticed that entire top row and outer most thumb key on the left side of the board don't register.

I haven't touched right side yet. Only soldered the diodes and MCU in; and flushed the MCU. (Haven't even clipped diodes' legs off, as you can see in the picture))

Shortening keys in the bottom & middle rows and 2 of the 3 thumb keys  give correct key presses, but top row does not register. I've tried shortening some pin pairs on the MCU directly, and I managed to get q, w, and e.

In the troubleshooting section it is mentioned that entire row not working is probably due to bad connections on the MCU or rj-45. Since I only use one part of the board, I dont think it's rj-45 related. Didn't notice any shorts in it's place either.
I've rechecked and redone all the MCU pins (and socket pins) several times, but the issue persisits. Granted, the soldering job is very sloppy, as it is my first soldering project, but I couldn't detect any shorts or any other obvious issues with it.

All diodes are also directed "line to the square".

I didn't manage to get the veil website working, and just tested the keyboard by entering some text, if that's relevant.

So, what direction should I take to troubleshoot it further?

// Those are the best quality pics that my phone can make //
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

Btw, thanks for awesome project :3

tompi, 2024-10-01:
The Lone thumb key not working is probably a defective diode. Check with a multimeter?(or just replace it)

For the row: i suggest you test with the vial fw and yes the matrix tester there.

Can you trigger the row by shorting 2 and 2 of the bridge pads(just 2 of the lowest pads, dont bridge them)

cyberlord-coder-228, 2024-10-01:
Thank you for such quick reply :3
And thank you for all the advice

As for thumb diode, I don't have tools right now, so I'll check more thoroughly tommorow. But I noticed that shortening one of the closer circles + cirle part of the diode gives some output. Not on this key, though.
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

I'm not sure what did you mean about vial. Should I install a native app and fiddle with that a bit?
There's matrix tester's result
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

And I'm completely not sure what did you mean about shorting 2 and 2 of the pads.
I tried poking at pins and connections until I got some output) Two big square points, where the hotswaps are to be soldered to, give output. So do diagonal circles (that's how I tested them),  And so do two bottom circles, or two top circles.
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

If you meant parts that must be bridged on the right part of the board, then no, no combination that I've tried seem to give any kind of output. I did, however, got a few keys by shortening the rj-45 pins.

I played a bit with shortening pins on the MCU and (apart from pretty sparkes on pins... whait, GND and 5U?... damn) , I think I triggered reset, cause all of the keys stopped working.
I reflushed it, and 1) I noticed that my system did not automatically detected the MCU as a flash drive, as it did the first time when I connected it (the first time I dismissed it as some type of Linux magic, but now I think that something was shortened somewhere, and I fixed it when I resoldered MCU pins; which is good, probably).
And 2) some more buttons don't work now.
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

It's... bizzare. But I think reinforces that something is terribly wrong with the MCU

tompi, 2024-10-02:
Okay, sparks are not a good sign :(

You should only short 2 and 2 data pins on the mcu, never ground or power...

But is sounds like the mcu is damaged...
Good thing you socketed the mcu.

I would take out the mcu and try shorting 2 and 2 of rows: gp27-gp29 and gp8, and columns:  gp14,gp15,gp26

If you are not able to completely fill the vial test matrix doing this your mcu is not working...

cyberlord-coder-228, 2024-10-02:
Ohhhh, thats what you meant by 2 and 2...

I did not take out the MCU (I'm intimidated by desoldering it, I barely figured how to solder that beast in), just tried that test as is, by poking (diode legs') pin pairs {27-29} and {14-26}. Everything works :|
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

But on the actual keys' pins everything as it was after evertyhing got worse)
// like that
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

Another interesting observation is that i cannot trigger the pins by touching solder "volcanoes", only diode legs. Not sure if thats intended behavior or not.

Oh and not sure if I overstated the sparks, that was _just_ arcs, not New Year type performance

tompi, 2024-10-02:
Ok. Thats a good sign that you can trigger them. The mcu should be fine then.

You probably have some bad soldering, or maybe the legs that go into the socket Are bent/not long enough? You did socket the mcu it seems, so it should pull right out.

Anyway, can you trigger the keys from the underside of the board as well? If not its the soldering of the socket or the socket pins thats the problem.

Try reflowing on both sides. Use plenty of flux and correct temp, and do not spend too much time...

Another possibility is that you burnt off or scratched off one column trace and one row trace...

tompi, 2024-10-13:
Hey, just made a tool for debugging these cases, check it out if you havent given up:

https://tompi.github.io/cheapino/doc/troubleshooting/routing.html

Should be easy to narrow down which joints to check.

Closed 2024-11-10.

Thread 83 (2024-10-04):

Two columns not working (also schematics)

StarNamer, 2024-10-04:
Issue #79 partially answers my question (use KiCad for schematics), but I thought I'd ask anyway.

This is the first keyboard I've tried building and I've so far soldered the left side only. Testing with both the Vial matrix tester and simply to VSCode shows that the ring and middle finger columns are both dead.

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

The troubleshooting guide suggests checking the MCU connections, but this would be helped if there was a diagram showing the board schematic or a list  simply that simply gave the MCU pin assignments  - pin X to row A, pin Y to column B, etc. It would also help with identifying which diode connected to which key as I also had an initial failure on the middle key of the pinky column which was due to a failed diode.

I socketed the MCU so, for each pin, there a 2 joints to test - board to socket and MCU to pin - as well as checking there isn't an issue when it's inserted. I've got a second MCU which I could wire up if connection tests don't show the issue. I'm assuming it's not multiple diode failures since I've checked they all seem OK when tested across the diode and I doubt I'd have that many failed joints, but that's on my list as the next step.

Meanwhile, I've installed KiCad and will look for a tutorial... :)

StarNamer, 2024-10-04:
I been reading #82 several times, but I still don't understand the phrase "shorting 2 and 2" as in:

> try shorting 2 and 2 of rows: gp27-gp29 and gp8, and columns: gp14,gp15,gp26

I assume this means pins 27, 28, 29 & 8 handle rows and 14, 15 & 26  handle columns, but that's only 12 intersections. Does "shorting 2 and 2" mean "shorting 2 row pins together and 2 column pins  together" or something else?

StarNamer, 2024-10-04:
OK, it works fine after wiring up an replacement MCU. Hopefully it's just the pins and the Rp2040 is actually fine.

Closed 2024-10-04.

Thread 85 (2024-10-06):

Two Rows On My Cheapino V2 Just Dont Work

skie3e, 2024-10-06:
the right half works perfectly but the two middle left rows on my left side dont work at all!

i've re-heated all hot-swap switches and diodes multiple times

would it you know which diode i could switch out to try and fix this?

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
(i didnt plug in the right half but it works)

im using through hole diodes

i took the best photos i could, sorry they're so bad ;-;

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

ignore that some of my hot swap switches are melted, soldering is hard :P

thanks in advance! i love this project!!!!

tompi, 2024-10-06:
Hey, Im working on a visual debugging tool for this, ill give you a sneek peak :)

You should reflow the pin that I drew an arrow at, both columns go into that pin, so that has to be the culprit.
Also, try to use correct temp, flux, and time when soldering.

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

skie3e, 2024-10-06:
wow did something weird happen, when i redid that i lost 4 keys on the right hand,, top row, outside moving in
also, now the left-most column triggers the middle column and the thumb cluster triggers the middle left column
not sure but i cant see any brigded connections, im so confused :P

i currently ave no keyboard because my wire broke so im using on-screen keyboard 😭

tompi, 2024-10-07:
Im afraid this very likely comes down to the soldering.
Take a look at this illustration, and maybe check out some youtube guides:
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

The image is from this guide:
https://www.circuitspecialists.com/blog/how-to-soldering-correctly-soldering-101/

tompi, 2024-10-13:
Hey, just made a tool for this, check it out to debug:
https://tompi.github.io/cheapino/doc/troubleshooting/routing.html

Closed 2024-11-10.

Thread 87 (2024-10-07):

Single key also fires adjacent key

StarNamer, 2024-10-07:
I thought everything was OK and assembled the case then found that the M key also fires the N key. The N key on its own only fires itself. All other keys are fine. I'm assuming the means there's a short somewhere; does this information indicate where it's likely to be?

Fortunately, I made the switches swappable, but it means taking the case apart...

To add to your gallery...
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
As it's my first keyboard, I took the keycaps off an old PU-87 I bought as non-functional on eBay. I chose to print the case in orange to pick up the keycap legend colour,

StarNamer, 2024-10-07:
Fortunately trivial. A poorly trimmed diode leg was pushed against the switch mount when the bottom of the case was put on!

tompi, 2024-10-07:
The best kind of issue is the one solved when I discover it ;)

Thanks for the image, looks really good!

P.S. Switching the color of the diode to yellow will probably be cool! (look into qmk keys controlling led, you can control color, brightness and intensity and enable some effects if you like also)

Closed 2024-10-07.

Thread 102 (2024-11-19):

Guide for installing Xiao BLE and the on/off switch on cheapinov2

relmoo1220, 2024-11-19:
Hi Thomas,

Thank you so much for the CheapinoV2. I’ve been really enjoying typing on it!

I’ve read through some of the discussions about the wireless version and understand that it’s not fully ready yet. When it becomes available, could you please create a guide detailing which specific Xiao BLE to purchase, how to swap it out, and where to install the on/off switch on the left/right side of the PCB? I’m looking forward to building a set of wireless CheapinoV2.

Thanks again for all your hard work and support!

tompi, 2024-11-19:
Hey, as of now, it works fine, but it doesnt go into deep sleep, so battery does not last many days if you dont turn it off...
Im not sure im able to solve this without changes to the pcb...(a rev 3...)

If you want to try this, it really isnt very complicated, you can just mount the xiao at the "bottom", and flip it on the right side.

ZMK support is here: https://github.com/tompi/cheapinov2-zmk-config

But like I said, this isnt very polished...
(btw, I also feel like zmk is somewhat lacking... Eg the new feature zmk studio is nowhere near vial...)

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

relmoo1220, 2024-11-21:
Thank you for the photo reference! I don't think I would mind charging it once every few days, so I'll just get the Xiao BLE and battery to try it out. May I know what battery you are using in the photo? Seems a little big in size so maybe I'll get something similar but less battery capacity and smaller in size.

tompi, 2024-11-21:
The battery is 3.7V 200mAh.

Its way too big. Im waiting for a pair of 1cm x 2cm x 4mm, also 200mAh, which I hope will fit under the mcus.

Batteries from ali seems to have a longer shipping time...

If you want to go cheap you can probably also go for a pair of nice nano clones(1/3 of the price of the seeduino...), but I have not made fw for a true split for this yet(i have it on the top set in the pic with zmk and non-split..). The downside of this is its a bit longer, so it sticks out a bit in front...

Gotta say the wireless thing is growing on me, been using it for work for a week, and no problems...

relmoo1220, 2024-11-22:
Thanks for the clarification on the battery sizing!

Do you have the zmk config running the miryoku layout?

Also, when connecting to MacOS do you select the ANSI layout?

tompi, 2024-11-22:
Im running my own keymap(resembles colemak dh miryoku, but not quite the same...)...

For miryoku you would need to look into building it out-of-tree, not quite sure how that works, but probably not very difficult.

Im using us-international on mac, so I can get norwegian characters with alt-gr combinations.

relmoo1220, 2024-11-22:
For the Xiao BLE is it able to just load the miryoku zmk config they provided?

tompi, 2024-11-22:
I dont know how it works... but you need to combine 3 repos somehow: zmk, cheapino-zmk and zmk-miryoku.

HOW to do that, I dunno, sorry... If you figure it out, let me know, and I will post it to my pages!
Probably the guys at zmk discord can give a nice recipe!

relmoo1220, 2024-11-22:
Ahhh i see thanks a lot!

I guess just one last thing would be do you have a photo reference of the different layers for your zmk config?

That would be much easier to visualize the key mappings.

Thanks for the fast replies!

tompi, 2024-11-22:
Sure, the actual zmk keymap is here:
https://github.com/tompi/cheapinov2-zmk-config/blob/main/boards/shields/cheapinov2/cheapinov2.keymap

To get a visual rep, download this file:
https://github.com/tompi/qmk_firmware/blob/cheapinov2/keyboards/cheapino/keymaps/tompi/keymap.json

And upload it here:
https://config.qmk.fm/

The zmk keymap is missing some special qmk codes, like led control and mouse movement(which is missing from zmk still...), but the important stuff should be there

relmoo1220, 2024-11-22:
Thank you very much for your help, I will proceed to mark this as closed :)

tompi, 2024-11-22:
Send me a note if you build the wireless version, im very curious about your experience!

I can probably help you if you get stuck trying to build miryoku.

P.S. Battery drains slower than I feared, seems like less than 5% per day if I remember to turn it off at end of day.

tompi, 2024-11-22:
And if you take some pictures or have ideas about mounting, I will be very happy to incorporate them into a guide!

tompi, 2024-11-22:
Yep. That's the one. 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

Closed 2024-11-22.

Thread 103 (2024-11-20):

Nothing detected

uivmc, 2024-11-20:
I finished building cheapino v2, flashed the uf2 (the one for v2), got the LED to turn on, and detected it on vial.rock. But the matrix test gave an error and none of the keys worked.
Then I noticed I needed to solder the legs to the MCU (I used socketed MCU).
After I did that the MCU LED is off, vial.rock can not detect it anymore, and still none of the keys work.
I've reflashed the uf2 (the MCU can still show up as a USB drive. I notice this time the uf2 file disappears after I drag it on, originally it would stay there), and reset my computer. I've used a multimeter to check the legs at the top of the MCU are electrically connected to the solder at the bottom of the PCB. I've shorted two pins of a switch and still no keypress. Nothing has worked.
What should I do?

tompi, 2024-11-20:
Hi, could you post a picture of the mcu? (maybe some solder bridges?)

If you test with mcu out of socket, does the led light up?

uivmc, 2024-11-20:
Hi.
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
Even out of socket no light.

uivmc, 2024-11-22:
I was wondering if I damaged the MCU.
But I was able to do the blinking led demo via Arduino IDE from this video
https://www.youtube.com/watch?v=eTf5z5lcWhc
so I know it is still functioning.

azzamsa, 2024-11-23:
I have a similar issue (nothing detected), and it was a wrong firmware #104. I am using v1 for v2 board.

uivmc, 2024-11-23:
I had made sure to download v2 uf2. And my PCB says v2 so they match.
In your issue you mention a cheapino and cheapinov2 branch. But neither exist to me. I only see a master and fix/case-tolerances branch. Do you mean tags?
I tried the v1 uf2 just in case and interestingly vial can detect and connect with that. The keys give the wrong outputs though, which matches what the troubleshooting guide predicts for incorrect version.
I also noticed that the v2 uf2 file was updated 4 days ago, which is 1 day before I downloaded it...
@tompi  Can you provide the old version of the v2 uf2 file? I want to check if that works.

tompi, 2024-11-23:
Hey, you are correct, I changed the default brightness of the LED(turned it way down...), and I probably should up the release version, but until now I kind of feel like the gerber is the versioned artifact... but i will take care. and not change releases in the future.

The attached uf2 is from july, please let me know if it works!

Could you maybe try with some other usb cables?
I know there are issues with "too good" cables and the cheapino, so if you have a usb2 cable, it would be interesting to hear if that works better.

[cheapino_vial.uf2.zip](https://github.com/user-attachments/files/17879288/cheapino_vial.uf2.zip)

tompi, 2024-12-29:
Hey, sorry I forgot to reply to this one... Did you figure out what was wrong?

If not, is vial recognizing your out of socket rp2040 if you flash it with any of these uf2 rp2040 files? https://okin.gitlab.io/vial-qmk-firmwares/

uivmc, 2025-01-02:
I did not figure out what was wrong.
Vial detects the out of socket (and also in socket) rp2040 when I flash asmodus_plaquead_rgb_vial.uf2 onto it.

tompi, 2025-01-02:
Which host is Are you using? And did you try on another machine or with a docking station?

uivmc, 2025-01-02:
I used the online vial. https://vial.rocks/
In the past I have tried: on another machine, with usb-hub, and without usb-hub

uivmc, 2025-04-14:
Finally got around to ordering some more MCUs and soldering them. That fixed the problem.
Strange that the old MCU can still run the LED uf2s with no problem.
Unfortunately, I encountered problems when disconnect and connect the magnetic USB. Power surge warnings, or keypresses not working. It would sporadically work again at times. Until eventually one time I disconnect and my computer went black or sleep mode or something briefly, the MCU lights went out, and now I can not even put it into dfu mode anymore.
Luckily I have one more spare MCU. I'll stick with a non-magnetic USB and see if other problems arise.
This issue was resolved at least, old MCU having problems, so I'll close this.
A suggestion. Originally when I clicked the MCU aliexpress link it only let me order 1, due to the newcomer discount or something. Which is why I originally didn't order spares. After you create an account and sign in though, you can increase the quantity although without the discount. Could mention this in the ordering guide when you are recommending people to order 2 MCUs, so they know how to.

Closed 2025-04-14.

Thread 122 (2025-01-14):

Help Needed: Issues with Key Detection on Cheapino Build

sennecools, 2025-01-14:
Hi everyone,

I recently built my first Cheapino V2 keyboard, and I’m running into some issues. Some keys (highlighted in red) work perfectly, while others (highlighted in blue) only work sometimes or don’t register at all. This is my first time soldering or working with PCBs, so I’m not sure if the problem is related to my soldering or something else.

I noticed that I installed the diodes on different sides of the PCB: on one half, they’re on the top, and on the other half, they’re on the bottom. However, the orientation is correct since the lines on the diodes match the square markings on the PCB.

Additionally, I used the legs of the diodes to connect the MCU, but the connection feels very loose, and I have to press on the MCU for it to connect properly to the board.

Do the diodes being on different sides matter as long as they’re oriented correctly? Could weak solder joints be causing the inconsistent key detection? And how can I make the MCU connection more secure?

Any advice would be appreciated. Thanks in advance!
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

sennecools, 2025-01-14:
It show up in vial and I have tried different cable, windows and mac.

tompi, 2025-01-14:
Hi! I see you have the slightly more expensive socket, which is mesket for thicker legs. I think the pin headers that comes with the MCU Are suitable(you can loosen them from the plastic).

I specified this in the ordering guide, but should probably mention it in the build guide as well.

If you want to fix it as is, you can figure out which pins to resolder/reflow using this tool: https://tompi.github.io/cheapino/doc/troubleshooting/routing.html

sennecools, 2025-01-15:
Alright I tried using header pins that came with the mcu on my second mcu but now it wont even power. There is no light or anything tested it before and it was working and detected in vial now it sometimes gives the windows sound but not showing up in vial or as a drive. I have tried multiple cables. Did I maybe overheat the board while soledring or something?

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

tompi, 2025-01-15:
Does it work out of socket? Also worth trying without the magnetic connector...

tompi, 2025-01-15:
But yeah, if it does not show up as thumb drive when you reset it out of socket then something is very wrong :(

tompi, 2025-01-15:
Just check carefully for shorts. If there Are not any shorts, then my guess its unfixable :(

sennecools, 2025-01-16:
Yeah fried the second mcu as well I think it keeps disconnecting and flashing itself. Guess I need to order some new parts and work on my soldering skills, btw the link for the diodes seems to not be available anymore.

tompi, 2025-01-16:
Just be careful with your magnetic usb connector. That might be the culprit...

sennecools, 2025-01-17:
Ordered some new mcu since I tried everything with the ones I had. Any tips for soldering the mcu I used 400 celcius but maybe that's too hot, also do you wait inbetween each pin for the board to cool down a bit?

tompi, 2025-01-17:
I had to check, and mine is set to 380c. I think 400 should be fine.

Im guessing the important thing is how long you spend at each pin. Dont use more than a fee seconds.

But Im no Expert at all(the electrical engineer at work keep remarking i need to step up my soldering game...)

sennecools, 2025-01-17:
I'll try to be extra carefull next time then, thank you for all the help :)

sennecools, 2025-01-22:
I have no idea what I'm doing wrong tried with a new board and I always end up with 1 of the pins connecting when I test with a multimeter but there is nothing I can see on the board.

tompi, 2025-01-22:
What do you mean one of the pins connected?

sennecools, 2025-01-23:
When I put the multimeter on two pins next to each other it beeps so they are connected somewhere. But even when I look closely at the board I cant see any solder inbetween them. and I watched out this time only a couple second per pin. waited for the board to cool off a bit inbetween pins.

Thearne4, 2025-03-17:
the pins connect inside of the MCU (with some measurable resistance between them). try detecting again without the MCU installed 😉

tompi, 2025-08-22:
Closing after no activity. Feel free to re-open if this is still an issue...

Closed 2025-08-22.

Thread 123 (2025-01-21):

Help to source simplest plates, please?

dansteeves68, 2025-01-21:
After using Ergodox for a few years and ignoring all the extra keys, I ordered everything to make my first Cheapino. I would like to use a plate (or inexpensive case?), but am at a loss for sourcing it as JLPCB says the .stl files are too small for 3d printing and I don't see how to ask for them laser cut out of PCB material. Can someone provide a bit more detail? Thanks.

tompi, 2025-01-21:
I think you can print them at jlc? Hmm, I just checked and FDM is not possible, but resin and nylon both should work.
(need to be careful with the resin when melting in the nuts...)

But really, if you know somebody, or have access to a makerlab, like at a library, it doesnt take long, and does not use much filament...

dansteeves68, 2025-04-21:
I did finally figure out how to order them 3d printed from JLC.

Closed 2025-04-21.

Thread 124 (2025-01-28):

Third row and encoder not working on the right side after desoldering

GabrielCanaple, 2025-01-28:
Hello!

# The problem

First, thank you very much for your project, it's awesome ! I already got one cheapino working well with soldered switches, and it's a pleasure to use it.

However, for my second build, I got a problem. I soldered the encoder upside down (too eager to finish soldering and start using it !).
One thing to note though is that all the keys of the right side (and the encoder) were working fine, even with the encoder upside down.

So, I had to desolder it (which broke the encoder) to put a new one instead. And now, the third row and the encoder are not working.

#  What I tried

- I used my other (working) cheapino to make sure it's not caused by the left side. It is indeed not the left side.
- I re-soldered the diodes for the whole row, but it didn't solve the problem (see photos to make sure my solders are not too crappy)
- Re-soldered the corresponding pins on the RJ45 port. No success.

# My theories

1) When de-soldering, I burnt the PCB and the underlying copper wires. See photos, there is a small scratch on the other side of the encoder, but I am not sure it's the culprit (that's why I'm posting).
2) I did a bad solder somewhere and am not able to re-solder it properly.

Do you have any idea about what's wrong here ? Thank you !

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

tompi, 2025-01-28:
Hey. If you have a multimeter you can probably track this down.

So you attached your working right side to the new left and everything worked?

Check out the interactive schematic: https://tompi.github.io/cheapino/doc/troubleshooting/routing.html

And measure continuity along the non working traces

GabrielCanaple, 2025-01-29:
Thank you for your answer.
Yes, I did all the combinations (old left with new right, old right with new left) to make sure that the problem was with the new right.

I do not have a multimeter at the moment, and will need a few weeks to get my hands on mine (not available atm). I will update when I do.

Although, I do think that it is weird because this row and the encoder of the new right were working before desoldering the encoder. Could this be due to overheating the PCB or something like that ?

tompi, 2025-01-29:
Yeah, but third row is strange. Im more inclined to think something happened with the rj45 socket.

Or a scratch in the pcb, severing third and fourth(encoder) row.

GabrielCanaple, 2025-03-09:
Hello again,
I finally managed to get my multimeter, and tested the continuity on the right side.
Your intuition was right, it was indeed the RJ45 socket (no continuity between the socket and the board). I replaced it, and it works perfect !
Thank you for your help.

Closed 2025-03-09.

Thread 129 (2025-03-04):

Slave half just started acting up.

TheTechRun, 2025-03-04:
As the title states my slave half just randomly started acting up.

Issues:
The middle row on the right side (slave) outputs random characters. In qwerty  "H" outputs "ujm", "J" outputs "ujm". "K' outputs nothing, "L" outputs "ol.", and ";" outputs nothing.

What I have tried:
Using a different ethernet cord.
Using a different usb-C cable.
Connecting to a different computer.
Reflashing the firmware.

Any ideas?

tompi, 2025-03-04:
Hey. If you Check the trouble shooting guide, there is an interactive schematics, which should help you track down points of interest depending on keys presses.

I would use this and then Check the indicated paths.

My guess is you have a wire stuck somewhere that is shorting stuff...

TheTechRun, 2025-03-04:
I bought this prebuilt and would have no idea how to trace lines, desolder, etc. I was hoping it would be something software wise or  maybe a simple trick to fix it. Long shot in the dark, I know. Thanks anyways.

tompi, 2025-03-04:
Like i said. I think its something simple like a piece of metal stuck in the case or between plates. Open it up and have a look

tompi, 2025-04-20:
Sorry, not really sure what the problem could be, would probably contact the builder...

Alternatively, if the MCU is socketed, try replacing it(its very cheap, like 4$ i think...)

tompi, 2025-04-22:
One thing just occured to me, when this happened, did you use a magnetic cable?
(if so, did you also get messages about excessive power draw from usb device?)

Closed 2025-08-22.

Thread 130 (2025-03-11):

MCU failure (looking for insights)

Thearne4, 2025-03-11:
First off, thank you so much for creating this project! Built it last Wednesday evening and haven't touched another keyboard since.

Yesterday evening however I had a strange thing happen. Suddenly 3 seemingly unrelated keys stopped working on the right hand / slave side.

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

After checking the schematic, I concluded the MCU must be the culprit. And indeed after soldering up a new RP2040 and swapping it in, everything works again.

However, when plugging in to my desk this morning I got an error stating "The USB port is drawing too much power". After plugging in to another USB port, everything works fine again...

If anyone has an idea of what's going on, I'd be happy to hear your opinion.

(also, i build 2 and the 2nd one is on loan to a colleague, he hasn't experienced any issues as of yet)

tompi, 2025-03-11:
Actually, they are related... They all belong to the same row, and on each row, two and two columns are connected to the same row, only with diode direction reversed on one.

So there definitely is a pattern here, im guessing the mcu input or output io for these is fried.

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

Check this to see details on what is connected to what:
https://tompi.github.io/cheapino/doc/troubleshooting/routing.html#

This thing about too much power MIGHT indicate a short somewhere(probably on the highlighted traces above), which caused previous mcu to fail and might create more trouble... If you have a multimeter, check for gnd shorts on the highlights.

This guy had the same i think, but not sure if that was gnd short on board or on mcu...
https://github.com/tompi/cheapino/issues/53

tompi, 2025-03-11:
to verify, try holding some of these keys for longer time and see if you get the too much power message(but might be harmful....)

Thearne4, 2025-03-11:
well, since this morning I haven't seen the powerdraw message anymore. I was thinking that that might be related to the magnetic USB cable, so since this morning I've made it a point to first connect the magnetic side and afterwards plug in the USB-A side and not vice-versa.

I tried holding all 3 keys for a while and luckily everything still works. Didn't feel the MCU get warm or anything either.

Since my colleague has asked me to buy the cheapino he was using, I'll order parts for a new second one so I can just leave this one home. If I find the time tomorrow, I'll go looking for any soldering that might be close to bridging...

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

tompi, 2025-03-12:
Great that it works, and yeah, magnetic cables can have issues, I guess there is a reason you cant really buy them in the civilized world... What has happened to me at least a few times is that the magnet picks up a small diode leg which gets in between the connectors... (nothing bad happened yet...)

Nice looking build!

Thearne4, 2025-03-14:
Went to the store, got back home to non-functioning keys

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

these 3 this time

Thearne4, 2025-03-15:
so, I measured all the pins and found no ground short anywhere. (also, the ground isn't passed trough to the slave side; is this by design?)

tompi, 2025-03-15:
Yes, i dont use gnd for anything. Could be your magnetic cable is the culprit and frying your mcu?

If you replace the rp2040 again, i would avoid that cable...

Thearne4, 2025-03-16:
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
(above) the old one that i now replaced does seem to have the rings closer together than the one i now put in (below)
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

Thearne4, 2025-03-16:
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
also, the dimples in the rings don't exactly fill me with confidence...
(removed below, installed above)

tompi, 2025-04-20:
Thank you!  Added links to this issue in troubleshooting guide and ordering guide!

Closed 2025-04-20.

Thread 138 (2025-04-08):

started spamming random keys after adding rj45 sockets

szulf, 2025-04-08:
So i built the first half and it was working fine, but after soldering all the diodes, the rj45 sockets and the bridging, and connecting the two halves to my pc the keyboard started randomly spamming keys. Now even when i dont have the second half connected the problem is present.
I didnt solder the switches on the second half, because i wanted to see if i did the bridging, rj45 sockets and diodes correctly.
Tried the vial firmware as well as qmk.
Now not every key is being registered correctly. some just dont respond to clicking on the switches.
Im on the v2 version, but with soldered switches instead of hotswaps, and without the encoder.
Really have no clue what could've gone wrong, and what i can do to fix it. Will provide any additional info that is needed.

tompi, 2025-04-08:
Just to Check: you only soldered the bridging pads on the right side? Post some high res pics of all sides.

And maybe try a different cable?

Also Check the trouble shooting guide:)

szulf, 2025-04-08:
right side:
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

and the left:
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

tompi, 2025-04-08:
Okay, i missed the part about problem being present Even with right half disconnected...

Did you socket the mcu? If so, is it still spamming if you take it out of the socket and Connect to your pc?

And which keys is it spamming? Not all of them?

szulf, 2025-04-08:
Its mostly spamming teqzbc, most importantly non of the characters of the right side.

And honestly this might sound stupid, but i think i soldered the mcu to the sockets, and then to the pcb, so i cannot easily remove it. Its my first time doing this kind of thing, and i must've not understood the buildguide correctly. I might try desoldering it, but i honestly doubt that i will have any success with that.

tompi, 2025-04-08:
Yeah, dont try to desolder...

First Check very carefully if a metal piece is stuck somewhere creating intermittent shorts.

If not, you might Get a multimeter and Check for shorts.

Not that it helps you, but this is why the build guide suggests sockets, if anything goes wrong with the mcu it is much easier to replace it...

szulf, 2025-04-08:
Just one more question, how do i socket it? Because i had the sockets this time, and i put in the diode legs, but after soldering, the sockets and the controller just became one thing. Do i pull the controller out of the sockets when soldering on the breadboard? Do i put just a little solder in there? How do i do that?

tompi, 2025-04-08:
Ah, but then you should be able to pry the mcu gently out of the sockets!

szulf, 2025-04-08:
Theres no way, im pulling it with all my force and it just wont budge. I mustve soldered them together somehow.
Can you give any pointers on how not to do that next time?

Closed 2025-04-11.

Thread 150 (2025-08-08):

Stuck keys, entire column, qwerty keys RFV

schuay, 2025-08-08:
Hi there,

I've gone through the other bug reports but did not find one with similar symptoms. For reference, these also mention stuck keys:

https://github.com/tompi/cheapino/issues/40
https://github.com/tompi/cheapino/issues/138

After my first build attempt, I started from scratch with decent tools. Afaict, the soldering this time went well - no repairs needed, no excessive heating times, no obvious shorts or other problems I can see.

However, a single column of keys is stuck. These will trigger like crazy, mostly all at once, but sometimes one at a time as well. Sample output (colemakdh layout, thus different characters than the qwerty ones below): "dddptddddddptdptddptdptdptdptdddddddddddptdddddddddddd".

* The fourth column from the left, on the left keyboard side. On qwerty layout: keys RFV.
* Reproducible without switches plugged in, and without the right side connected.
* Does NOT trigger when the MCU is disconnected from the board.
* DOES trigger with a different, second MCU as well.
* Sometimes, upon bootup, symptoms are gone for a minute, but reappear.

Again, on visual inspection I don't see obvious soldering problems. What's interesting is that this key column shares an underlying circuit column with the key column to the right (keys TGB), but those behave normally.

I'd appreciate any debugging help.

Edit: I wonder if this is heat-related. The first 1-2 minutes after turning on a cold MCU are fine. I had just the left side plugged in, without switches attached, and began slowly adding switches one by one. After a minute, the key spam started, and continued despite removing all switches again and power cycling the MCU a few times.

And actually, the fifth column from the left also seems to be acting up. Plugging in only a single switch each time, pressing B emits BFQ, G emits GSA, V emits VCZ (all colemakdh). I.e., columns 5,3,1. What the..

schuay, 2025-08-08:
> Hi! Sounds strange. If you modded the firmware, maybe try with the one linked on github page to check that the problem is still there?

Yeah I did that, using your cheapino_vial.uf2.

>
> Also, i made a visual debug page to help with these cases, did uou check it out?(should be linked from troubleshooting)

Yes, but I don't know how it would help with the symptoms I see.

It gets stranger still: I plugged in the MCU into another left half which I'd previously assembled. That one now also exhibits stuck keys and single presses emitting multiple chars. But completely different ones..

I wonder if my components are faulty (all sourced from AliExpress); or if I managed to fry both MCUs.

schuay, 2025-08-08:
> This happens on left part also?

Yes, *only* on the left.

> Did you mount in a case? If so, metal part may be lodged in case?
>
> Try without case, and only with left part.

No case.

> Check that you did not solder the bridges on the left part.

Check.

> Another thing which might be the cause is if some of the diodes are mounted in the wrong direction...

I checked multiple times already.

I'm about to start assembling my final PCB into another left-side try, checking after each step for problems. Although I have another batch of diodes from a different manufacturer incoming in a few weeks. I wonder if I should wait for those, just in case my current batch is bad..

schuay, 2025-08-08:
Well, what can I say - the third attempt at a left hand side seems to be working and I finally have one full working cheapino :)

I'm not sure what the problem was with with attempt number two; I was just as careful there, and I still don't see what could be wrong with it. The symptoms sure were strange.

I guess the MCU can be ruled out, likewise the switches, the case, and the cables. I'd love to find out what the problem was to avoid future mistakes, so if you happen to find anything in the photos please do let me know.

Thank you very much for the your help, and for your work on this.

tompi, 2025-08-08:
Cant see any obvious things... does the old mcu fail on the new pcb?

schuay, 2025-08-08:
> Cant see any obvious things... does the old mcu fail on the new pcb?

Nope, it's plugged into it right now.

tompi, 2025-08-09:
Cool. Ill add that to the troubleshooting guide!

Closed 2025-08-08.

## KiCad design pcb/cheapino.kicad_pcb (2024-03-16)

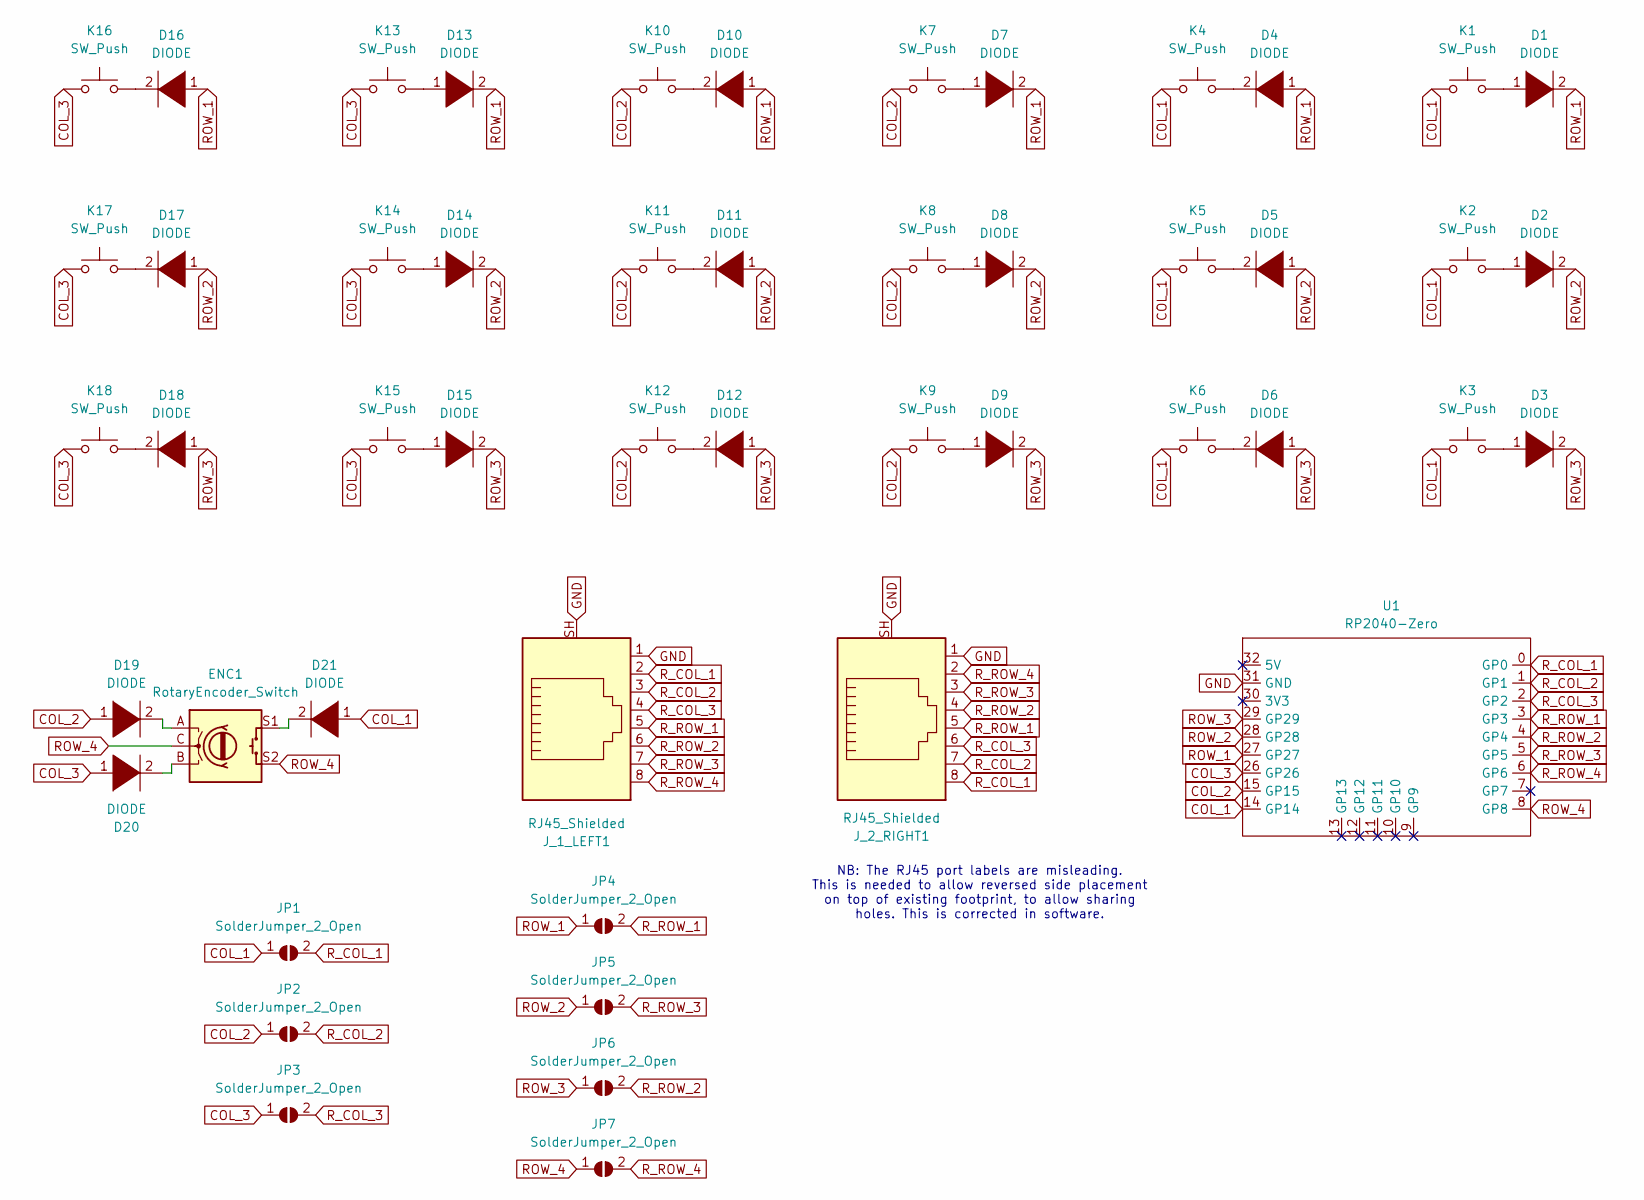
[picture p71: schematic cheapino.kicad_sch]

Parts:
D1, D2, D3, D4, D5, D6, D7, D8, D9, D10, D11, D12, D13, D14, D15, D17, D18, D19, D20, D21: DIODE; Diode-dual
D16: DIODE; D_SOD123_axial
ENC1: RotaryEncoder_Switch; RotaryEncoder_Alps_EC11E-Switch_Vertical_H20mm
JP1, JP2, JP3, JP4, JP5, JP6, JP7: SolderJumper_2_Open; SolderJumper-2_P1.3mm_Open_TrianglePad1.0x1.5mm
J_1_LEFT1, J_2_RIGHT1: RJ45_Shielded; RJ45_Ninigi_GE
K1, K2, K3, K4, K5, K6, K7, K8, K9, K10, K11, K12, K13, K14, K15, K16, K17, K18: SW_Push; Kailh_socket_MX_optional_reversible
U1: RP2040-Zero; MCU_RP2040_Zero_34

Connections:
COL_1: D21.1 (K), JP1.1 (A), K1.1, K2.1, K3.1, K4.1, K5.1, K6.1, U1.14 (GP14)
COL_2: D19.1 (K), JP2.1 (A), K7.1, K8.1, K9.1, K10.1, K11.1, K12.1, U1.15 (GP15)
COL_3: D20.1 (K), JP3.1 (A), K13.1, K14.1, K15.1, K16.1, K17.1, K18.1, U1.26 (GP26)
GND: J_1_LEFT1.1, J_1_LEFT1.SH, J_2_RIGHT1.1, J_2_RIGHT1.SH, U1.31 (GND)
unnamed: D1.1 (K), K1.2
unnamed: D2.1 (K), K2.2
unnamed: D3.1 (K), K3.2
unnamed: D4.2 (A), K4.2
unnamed: D5.2 (A), K5.2
unnamed: D6.2 (A), K6.2
unnamed: D7.1 (K), K7.2
unnamed: D8.1 (K), K8.2
unnamed: D9.1 (K), K9.2
unnamed: D10.2 (A), K10.2
unnamed: D11.2 (A), K11.2
unnamed: D12.2 (A), K12.2
unnamed: D13.1 (K), K13.2
unnamed: D14.1 (K), K14.2
unnamed: D15.1 (K), K15.2
unnamed: D16.2 (A), K16.2
unnamed: D17.2 (A), K17.2
unnamed: D18.2 (A), K18.2
unnamed: D19.2 (A), ENC1.A
unnamed: D20.2 (A), ENC1.B
unnamed: D21.2 (A), ENC1.S1
ROW_1: D1.2 (A), D4.1 (K), D7.2 (A), D10.1 (K), D13.2 (A), D16.1 (K), JP4.1 (A), U1.27 (GP27)
ROW_2: D2.2 (A), D5.1 (K), D8.2 (A), D11.1 (K), D14.2 (A), D17.1 (K), JP5.1 (A), U1.28 (GP28)
ROW_3: D3.2 (A), D6.1 (K), D9.2 (A), D12.1 (K), D15.2 (A), D18.1 (K), JP6.1 (A), U1.29 (GP29)
ROW_4: ENC1.C, ENC1.S2, JP7.1 (A), U1.8 (GP8)
R_COL_1: JP1.2 (B), J_1_LEFT1.2, J_2_RIGHT1.8, U1.0 (GP0)
R_COL_2: JP2.2 (B), J_1_LEFT1.3, J_2_RIGHT1.7, U1.1 (GP1)
R_COL_3: JP3.2 (B), J_1_LEFT1.4, J_2_RIGHT1.6, U1.2 (GP2)
R_ROW_1: JP4.2 (B), J_1_LEFT1.5, J_2_RIGHT1.5, U1.3 (GP3)
R_ROW_2: JP6.2 (B), J_1_LEFT1.6, J_2_RIGHT1.4, U1.4 (GP4)
R_ROW_3: JP5.2 (B), J_1_LEFT1.7, J_2_RIGHT1.3, U1.5 (GP5)
R_ROW_4: JP7.2 (B), J_1_LEFT1.8, J_2_RIGHT1.2, U1.6 (GP6)

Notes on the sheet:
NB: The RJ45 port labels are misleading. This is needed to allow reversed side placement on top of existing footprint, to allow sharing holes. This is corrected in software.

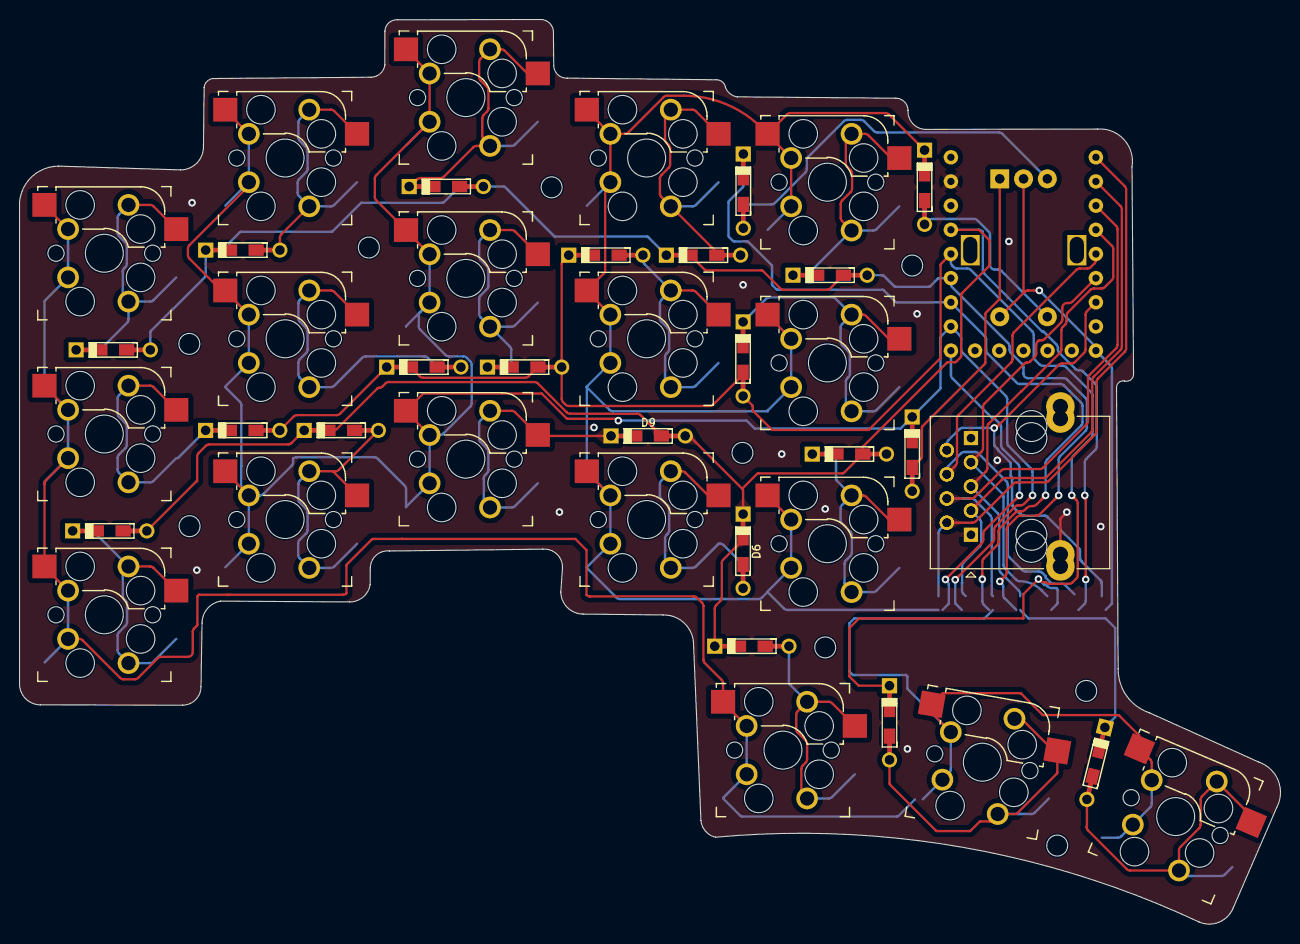
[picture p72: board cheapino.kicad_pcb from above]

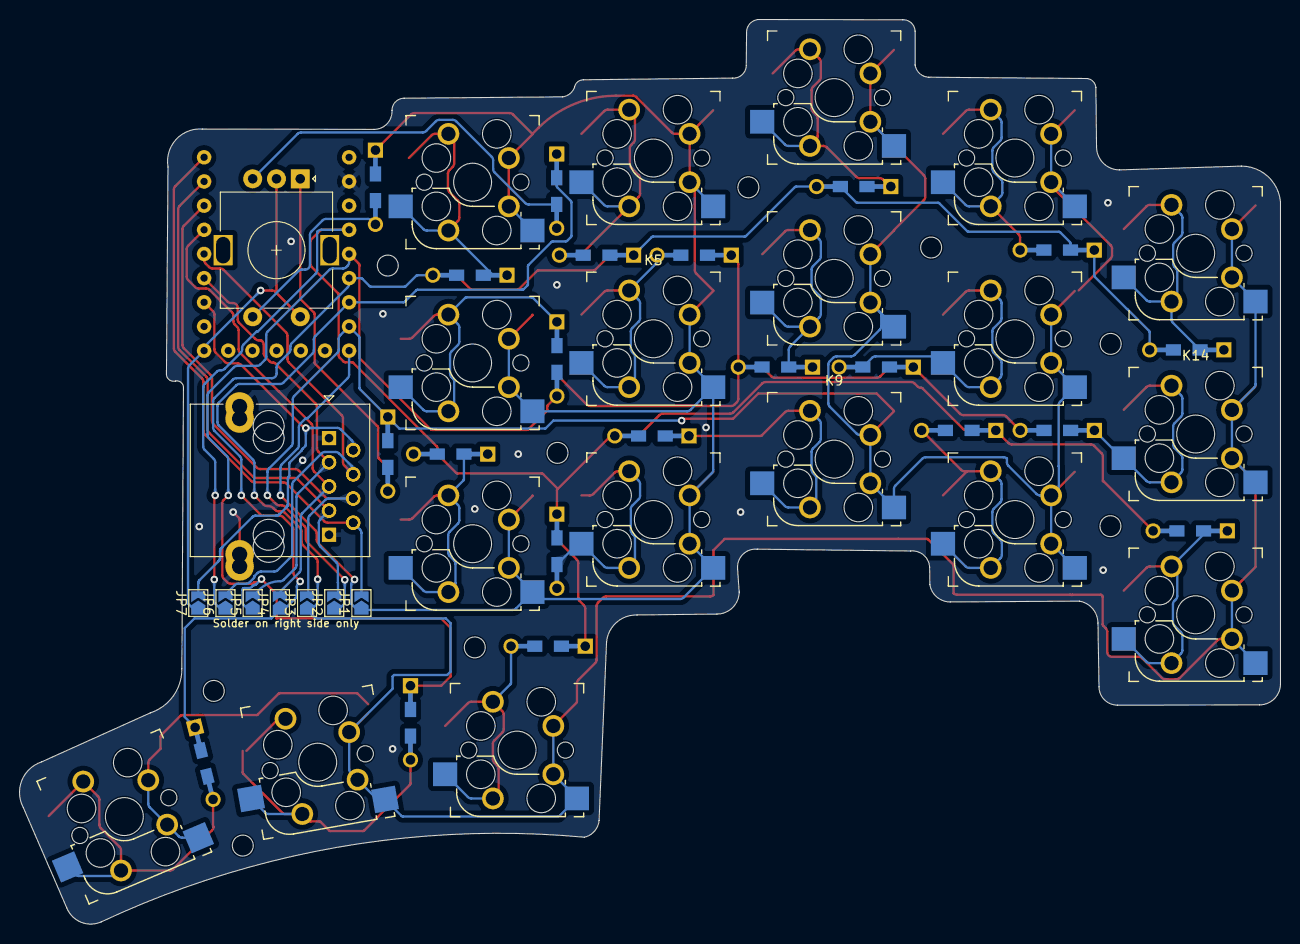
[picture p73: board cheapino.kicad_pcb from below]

Board: 2 copper layers, 132.5 x 95.1 mm, 50 parts (9 on the bottom side), 36 nets.

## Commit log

2023-01-22 passes drc
    [cheapino.kicad_pcb, cheapino.kicad_sch]
2023-01-28 Rev 1, ordered from jlcpcb
    [cheapino.kicad_pcb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]
2023-01-30 1.1: Rounded tracks and teardrops
    [cheapino.kicad_pcb, cheapino.kicad_sch]
2023-03-26 Fixed missing pads on one smb diode
    [cheapino.kicad_pcb]
2023-03-26 Readme and some images
    [cheapino-left.step, cheapino-right.step]
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2023-08-10 Added a build, and updated build guide to recommend covering up possible gnd short
2023-09-21 add plate
    [plate.stl]
2023-10-08 Hotswap support and solder jumpers
    [cheapino.kicad_pcb, cheapino.kicad_sch]
2023-11-04 V2 First draft
    [cheapino.kicad_pcb, cheapino.kicad_sch]
2023-11-15 Ordered prototype
    [cheapino.kicad_pcb]
2023-11-20 M2 Mounting holes
    [cheapino.kicad_pcb]
2023-12-16 Fix missing SMD footprint on right/back Diodo D16
    [cheapino.kicad_pcb]
2023-12-16 Fixes #10 Added some mounting holes
    Also added logo, rounded tracks and tear drops
    [cheapino.kicad_pcb]
2023-12-27 Initial draft of case: wip
    [cheapino.scad]
2023-12-28 Case: wip
    [cheapino.scad]
2024-03-01 Fix embarassing missing trace for column 2...
    [cheapino.kicad_pcb]
2024-03-13 Fix number of diodes required
2024-03-16 Added logo copper layer, removed some labels
    This commit was ordered from jlcpcb
    [cheapino.kicad_pcb, cheapino.kicad_sch]
2024-04-01 Elaborate on encoder customization
    As suggested by jinchoung
2024-04-01 Link to @MrBarbie 3D printed fork in the build guide
    Close #27
2024-04-06 Add note about v2 being released on front page.
    Also add remark about 3D printed fork on front page
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2024-04-28 Plates with standoffs and beginning of a case
    [cheapino.scad, v1_plate.stl, v2_cheapino-left.stl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]
2024-04-29 Case wip
    [cheapino.scad]
2024-05-01 Case v2 wip
    [cheapino.scad, holes.scad, plate.scad]
2024-05-01 Case, wip
    [cheapino.scad]
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2024-05-11 Image of hotswap and suggested hotswap before diodes
2024-05-11 Update v2 socket to show v2 mcu socketed
2024-05-11 Some cases and info
    [cheapino-plate-left.stl, cheapino-plate-right.stl, plate.stl]
2024-05-18 scad bottom plate wip
    [cheapino-bottom.scad, cheapino-top.scad, hotswap.scad]
2024-05-19 Right bottom prototype done
    [cheapino-bottom.scad, hotswap.scad]
2024-05-23 Removed magsafe insert and adjusted one wrongly placed column
    [cheapino-bottom-left.scad, cheapino-bottom-right.scad, cheapino-top.scad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]
2024-05-28 Printing top left
    [cheapino-bottom-left.scad, cheapino-bottom-right.scad, cheapino-bottom.scad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]
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2024-06-05 Case bug-fixes
    * Too small mounting hole inserts
    * 1mm too high top offset
    * 0.5 larger top case to avoid too tight fit
    [cheapino-top.scad, modules.scad]
2024-06-08 Top-right, finished first prototype
    Will print tuesday...
    [cheapino-top-left.scad, cheapino-top-right.scad, holes.scad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]
2024-06-09 Fix space for solder bridges
    [cheapino-top-right.scad]
2024-06-18 Version on thingiverse
    [cheapino-bottom-left.scad, cheapino-bottom-right.scad, cheapino-top-left.scad]
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2024-06-22 Moved pcb files into separate folder.
    Also added some images/links to v2 case
    [cheapino-left.step, cheapino-right.step, cheapino.kicad_pcb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]
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2024-07-07 Slightly increase the size of the RJ45 hole in the case
    Widening the RJ45 connector hole along the x-axis by 0.45mm makes it
    easier to fit the assembled board without sanding.
    [cheapino-top-left.scad, cheapino-top-right.scad]
2024-08-11 Slightly larger diode slots
    [modules.scad]
2024-08-11 Slightly larger tolerance for top case
    [cheapino-top-left.scad, cheapino-top-right.scad]
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2024-08-21 Make RJ45 case cutout slightly larger
    The fit was so tight I broke a connector on a case...
    [cheapino-top-left.scad]
2024-08-21 Make RJ45 case cutout slightly larger
    The same change as last, except for the top right now
    [cheapino-top-right.scad]
2024-08-21 Rotate top right same as left
    [cheapino-top-right.scad]
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2024-09-07 Expanding on the virtues of socketing MCU
    Also added some troubleshooting items
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2024-09-24 Expanded diode cutouts and recentered
    Also explained which openscad version to use
    [cheapino-top-right.scad, modules.scad]
2024-10-06 Added usb 3.2 cable warning(#78) on ordering guide also
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2024-10-07 Specify type of legs needed per socket also in the build guide
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2024-10-13 Added missing encoder columns in debugging tool
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2024-11-24 Fix bug in interactive schematics
2024-11-25 refactor: remove trailing whitespace
    [cheapino-bottom-left.scad, cheapino-bottom-right.scad, cheapino.scad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]
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2024-12-03 feat(case): MCU and RJ45 cover
    [cheapino-bottom-left.scad, cheapino-bottom-right.scad, cheapino-top-left-with-cover.scad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]
2024-12-22 Increase hotswap cutout to support Gateron sockets
    Was customized to Kailh before, and Gateron didnt fit...
    [cheapino-bottom-right.stl, modules.scad]
2024-12-27 Add 0.4mm screw clearance.
    [modules.scad]
2024-12-27 Increase clearance around encoder.
    [cheapino-top-right.scad]
2024-12-27 Update model.
    [cheapino-bottom-right.stl]
2024-12-28 lowered the bumper position bellow the encoder on the bottom cases increased the depth of the enconder holes on the bottom cases
    [cheapino-bottom-left.scad, cheapino-bottom-right.scad, modules.scad]
2024-12-28 removed unwanted config
    [cheapino-bottom-right.scad]
2024-12-28 normalized import
    [cheapino-bottom-right.scad]
2025-01-06 fix(case): deeper hole for encoder clamp
    [modules.scad]
2025-01-06 fix(case): faster preview
    [cheapino-bottom-left.scad, cheapino-bottom-right.scad, cheapino-top-left.scad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]
2025-01-18 Increased hotswap cutouts to also fit otemu sockets
    [cheapino-bottom-left.scad, cheapino-bottom-right.scad, cheapino-bottom-right.stl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]
2025-01-21 Smaller step
    [cheapino-top-left.scad, cheapino-top-right.scad]
2025-01-26 Remove low profile socket from ordering guide.
    This socket seems to create a lot of problems.
    (suspect thick legs needed require more heat and might break mcu...)
    Also replaced broken diode link
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2025-04-24 Top and bottom PCB plates
    [pcb-bottom.kicad_pcb, pcb-top.kicad_pcb, pcb-top.kicad_sch]
2025-04-24 Remove top plate schematic
    [pcb-top.kicad_sch]
2025-04-24 Unhide random value label
    [pcb-bottom.kicad_pcb]
2025-05-21 Increase hotswap sockets and move encoder cutout
    [cheapino-top-right.scad, modules.scad]
2025-05-22 Revert top plate design to thinner outline
    [pcb-top.kicad_pcb]
2025-07-23 PCB Blueprint Advice & RJ45 Improve Spec
    Added a note about how the white outlines/blueprint of the PCB work. Also added a note for the RJ45 socket to make it more accurate.
2025-08-22 Add warning about resin SLA printing with heat inserts
    Resin degrades instead of melting when heated, making it incompatible
    with heat insert installation. Added warning to use FDM printing instead.
    Closes #151
2025-08-22 Add Cheapino v1 with green switches to gallery
    Added image from #145 showing a v1 build with green switches.
2025-08-22 Add note about mag-safe stand availability
    Added clarification that the specific tenting stand may not be available in all countries, but any stand with mag-safe connector and heavy base will work.
    Fixes #137
2026-03-15 Added minimal plate, as requested in #165
    [minimal-plate.scad]
